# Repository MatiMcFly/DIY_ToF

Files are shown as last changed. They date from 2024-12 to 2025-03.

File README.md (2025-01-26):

# DIY ToF

Copyright (c) 2024-2025 Matthias Schär, Timon Burkard

This project is about creating a DIY (Do-It-Yourself) optical ToF (Time of Flight) distance measurement system.

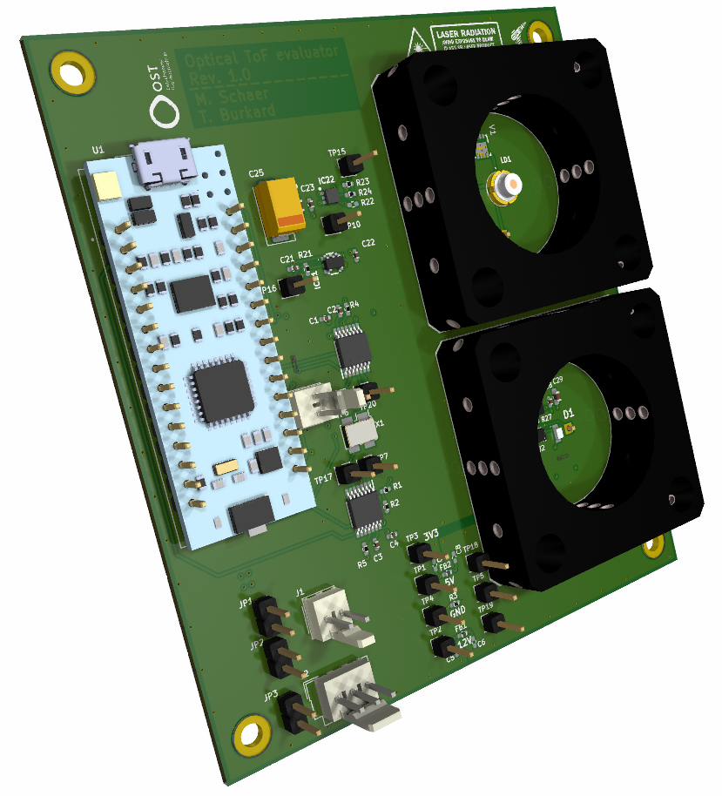
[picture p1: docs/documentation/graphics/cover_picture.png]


It is a project work as part of the CAS (Certificate of Advanced Studies) in Sensors and Sensor Signal Conditioning, which is held at OST (Ostschweizer Fachhochschule) in Rapperswil CH.

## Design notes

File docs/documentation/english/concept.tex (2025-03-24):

The following subchapters explain the development work necessary for the implementation of the \acrshort{tof} demonstrator.
In particular, they discuss how the electronics can be constructed. In addition, further
challenges of such a system and how they can be overcome are shown.

\subsection{Signal chain}

Some explanations can be found below on how the \acrshort{tof} measurement is realized.

A block diagram of the overall project, consisting of the electrical and the optical part, is shown in
Figure~\ref{fig:blockdiagram}.

\begin{figure}[H]
    \centering
    
    \caption{Block diagram}\label{fig:blockdiagram}
\end{figure}

A more detailed sketch of the optical signal chain can be seen in the figure~\ref{fig:konzept_signalpfad}.

\begin{figure}[H]
    \centering
    
    \caption{Conceptual signal path}\label{fig:konzept_signalpfad}
\end{figure}

An \acrshort{mcu} takes care of starting and evaluating the measurement results. Generating a start signal
a laser diode is triggered by a laser driver. This pulse, in the form of a light pulse after the laser diode,
is then reflected by a target that is at a variable distance from the electronics.

The reflected light pulse is focused by an optical system and then converted into a photocurrent. This photocurrent is
converted into a voltage by a transimpedance amplifier. Before the \acrshort{mcu} can evaluate this voltage, it must
first be digitized. This is done using a comparator. This can be understood as a 1-bit \acrshort{adc}, since only a
distinction between the two states \dq light\dq\ and \dq no light\dq\ is necessary. The result is a received pulse.

If the time between the start signal and the received pulse is measured, it is possible to draw a conclusion about the variable
distance between the electronics and the target. The time measurement is subject to the highest requirements. As
symbolization: light travels a distance of 30 cm within a nanosecond. The next subchapter explains how such a time measurement
can be realized.

\subsection{Time measurement}

In order for a direct \acrshort{tof} signal to be evaluated, it requires a high-resolution
time measurement. The TDC7200 from Texas Instruments offers a good solution for this.
According to the data sheet \cite{ti2016tdc7200_datasheet}, it can resolve up to 55 ps with a
standard deviation of 35 ps. If we now insert the speed of light and this minimum
temporal resolution in a motion equation, the module should achieve the following spatial resolution according to the formula~\ref{eq:tdc_max_resolution}:

\begin{equation}\label{eq:tdc_max_resolution}
    s_{min} = c \cdot t = 299.8 \cdot 10^6~\frac{m}{s} \cdot 55~ps = 16.5~mm
\end{equation}
\myequations{Maximum spatial resolution of the TDC7200}

In principle, the \acrshort{tof} functionality should be put into operation in two steps.
In the first part, the aim is purely to get to know the TDC7200 \acrshort{ic} better.

Note: In reality, such a resolution will not be achievable. The challenges
consist, for example, in the fact that various delays are present in the entire signal chain.
For example, the switching on of the laser diode, the bandwidth of the amplifier and
the switching time of the comparator play a major role. Also, the jitter of the \acrshort{mcu} when switching on and off
of their outputs will be important at the minimum resolution. In the chapter~\ref{sec:electrical_measurements},
various measurements are used to show how close the TDC7200's specified limit is approached.

\subsection{Approach}\label{sec:approach}

As already explained, it can be assumed that the entire signal path introduces an inaccuracy into the measurement that
is far outside that of the TDC7200. It therefore makes sense to examine this in advance.
For this purpose, a second TDC7200 is used on the electronics, which is responsible for measuring a purely electrical signal
.
\begin{figure}[H]
    \centering
    
    \caption{Concept operation \acrshort{tdc} purely electric}\label{fig:konzept_tdc_electrical}
\end{figure}

Figure~\ref{fig:konzept_tdc_electrical} shows a possible design for such a circuit. The wavy
red line symbolizes a variable measurement path. Cables of different lengths can be connected here via a plug.
This makes it possible to verify the measurement accuracy of the TDC7200 purely electrically.

The following points can be checked with such an extension:

\begin{itemize}
    \item Measurement of jitter at the \acrshort{mcu} outputs
    \item Configuration and operation of the TDC7200 (e.g. different measurement modes)
    \item Evaluation of the TDC7200 results
\end{itemize}

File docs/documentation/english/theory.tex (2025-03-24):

The following subchapters develop the theoretical foundations necessary for understanding and
designing a demonstrator for the \acrshort{tof} method.

\subsection{Time of Flight}

The measurement method known as \dq \acrlong{tof}\dq\ involves measuring the transit time of a signal.
The signal can be either optical or acoustic. One application of this is, for example, distance measurement.

In the optical principle discussed here, a transmitter emits light that is detected by a receiver.
A time measurement can be made between the sending and receiving of the signal. Because light propagates at a defined
speed, this time measurement can be used to determine the distance
the signal has traveled within the measured time.

\begin{figure}[H]
    \centering
    
    \caption{Visualization of a: direct \acrshort{tof} and b: indirect \acrshort{tof}}\label{fig:dtof_vs_itof}
\end{figure}

There are two types of \acrshort{tof}: direct \acrshort{tof} (dToF) and indirect \acrshort{tof} (iToF). With dToF
only the time between the transmission and reception pulse is determined. In the figure~\ref{fig:dtof_vs_itof},
such pulses are shown at a).

In iToF, the phase shift of a modulated light signal is also measured (in some cases additionally) to the runtime measurement.
This is shown in figure~\ref{fig:dtof_vs_itof} in part b). This method allows higher resolutions to
be achieved, but is much more complex in terms of evaluation and signal processing.

This work is limited to the direct \acrshort{tof} method.

In the following, the theoretical principles, especially with regard to designing a suitable optical system, are discussed.

\pagebreak

\subsection{Photocurrent}

To calculate the theoretically expected photocurrent, a distance of $10~m$ from the wall is assumed.

In a simplified consideration, a laser beam with a divergence of $0\degree$ hits a wall at right angles
and is scattered uniformly in a hemisphere. In reality, the laser will not hit the wall at $0\degree$ and
the scattering will not be uniform, but rather more concentrated in the center.

The calculation of the received radiant power, the radiant intensity, the solid angle of a hemisphere, and the
photocurrent are shown in formulas~\ref{eq:pin}, \ref{eq:ie}, \ref{eq:omega} and \ref{eq:iph}, respectively.

\begin{equation}\label{eq:pin}
    P_{in} = E_e \cdot A = \frac{I_e}{r^2} \cdot A
\end{equation}
\myequations{Incoming light power}

\begin{equation}\label{eq:ie}
    I_e = \frac{P_{out}}{\Omega}
\end{equation}
\myequations{Radiation intensity}

\begin{equation}\label{eq:omega}
    \Omega = 4\cdot \pi \cdot 0.5
\end{equation}
\myequations{solid angle}

\begin{equation}\label{eq:iph}
    I_{ph} = S \cdot P_{in}
\end{equation}
\myequations{photocurrent}

\subsubsection{Calculation with RLD94PZJ5 and BPV23NF}

Initial calculations are carried out with the RLD94PZJ5 laser diode \cite{rohm2020rld94pzj5_datasheet} and the BPV23NF photodiode
\cite{vishay2024bpv23nf_datasheet}.

The relevant values from the data sheets are listed in formula~\ref{eq:rld94pzj5_num} and \ref{eq:rbpv23nf_num}.

\begin{equation}\label{eq:rld94pzj5_num}
    P_{out} = 285~mW
\end{equation}
\myequations{Values of the RLD94PZJ5}

\begin{equation}\label{eq:rbpv23nf_num}
    \begin{split}
        A & = 4.4~mm^2        \\
        S & = 0.6~\frac{A}{W}
    \end{split}
\end{equation}
\myequations{Values of BPV23NF}

These values inserted in formula~\ref{eq:ie}, \ref{eq:pin} and \ref{eq:iph} yield the results in
formula~\ref{eq:rld94pzj5_rbpv23nf_num}.

\begin{equation}\label{eq:rld94pzj5_rbpv23nf_num}
    \begin{split}
        I_e    & = \frac{P_{out}}{\Omega} = \frac{285~mW}{4\cdot \pi \cdot 0.5~sr} = 45.4~\frac{mW}{sr} \\
        P_{in} & = \frac{I_e}{r^2} \cdot A = \frac{45.4~\frac{mW}{sr}}{(10~m)^2} \cdot 4.4~mm^2 = 2~nW  \\
        I_{ph} & = S \cdot P_{in} = 0.6~\frac{A}{W} \cdot 2~nW = 1.2~nA
    \end{split}
\end{equation}
\myequations{Numerical results with RLD94PZJ5 and BPV23NF}

\subsubsection{Calculation with RLD65NZX1 and NJL6401R-3}

The laser diode RLD94PZJ5 has two disadvantages with regard to this project work: on the one hand, it has such a high power that
it can be harmful to the human eye. On the other hand, it emits in a wavelength range that
is not visible to the human eye.

For these reasons, a second laser diode is being evaluated: RLD65NZX1 \cite{rohm2019rld65nzx1_datasheet}. It is paired
with the photodiode NJL6401R-3 \cite{jrc2014njl6401r3_datasheet}. The following calculations are based on
these two components.

The relevant values from the data sheets are listed in formula~\ref{eq:rld65nzx1_num} and \ref{eq:njl6401r3_num}.

\begin{equation}\label{eq:rld65nzx1_num}
    P_{out} = 10~mW
\end{equation}
\myequations{Values of the RLD65NZX1}

\begin{equation}\label{eq:njl6401r3_num}
    \begin{split}
        A & = 0.7~mm \cdot 0.7~mm = 0.49~mm^2 \\
        S & = 0.42~\frac{A}{W}
    \end{split}
\end{equation}
\myequations{Values of NJL6401R-3}

Inserted into the formulas~\ref{eq:ie}, \ref{eq:pin} and \ref{eq:iph} the new results in
formula~\ref{eq:rld65nzx1_njl6401r3_num}.

\begin{equation}\label{eq:rld65nzx1_njl6401r3_num}
    \begin{split}
        I_e    & = \frac{P_{out}}{\Omega} = \frac{10~mW}{4\cdot \pi \cdot 0.5~sr} = 1.59~\frac{mW}{sr}    \\
        P_{in} & = \frac{I_e}{r^2} \cdot A = \frac{1.59~\frac{mW}{sr}}{(10~m)^2} \cdot 0.49~mm^2 = 7.8~pW \\
        I_{ph} & = S \cdot P_{in} = 0.42~\frac{A}{W} \cdot 7.8~pW = 3.28~pA
    \end{split}
\end{equation}
\myequations{Numerical results with RLD65NZX1 and NJL6401R-3}

\subsubsection{Calculation with receiving lens}

At the suggestion of the lecturers, various optics from a modular system from QIOPTIQ are being tried out.
A lens with a diameter of 17~mm and a focal length of
40~mm appears to be particularly promising. The lens is shown in Figure~\ref{fig:lens}.

\begin{figure}[H]
    \centering
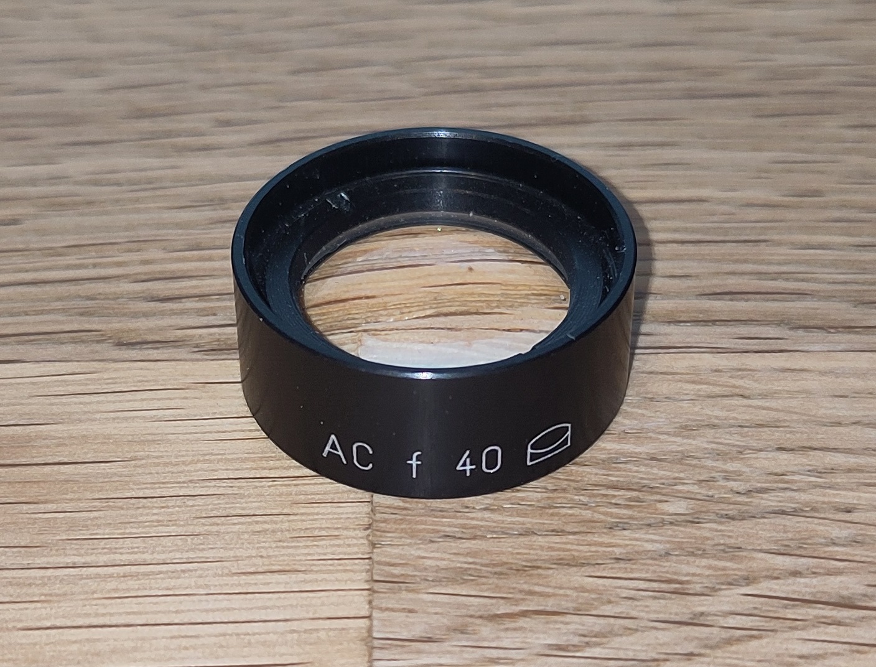
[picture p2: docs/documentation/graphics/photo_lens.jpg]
    
    \caption{Lens from QIOPTIQ}\label{fig:lens}
\end{figure}

This lens enlarges the effective area on which the photocurrent can be received. This results in
higher reception power, i.e. a higher photocurrent.
The formula~\ref{eq:njl6401r3_lens} shows the increase in area to be expected when using such an optical system.

\begin{equation}\label{eq:njl6401r3_lens}
    A' = \frac{A_{L}}{A_{PD}} = \frac{(\frac{17~mm}{2})^2 \cdot \pi}{0.49~mm^2} = 463.2
\end{equation}
\myequations{Magnification of the receiving area by lens}

\subsubsection{Expected photocurrent}

Two scenarios are considered below: In the first, it is assumed, as before, that the light from the laser
propagates in a focused beam and then reflects off the target in a hemispherical and diffuse manner.

In the second scenario, an attempt is made to model the radiation pattern of the laser diode. According to the data sheet, the
diode has two different beam angles in the beam plane, which can be approximated with the solid angle of a rectangular pyramid.
Scattering is prevented because the beam is reflected by a mirror.

In both scenarios, the radiated power of the laser diode is higher than in the first calculation. In pulsed
operation, this can easily be increased above the maximum rating. Thermally, this does not pose a problem for the diode because
the duty cycle is very small. The formula~\ref{eq:rld65nzx1_higher_output} shows the new expected radiant power
of such a pulse. The efficiency of the laser diode is taken from the RLD65NZX1 data sheet \cite{rohm2019rld65nzx1_datasheet}.

\begin{equation}\label{eq:rld65nzx1_higher_output}
    \begin{split}
        \eta     & = \frac{P_{25~mA}}{I_{ld}} = \frac{7~mW}{25~mA} = 0.28~\frac{W}{A}   \\
        I_{ld}'  & = \frac{5~V - V_{LD}}{R_{v}} = \frac{5~V - 2.8~V}{5~\Omega} = 440~mA \\
        P_{out}' & = \eta \cdot I_{ld}' = 0.28~\frac{W}{A} \cdot 440~mA = 123~mW
    \end{split}
\end{equation}
\myequations{Increased transmission power of the laser diode}

For a target located at a distance of 2 meters, the following
photocurrent can be expected according to formula~\ref{eq:photocurrent_scenario1}:

\begin{equation}\label{eq:photocurrent_scenario1}
    \begin{split}
        P_{in} & = \frac{P_{out}}{\Omega \cdot r^2} \cdot A_{L} = \frac{123~mW}{4\pi \cdot 0.5~sr \cdot (2~m)^2} \cdot 227~mm^2 = 1.11~\mu W \\
        I_{ph} & = S \cdot P_{in} = 0.42~\frac{A}{W} \cdot 1.11~\mu W = 467~nA
    \end{split}
\end{equation}
\myequations{Photocurrent scenario 1}

Without optics, the laser diode does not emit a collimated beam. In the second scenario, this radiation pattern is modeled using
the solid angle of a pyramid, as defined in formula~\ref{eq:solid_angle_pyramid}. The typical
radiation angles $\theta$ are also taken from the laser diode data sheet. It should be noted that the
full angle is given in the data sheet. The value in the formula is therefore halved.

\begin{equation}\label{eq:solid_angle_pyramid}
    \Omega_{P} = 4 \cdot arcsin(sin(\theta_x) \cdot sin(\theta_y)) =  4 \cdot arcsin \parenth*{sin \parenth*{\frac{9\degree}{2}} \cdot sin \parenth*{\frac{29\degree}{2}}} = 4.2~sr
\end{equation}
\myequations{Laser diode radiation model}

The formula~\ref{eq:photocurrent_scenario2} is used again to calculate the expected received power and the corresponding
photocurrent. However, the difference to the previous calculation is that the solid angle must also be
taken into account before reflection. Therefore, the distance to the target is multiplied by two.

\begin{equation}\label{eq:photocurrent_scenario2}
    \begin{split}
        P_{in} & = \frac{P_{out}}{\Omega \cdot (2 \cdot r)^2} \cdot A_{L} = \frac{123~mW}{4.2~sr \cdot (2 \cdot 2~m)^2} \cdot 227~mm^2 = 416~nW \\
        I_{ph} & = S \cdot P_{in} = 0.42~\frac{A}{W} \cdot 416~nW = 175~nA
    \end{split}
\end{equation}
\myequations{Photocurrent scenario 2}

\pagebreak

\subsection{Transimpedance amplifier}

As the calculations in the previous chapters show, the photocurrents to be detected have very small
amplitudes. Furthermore, the light pulses are typically only of very short duration, namely in the range of a few nanoseconds.
As a result, the signals have correspondingly short rise times, which need to be detected.

The requirements indicate that an amplifier with a very high gain and a very high bandwidth must be used.
The amplifier circuit used is a current-to-voltage converter. Such a circuit of the operational amplifier,
as shown in Figure~\ref{fig:theory_tia}, is also called a transimpedance amplifier (\acrshort{tia}).

\begin{figure}[H]
    \centering
    
    \caption{Operational amplifier circuit as a \acrshort{tia}}\label{fig:theory_tia}
\end{figure}

As the name suggests, the transimpedance converter converts the photocurrent \lstinline|Id| into a voltage \lstinline|Vout|.
The feedback resistor \lstinline|Rf| determines the amplification factor, as the formula~\ref{eq:tia_simple}
shows:

\begin{equation}\label{eq:tia_simple}
    V_{out} = -R_{f} \cdot I_{d}
\end{equation}
\myequations{Übertragungsfunktion \acrshort{tia}}

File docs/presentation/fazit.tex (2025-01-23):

\begin{frame}{Ausblick}
    \begin{itemize}
        \item Optik besser aufeinander abstimmen, andere Brennweiten ausprobieren
        \item Jitter minimieren (höherer Clock oder externen Clock)
        \item GPIOs schneller schalten
        \item Optischer Empfangspfad
        \begin{itemize}
            \item Unterschiedliche Verstärkungen TIA
            \item Unterschiedliche Schaltschwellen Komparator
        \end{itemize}
        \item Optischer Sendepfad: Höhere Sendeleistung ausprobieren
        \item Analyse optischer Resultate: Wieso zwei Cluster?
        \item Mechanischen Versuchsaufbau für Spiegel
    \end{itemize}
\end{frame}

\begin{frame}{Lessons Learned}
    \begin{itemize}
        \item Insgesamt sehr zufrieden
        \item Viel Neues gelernt
        \item Leider etwas wenig Zeit
        \item Zeitliche Auflösung weniger ein Problem als empfangene Lichtmenge
        \item[$\Rightarrow$] Mehr Zeit in Optik und Optoelektronik investieren
    \end{itemize}
\end{frame}

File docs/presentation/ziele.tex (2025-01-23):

\begin{frame}{Zielsetzung}
    \begin{itemize}
        \item ToF-Demonstrator entwickeln
        \begin{itemize}
            \item Eigenes PCB mit 2x TDC7200
        \end{itemize}
        \item Erster Schritt: Kabellängen vermessen
        \item Zweiter Schritt: Optische Messung
        \begin{itemize}
            \item Distanz: 10 m
            \item Auflösung: 30 cm
        \end{itemize}
    \end{itemize}
\end{frame}

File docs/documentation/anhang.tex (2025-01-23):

\subsection{Outline}\label{sec:outline}

\begin{figure}[H]
    \centering
    
    \caption{Outline}\label{fig:outline}
\end{figure}

\subsection{TDC Treiber}\label{sec:tdc_driver}

In Code~\ref{code:tdc_driver_header} und \ref{code:tdc_driver_source} ist der selbst entwickelte Firmware-Treiber für
den \acrshort{tdc} dargestellt.

\lstinputlisting[language={c}, label={code:tdc_driver_header}, caption={\acrshort{tdc} Driver (Header)}]{../../firmware/Core/TDC/TDC.h}
\lstinputlisting[language={c}, label={code:tdc_driver_source}, caption={\acrshort{tdc} Driver (Source)}]{../../firmware/Core/TDC/TDC.c}

\subsection{Python Skripte}\label{sec:python_scripts}

In Code \ref{code:python_analyze} ist das Python-Skript zur Berechnung des arithmetischen Mittelwerts und der
Standardabweichung sowie zum Plotten des Histogramms und des Boxplots dargestellt.

\lstinputlisting[language={python}, label={code:python_analyze}, caption={Python Analyse}]{../../utilities/analyze-tof.py}

In Code \ref{code:python_analyze_multi_tofs} ist das Python-Skript zur Berechnung des arithmetischen Mittelwerts und der
Standardabweichung sowie zum Plotten der Werte für mehrere \acrshort{tof}-Datensätze dargestellt.

\lstinputlisting[language={python}, label={code:python_analyze_multi_tofs}, caption={Python Analyse (Multi \acrshort{tof}s)}]{../../utilities/analyze-tofs.py}

In Code \ref{code:python_analyze_multi_logs} ist das Python-Skript zum Plotten der Werte aus mehreren Log-Files
dargestellt.

\lstinputlisting[language={python}, label={code:python_analyze_multi_logs}, caption={Python Analyse (Multi Logs)}]{../../utilities/analyze-tofs-multi-logs.py}

In Code \ref{code:python_live_plot} ist das Python-Skript zum live Plotten von \acrshort{tof}-Werte dargestellt. Dieses
wird während der Präsentation für die Demonstration verwendet.

\lstinputlisting[language={python}, label={code:python_live_plot}, caption={Python Live Plot}]{../../utilities/live-plot.py}

\pagebreak

\begin{landscape}

    \subsection{Schema}\label{sec:schematic_apdx}
    \global\pdfpageattr\expandafter{\the\pdfpageattr/Rotate 90}
    \begin{figure}[H]
        \centering
        
        \caption{Schema S.1/3}\label{fig:schematics_1}
    \end{figure}
    \pagebreak

    \global\pdfpageattr\expandafter{\the\pdfpageattr/Rotate 90}
    \begin{figure}[H]
        \centering
        
        \caption{Schema S.2/3}\label{fig:schematics_2}
    \end{figure}
    \pagebreak

    \global\pdfpageattr\expandafter{\the\pdfpageattr/Rotate 90}
    \begin{figure}[H]
        \centering
        
        \caption{Schema S.3/3}\label{fig:schematics_3}
    \end{figure}
    \pagebreak

    \subsection{Stückliste}

    \begin{table}[H]
        \scriptsize
        \mytable
            {|l|l|l|l|l|l|}
            {\textbf{Reference} & \textbf{Value} & \textbf{Datasheet} & \textbf{Footprint} & \textbf{Qty} & \textbf{DNP}}
            {\Reference & \Value & \Datasheet & \Footprint & \Qty & \DNP}
            {tables/bom.csv}
        \caption{Bill of Material}\label{tab:bom}
    \end{table}

\end{landscape}
\global\pdfpageattr\expandafter{\the\pdfpageattr/Rotate 0}

\subsection{Layout}\label{sec:apdx_layout}

\begin{figure}[H]
    \centering
    
    \caption{PCB Layout Top}\label{fig:apdx_pcb_f_cu}
\end{figure}

\begin{figure}[H]
    \centering
    
    \caption{PCB Layout Innen 1}\label{fig:apdx_pcb_in1_cu}
\end{figure}

\begin{figure}[H]
    \centering
    
    \caption{PCB Layout Innen 2}\label{fig:apdx_pcb_in2_cu}
\end{figure}

\begin{figure}[H]
    \centering
    
    \caption{PCB Layout Bottom}\label{fig:apdx_pcb_b_cu}
\end{figure}

\subsection{Komponenten-Platzierung}\label{sec:apdx_placement}

\begin{figure}[H]
    \centering
    
    \caption{PCB Komponenten-Platzierung Top}\label{fig:apdx_pcb_placement_1}
\end{figure}

\begin{figure}[H]
    \centering
    
    \caption{PCB Komponenten-Platzierung Bottom}\label{fig:apdx_pcb_placement_2}
\end{figure}
\pagebreak

\subsection{3D View}\label{sec:apdx_3D_view}

\begin{figure}[H]
    \centering
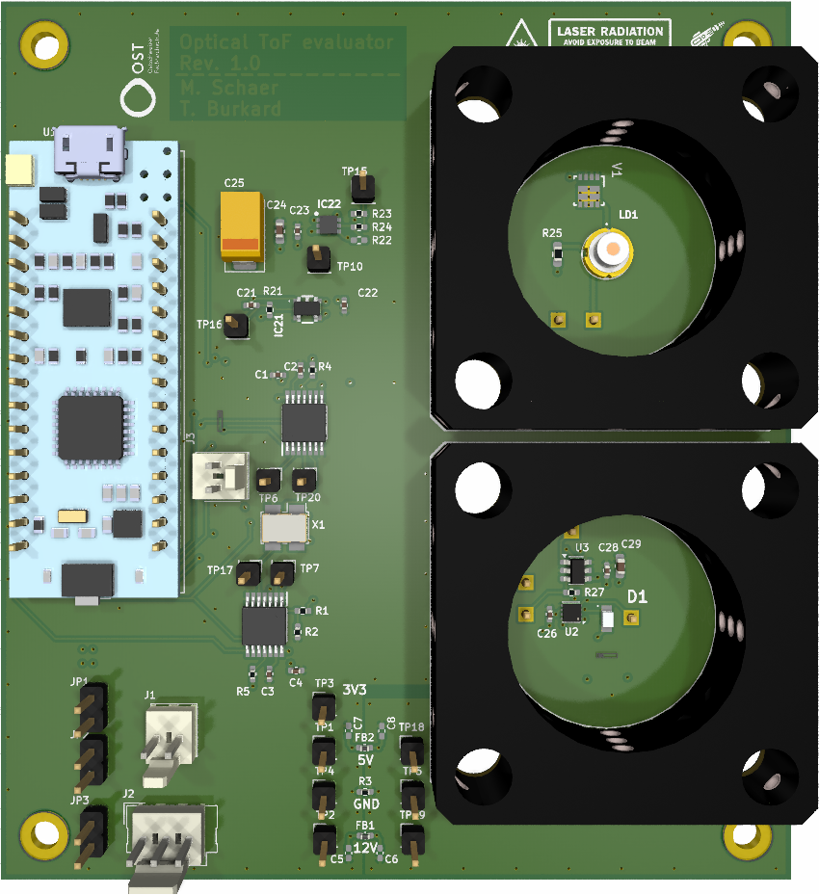
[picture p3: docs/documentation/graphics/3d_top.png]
    
    \caption{3D View Top}\label{fig:apdx_3d_top}
\end{figure}

\begin{figure}[H]
    \centering
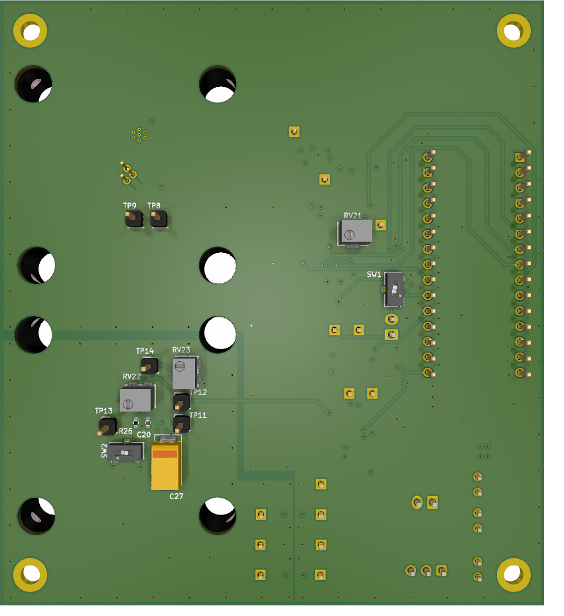
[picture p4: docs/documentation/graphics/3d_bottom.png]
    
    \caption{3D View Bottom}\label{fig:apdx_3d_bottom}
\end{figure}

\subsection{Fotos Demonstrator}\label{sec:apdx_photos_demonstrator}

\begin{figure}[H]
    \centering
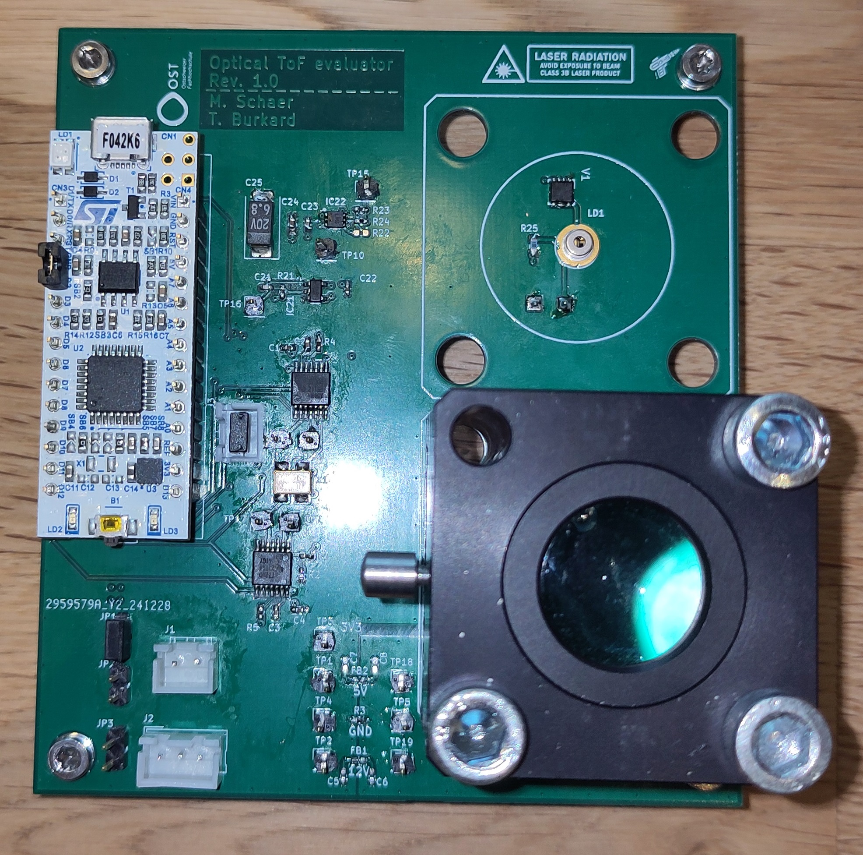
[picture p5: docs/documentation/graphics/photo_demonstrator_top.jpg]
    
    \caption{Demonstrator von oben}\label{fig:apdx_photo_demonstrator_top}
\end{figure}

\begin{figure}[H]
    \centering
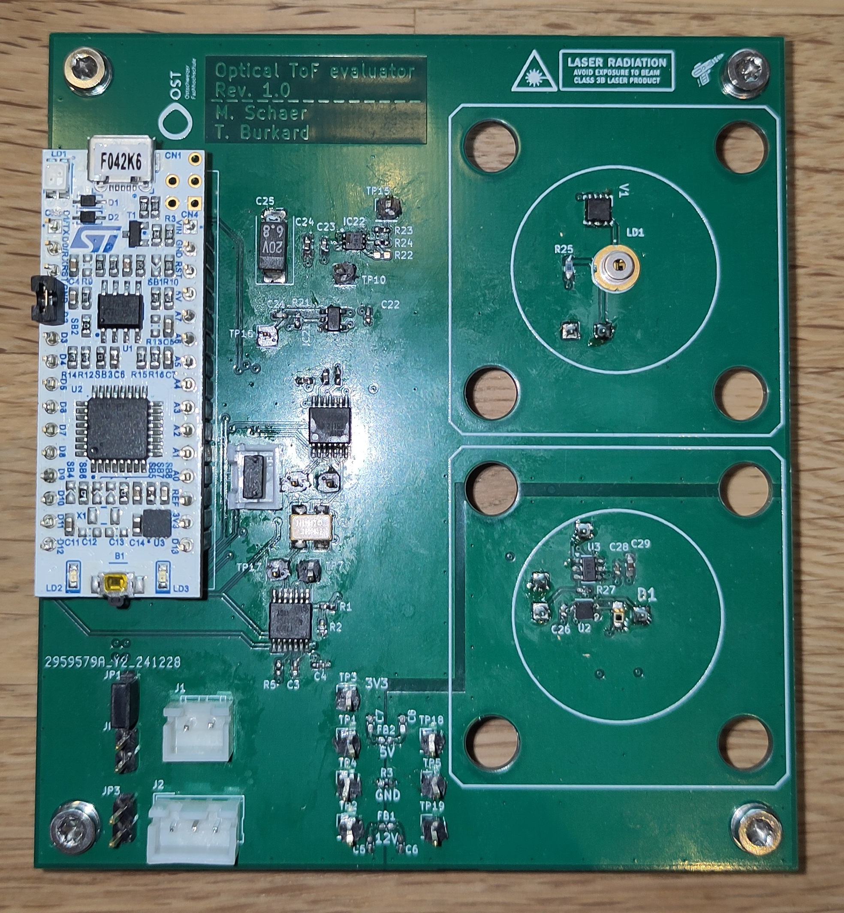
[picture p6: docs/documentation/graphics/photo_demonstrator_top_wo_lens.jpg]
    
    \caption{Demonstrator von oben ohne Linse}\label{fig:apdx_photo_demonstrator_top_wo_lens}
\end{figure}

\begin{figure}[H]
    \centering
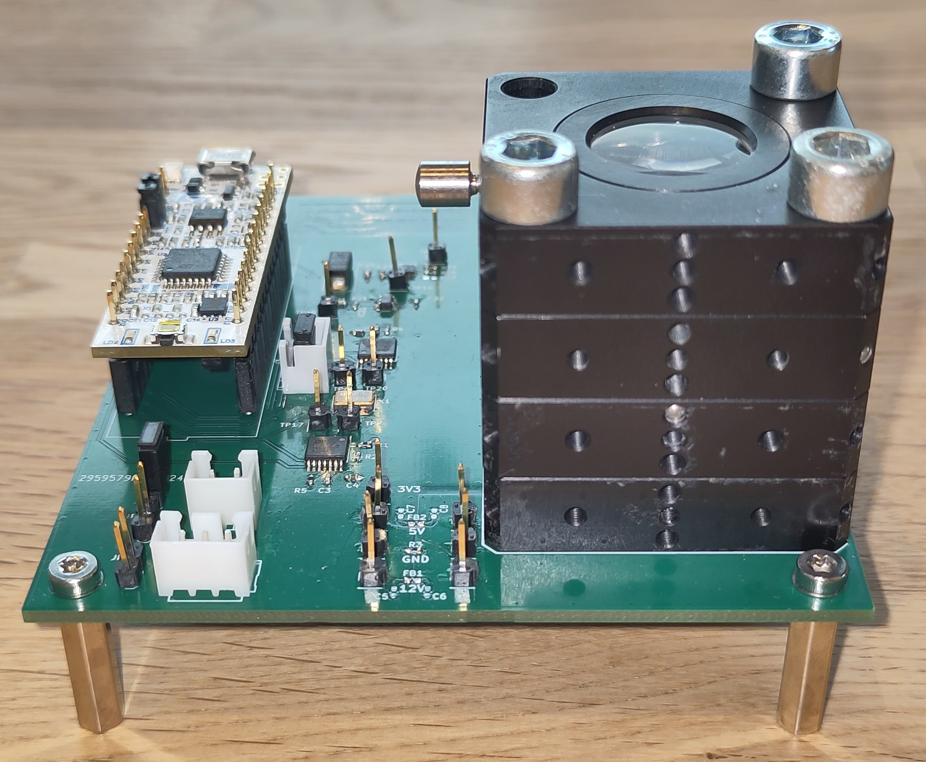
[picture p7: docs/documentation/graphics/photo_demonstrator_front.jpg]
    
    \caption{Demonstrator von vorne}\label{fig:apdx_photo_demonstrator_front}
\end{figure}

\begin{figure}[H]
    \centering
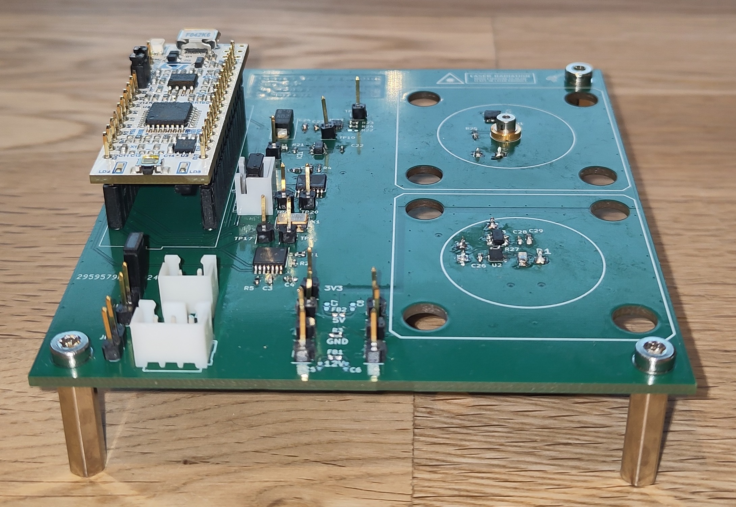
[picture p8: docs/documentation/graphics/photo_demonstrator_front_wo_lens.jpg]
    
    \caption{Demonstrator von vorne ohne Linse}\label{fig:apdx_photo_demonstrator_front_wo_lens}
\end{figure}

\begin{figure}[H]
    \centering
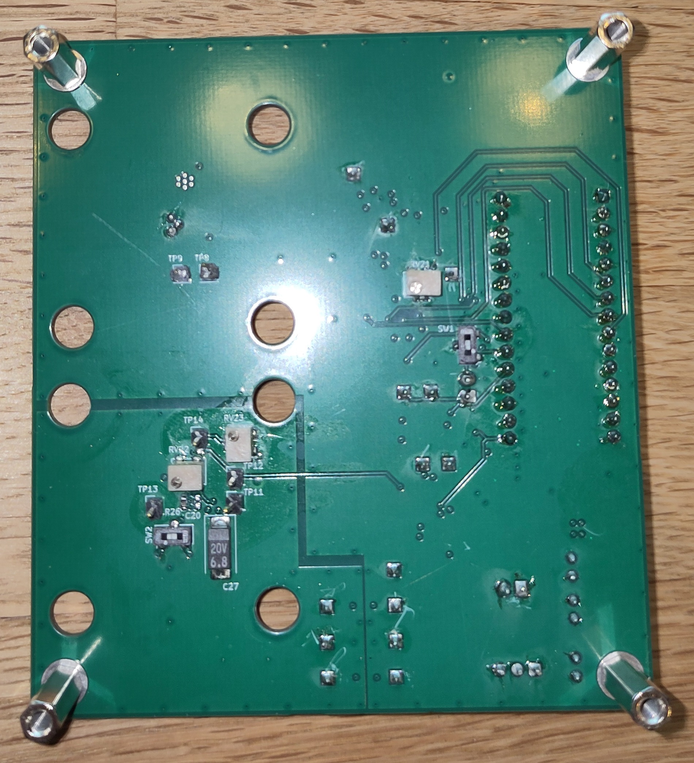
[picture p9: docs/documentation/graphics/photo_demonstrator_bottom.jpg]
    
    \caption{Demonstrator von unten}\label{fig:apdx_photo_demonstrator_bottom}
\end{figure}

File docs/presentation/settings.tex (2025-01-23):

\usetheme{Frankfurt}
\usecolortheme{default}

\usepackage[ngerman]{babel}
\usepackage[square,numbers,super]{natbib}
\usepackage{listings}
\usepackage{textpos}
\usepackage{tabto}
\usepackage{caption}
\usepackage{fbox}                     % to add border to figures, if needed
\usepackage{tikz}                     % to place red rounded boxes to highlight spots
\usepackage{xcolor}
\usepackage{xpatch}                   % to add grey background to \lstinline
\usepackage{realboxes}                % to add grey background to \lstinline
\usepackage{calc}                     % used for \rightHeaderWidth
\usepackage{varwidth}                 % used for \rightHeaderWidth
\usepackage{lmodern}                  % used for \setlistspacing
\usepackage[export]{adjustbox}        % used to left/right align graphics in a figure
\usepackage[normalem]{ulem}           % used to strike through text: \sout{}
\usepackage[inkscapelatex=false]{svg} % used to include svg with the help of inkscape which converts svg to pdf (inkscapelatex=false: prevent latex from changing the font within the svg graphic)
\usepackage[loop,autoplay]{animate}   % used to insert GIF animations with the help op ImageMagick which converts gif to multiple png
\usepackage{mathtools}                % used for DeclarePairedDelimiter
\usepackage{amsmath}                  % needed for amssymb
\usepackage{amssymb}                  % used for \circledast
\usepackage{trfsigns}                 % transformation signs for fourier and laplace
\usepackage{csvsimple}                % for using csv-files for tables

\makeatletter
\newcommand{\setlistspacing}[2]{\def\@ld{#1}\expandafter\def\csname
@list\romannumeral\@ld\endcsname{\leftmargin\csname
leftmargin\romannumeral\@ld\endcsname
              \topsep#2
              \parsep0\p@ \@plus\p@
              \itemsep#2}}
\makeatother
\setlistspacing{1}{4ex}

\captionsetup{labelformat=empty,labelsep=none,font=scriptsize} % don't show caption label only caption text

\renewcommand{\bibsection}{} % don't create a section for bibliography

\urlstyle{same} % use text font for URLs
\renewcommand\UrlFont{\color{blue}} % make URLs blue

\definecolor{darkblue}{rgb}{0.05, 0.13, 0.28}
\definecolor{grey}{rgb}{0.4, 0.5, 0.6}
\definecolor{black}{rgb}{0, 0, 0}

\setbeamercolor{palette primary}{bg=darkblue,fg=white}
\setbeamercolor{palette secondary}{bg=darkblue,fg=white}
\setbeamercolor{palette tertiary}{bg=darkblue,fg=white}
\setbeamercolor{palette quaternary}{bg=black,fg=white}
\setbeamercolor{structure}{fg=darkblue} % itemize, enumerate, etc
\setbeamercolor{section in toc}{fg=darkblue}
\setbeamercolor{caption name}{fg=black}

\setbeamercolor{subsection}{bg=grey,fg=white}
\setbeamercolor{subsection in head/foot}{bg=grey,fg=white}

\setbeamertemplate{navigation symbols}{} % hides navigation buttons at bottom

\makeatletter
\setbeamertemplate{footline}
{
    \leavevmode%
    \hbox{%
    \begin{beamercolorbox}[wd=.5\paperwidth,ht=2.25ex,dp=1ex,right]{author in head/foot}%
        \usebeamerfont{author in head/foot}\insertauthor\hspace*{2ex}
    \end{beamercolorbox}%
    \begin{beamercolorbox}[wd=.4\paperwidth,ht=2.25ex,dp=1ex,left]{subsection in head/foot}%
        \hspace*{2ex}\usebeamerfont{title in head/foot}\inserttitle{}
    \end{beamercolorbox}%
    \begin{beamercolorbox}[wd=.1\paperwidth,ht=2.25ex,dp=1ex,right]{subsection in head/foot}%
        \usebeamerfont{title in head/foot}\insertframenumber{} / \inserttotalframenumber\hspace*{2ex}
    \end{beamercolorbox}}%
    \vskip0pt%
}
\makeatother

\setbeamerfont{date}{size=\scriptsize}
\setbeamerfont{institute}{size=\normalfont}
\setbeamerfont{subsection}{size=\large}

\hypersetup{
    colorlinks=true,
    urlcolor=blue,
    linkcolor=.,
    anchorcolor=.,
    citecolor=.,
    filecolor=.
}

\defbeamertemplate*{title page}{customized}[1][]
{
    \begin{beamercolorbox}[sep=8pt,center,shadow=true,rounded=true]{title}
        \usebeamerfont{title}\inserttitle\par%
    \end{beamercolorbox}

    \centering

    \vspace{30pt}

    \usebeamerfont{institute}\insertinstitute\par

    \vspace{10pt}

    \footnotesize{\vModule}

    \vspace{30pt}

    \usebeamerfont{author}\insertauthor\par

    \vspace{40pt}

    \usebeamerfont{date}\insertdate\par
}

\newcommand{\rightHeaderWidth}[0]
{
    \widthof{
        \fbox{
            \begin{varwidth}{\textwidth}
                \tiny{\insertshortinstitute{}}
                \tiny{\vModule}
            \end{varwidth}
        }
    }
}

\addtobeamertemplate{frametitle}{}{%
    \begin{textblock*}{100mm} (153mm-\rightHeaderWidth{},-7.2mm)
        \tiny{\insertshortinstitute{}}
        \vspace{2pt}
        \tiny{\vModule}
    \end{textblock*}}

\AtBeginSection[]{
    \begin{frame}
    \vfill
    \centering
    \begin{beamercolorbox}[sep=8pt,center,shadow=true,rounded=true]{title}
        \usebeamerfont{title}\insertsectionhead\par%
    \end{beamercolorbox}
    \vfill
    \end{frame}
}

\AtBeginSubsection[]{
    \begin{frame}
    \vfill
    \centering
    \begin{beamercolorbox}[sep=8pt,center,shadow=true,rounded=true]{title}
        \usebeamerfont{title}\insertsectionhead\par%
    \end{beamercolorbox}
    \vspace{0.5cm}
    \begin{beamercolorbox}[sep=8pt,center,shadow=true,rounded=true]{subsection}
        \usebeamerfont{subsection}\insertsubsectionhead\par%
    \end{beamercolorbox}
    \vfill
    \end{frame}
}

\setbeamertemplate{frametitle continuation}{} % deactivate roman numbering for frame with [allowframebreaks]

\setbeamercolor{block title}{bg=darkblue,fg=white}

\newcommand{\question}[1]
{
    \begin{block}{Frage}
        #1
    \end{block}
}

\newcommand{\attention}[1]
{
    \begin{alertblock}{Wichtig}
        #1
    \end{alertblock}
}

\newcommand{\exercise}[2][n]
{
    \begin{exampleblock}{Übung}
        #2
    \end{exampleblock}

    \ifx #1n
    \else
        \begin{itemize}
            \item<2->[$\Rightarrow$] Lösungen werden via GitLab zur Verfügung gestellt:
            \url{#1}
        \end{itemize}
    \fi
}

\renewcommand{\quote}[3]
{
    \begin{frame}{#1}
        \begin{block}{}
            {\emph{\dq #2\dq}}
            \vskip5mm
            \hspace*\fill{\small-- #3}
        \end{block}
    \end{frame}
}

\newcommand{\goals}[1]
{
    {
        \setlistspacing{1}{1ex}

        \begin{frame}{Ziele}
            Die Studierenden

            \begin{itemize}
                #1
            \end{itemize}

            \vspace{10pt}

            \begin{figure}
                
            \end{figure}
        \end{frame}
    }
}

\newcommand{\questions}[0]
{
    \begin{frame}{Fragen?}
        \begin{figure}
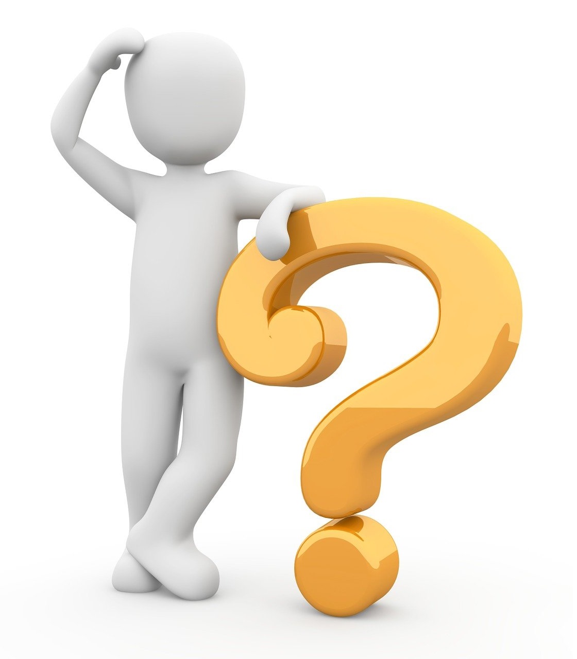
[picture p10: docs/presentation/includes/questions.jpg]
            
        \end{figure}
    \end{frame}
}

\definecolor{codegreen}{rgb}{0,0.6,0}
\definecolor{codegray}{rgb}{0.5,0.5,0.5}
\definecolor{codepurple}{rgb}{0.58,0,0.82}
\definecolor{codeorange}{rgb}{1,0.5,0.15}
\definecolor{backcolour}{rgb}{0.9,0.9,0.9}

\colorlet{codegreen_transparent}{codegreen!30}
\colorlet{codegray_transparent}{codegray!30}
\colorlet{codepurple_transparent}{codepurple!30}
\colorlet{codeorange_transparent}{codeorange!30}
\colorlet{backcolour_transparent}{backcolour!30}
\colorlet{magenta_transparent}{magenta!30}
\colorlet{red_transparent}{red!30}
\colorlet{black_transparent}{black!30}

\lstdefinestyle{mystyle}{
    language=C,
    backgroundcolor=\color{backcolour},
    commentstyle=\lst@ifdisplaystyle\color{codegreen}\fi, % don't apply for \lstinline
    keywordstyle=\lst@ifdisplaystyle\color{magenta}\fi,   % don't apply for \lstinline
    stringstyle=\lst@ifdisplaystyle\color{codepurple}\fi, % don't apply for \lstinline
    numberstyle=\tiny\color{codegray},
    basicstyle=\ttfamily\scriptsize,
    breakatwhitespace=false,
    breaklines=true,
    captionpos=b,
    keepspaces=true,
    numbers=left,
    numbersep=5pt,
    showspaces=false,
    showstringspaces=false,
    showtabs=false,
    tabsize=4,
    morekeywords={int8_t, uint8_t, int16_t, uint16_t, int32_t, uint32_t, int64_t, uint64_t, bool, true, false},
    moredelim=[is][\color{red}]{§}{§}
}
\lstset{style=mystyle}

\lstset{
    literate={~} {$\sim$}{1},
    breaklines=true,
    breakatwhitespace=true,
    upquote=true, % straight single quotes
}

\lstdefinestyle{transparent}{
    language=C,
    backgroundcolor=\color{backcolour_transparent},
    commentstyle=\lst@ifdisplaystyle\color{codegreen_transparent}\fi, % don't apply for \lstinline
    keywordstyle=\lst@ifdisplaystyle\color{magenta_transparent}\fi,   % don't apply for \lstinline
    stringstyle=\lst@ifdisplaystyle\color{codepurple_transparent}\fi, % don't apply for \lstinline
    numberstyle=\tiny\color{codegray_transparent},
    basicstyle=\ttfamily\scriptsize\color{black_transparent}
    breakatwhitespace=false,
    breaklines=true,
    captionpos=b,
    keepspaces=true,
    numbers=left,
    numbersep=5pt,
    showspaces=false,
    showstringspaces=false,
    showtabs=false,
    tabsize=4,
    morekeywords={int8_t, uint8_t, int16_t, uint16_t, int32_t, uint32_t, int64_t, uint64_t, bool, true, false},
    moredelim=[is][\color{red_transparent}]{§}{§}
}

\newcommand{\sidecaption}[1]
{
    \begin{minipage}{0.05\textwidth}%
        \caption{#1}
    \end{minipage}
}

% \highlight[color]{x1,y1}{x2,y2}
% Places a rounded rectangle at an absolute position on the page.
% Arguments:
%   #1 (optional) - Color of the rectangle (defaults to red)
%   #2            - Coordinates (x,y) of first rectangle corner
%   #3            - Coordinates (x,y) of second rectangle corner
\newcommand{\highlight}[3][red]
{
    \begin{tikzpicture}[overlay]
        \draw[#1, rounded corners, thick] (#2) rectangle (#3) {};
    \end{tikzpicture}
}

% \textbox[color]{x,y}{text}
% Places a text box at an absolute position on the page.
% Arguments:
%   #1 (optional) - Color of the text (defaults to red)
%   #2            - Coordinates (x,y) where the text box should be placed
%   #3            - The text content to display
\newcommand{\textbox}[3][red]
{
    \begin{picture}(0,0)
        \put(#2){\makebox(0,0)[lt]{\textcolor{#1}{#3}}}
    \end{picture}
}

\newcommand{\codehighlight}[5][\ttfamily\scriptsize]
{
    \ifnum#3>1
        \lstinputlisting[firstnumber=1, firstline=1, lastline=\number\numexpr#3-1\relax, language=#2, style=transparent, basicstyle=#1\color{black_transparent}, showlines=true]{#5}
        \vspace{-12pt}
    \fi
    \lstinputlisting[firstnumber=#3, firstline=#3, lastline=#4, language=#2, style=mystyle, basicstyle=#1, showlines=true]{#5}
    \vspace{-12pt}
    \lstinputlisting[firstnumber=\number\numexpr#4+1\relax, firstline=\number\numexpr#4+1\relax, lastline=100, language=#2, style=transparent, basicstyle=#1\color{black_transparent}, showlines=true]{#5}
}

% to be able to remove the final frames (questions, references) from the final section
\makeatletter
\let\beamer@writeslidentry@miniframeson=\beamer@writeslidentry%
\def\beamer@writeslidentry@miniframesoff{%
  \expandafter\beamer@ifempty\expandafter{\beamer@framestartpage}{}% does not happen normally
  {%else
    % removed \addtocontents commands
    \clearpage\beamer@notesactions%
  }
}
\newcommand*{\miniframeson}{\let\beamer@writeslidentry=\beamer@writeslidentry@miniframeson}
\newcommand*{\miniframesoff}{\let\beamer@writeslidentry=\beamer@writeslidentry@miniframesoff}
\makeatother

\newcommand{\mytable}[4]
{
    \centering
    \begin{tabular}{#1}\hline%
        #2 \\ \hline
        \csvreader[
            separator=semicolon,
            head to column names,
            late after line=\\,
        ]{#4}{}{#3}
        \hline
    \end{tabular}
}

\newcommand{\iconelectrical}{
    \begin{tikzpicture}[remember picture, overlay]
        \node at ([xshift=0.8cm, yshift=-2.3cm]current page.north west) {
            \includesvg[width=1cm]{graphics/icon_electrical.svg}
        };
    \end{tikzpicture}
}

\newcommand{\iconoptical}{
    \begin{tikzpicture}[remember picture, overlay]
        \node at ([xshift=0.8cm, yshift=-2.3cm]current page.north west) {
            \includesvg[width=1cm]{graphics/icon_optical.svg}
        };
    \end{tikzpicture}
}

% usable in math mode
\DeclarePairedDelimiter\abs{\lvert}{\rvert}     % make scalable absolute stripes
\DeclarePairedDelimiter\parenth{(}{)}           % make scalable parentheses
\DeclarePairedDelimiter\brackets{[}{]}          % make scalable brackets
\DeclarePairedDelimiter\floor{\lfloor}{\rfloor} % make scalable floor
\DeclarePairedDelimiter\ceil{\lceil}{\rceil}    % make scalable ceil

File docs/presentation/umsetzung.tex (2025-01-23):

\begin{frame}{Blockdiagramm}
    \begin{figure}
        
    \end{figure}

    \onslide<2->{
        \begin{tikzpicture}[remember picture, overlay]
            \node at ([xshift=8.3cm, yshift=-2.6cm]current page.north west) {
                \includesvg[width=1cm]{graphics/icon_electrical.svg}
            };
        \end{tikzpicture}

        \begin{tikzpicture}[remember picture, overlay]
            \node at ([xshift=7.9cm, yshift=-6.4cm]current page.north west) {
                \includesvg[width=1cm]{graphics/icon_optical.svg}
            };
        \end{tikzpicture}
    }
\end{frame}

\begin{frame}{Konzept: Optischer Teil}
    \begin{figure}
        
    \end{figure}

    \iconoptical
\end{frame}

\subsection{Schaltungen}

\begin{frame}{TDC Elektrisch}
    \begin{figure}
        
    \end{figure}

    \iconelectrical
\end{frame}

\begin{frame}{TDC Optisch}
    \begin{figure}
        
    \end{figure}

    \iconoptical
\end{frame}

\begin{frame}{Laser Treiber}
    \begin{figure}
        
    \end{figure}

    \iconoptical
\end{frame}

\begin{frame}{Photo Receiver}
    \begin{figure}
        
    \end{figure}

    \iconoptical
\end{frame}

\begin{frame}{3D View}
    \begin{figure}
        
    \end{figure}
\end{frame}

\begin{frame}{Demonstrator}
    \begin{figure}
        
    \end{figure}
\end{frame}

\subsection{Firmware}

\begin{frame}{Firmware Blockdiagramm}
    \begin{figure}
        
    \end{figure}
\end{frame}

\begin{frame}{Firmware Beispiel: Konfiguration}
    \only<1>{\codehighlight{C}{1}{99}{sourcecode/tdc_example_config.c}}
    \only<2>{\codehighlight{C}{1}{5}{sourcecode/tdc_example_config.c}}
    \only<3>{\codehighlight{C}{7}{13}{sourcecode/tdc_example_config.c}}
\end{frame}

\begin{frame}{Firmware Beispiel: Messung}
    \only<1>{\codehighlight{C}{1}{99}{sourcecode/tdc_example_measure.c}}
    \only<2>{\codehighlight{C}{4}{4}{sourcecode/tdc_example_measure.c}}
    \only<3>{\codehighlight{C}{6}{8}{sourcecode/tdc_example_measure.c}}
    \only<4>{\codehighlight{C}{10}{10}{sourcecode/tdc_example_measure.c}}
    \only<5>{\codehighlight{C}{12}{12}{sourcecode/tdc_example_measure.c}}
\end{frame}

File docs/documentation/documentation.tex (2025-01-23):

\documentclass[11pt,a4paper,hidelinks]{article}

\input{settings.tex}

% Variables
\newcommand{\vTitle}{DIY Optische ToF Distanzmessung}
\newcommand{\vModule}{CAS Sensorik und Sensor Signal Conditioning}
\newcommand{\vAuthorFirstName}{Matthias Schär,}
\newcommand{\vAuthorLastName}{Timon Burkard}
\newcommand{\vUniversity}{OST -- Ostschweizer Fachhochschule}
\newcommand{\vDegree}{CAS Sensorik und Sensor Signal Conditioning}
\newcommand{\vSemester}{HS24}
\newcommand{\vProfessor}{Prof. Guido Keel, Michael Lehmann}
\newcommand{\vCity}{Rapperswil}
\newcommand{\vAbstract}{
    Diese Projektarbeit behandelt die Entwicklung eines \acrfull{diy} Systems zur optischen \acrfull{tof} Distanzmessung.

    Um die Signallaufzeit präzise zu messen, wird ein \acrfull{tdc} eingesetzt. Zu Testzwecken wird ein zweiter
    \acrshort{tdc} verwendet, der rein elektrisch betrieben wird, um die Länge unterschiedlicher Kupferkabel zu
    bestimmen.

    Die Arbeit umfasst die Entwicklung der Hardware, einschließlich Lasertreiber, Photodetektor und
    Transimpedanzverstärker, sowie die Implementierung der Firmware zur Signalauswertung. Simulationen und Messungen
    wurden durchgeführt, um die Genauigkeit zu optimieren und Störfaktoren zu minimieren.

    Die elektrischen Messungen zeigen, dass der \acrshort{tdc} eine zeitliche Auflösung im Bereich einiger Dutzend
    Pikosekunden erreicht. Damit lassen sich Kabellängen auf wenige cm genau bestimmen.

    Die optischen Messungen zeigen, dass eine grobe Distanzmessung bis ca. 30~cm möglich ist, wenn ein Spiegel als
    Target eingesetzt wird. Um die Distanz zu einer Wand messen zu können, sind weiterführende Verbesserungen des
    Demonstrators notwendig.
}

% Acronyms
\newacronym{pcb}{PCB}{Printed Circuit Board}
\newacronym{tof}{ToF}{Time of Flight}
\newacronym{diy}{DIY}{Do It Yourself}
\newacronym{adc}{ADC}{Analog to Digital Converter}
\newacronym{tdc}{TDC}{Time to Digital Converter}
\newacronym{tia}{TIA}{Trans-Impedance Amplifier}
\newacronym{mcu}{MCU}{Microcontroller Unit}
\newacronym{cpu}{CPU}{Central Processing Unit}
\newacronym{hal}{HAL}{Hardware Abstraction Layer}
\newacronym{gpio}{GPIO}{General Purpose Input/Output}
\newacronym{uart}{UART}{Universal Asynchronous Receiver/Transmitter}
\newacronym{dso}{DSO}{Digital Storage Oscilloscope}
\newacronym{spi}{SPI}{Serial Peripheral Interface}
\newacronym{ic}{IC}{Integrated Circuit}
\newacronym{usb}{USB}{Universal Serial Bus}
\newacronym{hsi}{HSI}{High Speed Internal}
\newacronym{pll}{PLL}{Phase-Locked Loop}
\newacronym{ams}{AMS}{Analog/Mixed Signal}
\newacronym{fw}{FW}{Firmware}

\begin{document}

\input{coverpage.tex}
\input{titlepage.tex}
\input{tocpage.tex}
\input{acronympage.tex}
\input{figurepage.tex}
\input{equationpage.tex}
\input{tablepage.tex}
\input{codepage.tex}

%%%%%%%%%%%%%%%%%%%%%% CONTENT START %%%%%%%%%%%%%%%%%%%%%%

\section{Einleitung}\label{sec:introduction}
\input{einleitung.tex}
\pagebreak

\section{Theorie}\label{sec:theory}
\input{theorie.tex}
\pagebreak

\section{Konzept}\label{sec:concept}
\input{konzept.tex}
\pagebreak

\section{Simulationen}\label{sec:simulations}
\input{simulationen.tex}
\pagebreak

\section{Umsetzung}\label{sec:realisation}
\input{umsetzung.tex}
\pagebreak

\section{Resultate}\label{sec:results}
\input{resultate.tex}
\pagebreak

\section{Fazit}\label{sec:conclusion}
\input{fazit.tex}
\pagebreak

\section{Anhang}\label{sec:appendix}
\input{anhang.tex}

%%%%%%%%%%%%%%%%%%%%%% CONTENT END %%%%%%%%%%%%%%%%%%%%%%

\input{referencepage.tex}

\end{document}

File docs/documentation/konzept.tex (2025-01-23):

Die folgenden Unterkapitel klären über die Entwicklungsarbeiten auf, welche für das Umsetzen des \acrshort{tof}-Demonstrators
nötig sind. Hierbei wird vor allem darauf eingegangen, wie die Elektronik aufgebaut sein kann. Zudem werden weitere
Herausforderungen eines solchen Systems und die mögliche Bewältigung ebendieser aufgezeigt.

\subsection{Signalkette}

Nachfolgend sind einige Erklärungen dazu zu finden, wie die \acrshort{tof}-Messung realisiert wird.

Ein Blockdiagramm des Gesamtprojektes, bestehend aus dem elektrischen und dem optischen Teil, ist in
Abbildung~\ref{fig:blockdiagram} dargestellt.

\begin{figure}[H]
    \centering
    
    \caption{Blockdiagramm}\label{fig:blockdiagram}
\end{figure}

Eine detailliertere Skizze der optischen Signalkette ist in der Abbildung~\ref{fig:konzept_signalpfad} ersichtlich.

\begin{figure}[H]
    \centering
    
    \caption{Konzeptioneller Signalpfad}\label{fig:konzept_signalpfad}
\end{figure}

Eine \acrshort{mcu} kümmert sich um das Starten und Auswerten der Messresultate. Das Generieren eines Startsignals hat
zur Folge, dass über einen Laser-Treiber eine Laser-Diode mit einem Puls angesteuert wird. Dieser Puls, nach der Laser-Diode
in Form eines Lichtpulses, wird dann von einem Target reflektiert, welches in einer variablen Distanz zur Elektronik steht.

Der reflektierte Lichtpuls wird über eine Optik fokussiert und anschliessend von einer Photo-Diode in einen
Lichtstrom umgewandelt. Dieser Lichtstrom wird von einem Transimpedanzverstärker in eine Spannung umgewandelt. Bevor die
\acrshort{mcu} diese Spannung auswerten kann, muss diese erst digitalisiert werden. Dies passiert unter Verwendung eines
Komparators. Dieser kann als 1~bit \acrshort{adc} verstanden werden, da bloss eine Unterscheidung der beiden Zustände
\dq Licht\dq\ und \dq kein Licht\dq\ notwendig ist. Es ergibt sich also ein Empfangspuls.

Wird nun die Zeit zwischen Startsignal und empfangenem Puls gemessen, ist es möglich einen Rückschluss über die variable
Strecke zwischen Elektronik und Target zu ziehen. Die Zeitmessung unterliegt höchsten Anforderungen. Als
Versinnbildlichung: Innert einer Nanosekunde legt Licht eine Distanz von 30~cm zurück. Wie eine solche Zeitmessung
realisiert werden kann, erklärt das nächste Unterkapitel.

\subsection{Zeitmessung}

Damit ein direct \acrshort{tof}-Signal ausgewertet werden kann, benötigt es eine hochaufgelöste
Zeitmessung. Die Firma Texas Instruments bietet dafür mit dem TDC7200 eine gute Lösung
an. Laut Datenblatt \cite{ti2016tdc7200_datasheet} kann dieser bis zu 55~ps auflösen, mit einer
Standardabweichung von 35~ps. Setzt man nun die Lichtgeschwindigkeit sowie diese minimale
zeitliche Auflösung in eine Bewegungsgleichung ein, sollte der Baustein gemäss der Formel~\ref{eq:tdc_max_resolution}
folgende räumliche Auflösung erreichen:

\begin{equation}\label{eq:tdc_max_resolution}
        s_{min} = c \cdot t = 299.8 \cdot 10^6~\frac{m}{s} \cdot 55~ps = 16.5~mm
\end{equation}
\myequations{Maximale räumliche Auflösung des TDC7200}

Prinzipiell soll die \acrshort{tof}-Funktionalität in zwei Schritten in Betrieb genommen werden.
In einem ersten Teil soll es rein darum gehen, den TDC7200 \acrshort{ic} genauer
kennenzulernen.

Bemerkung: In der Realität wird eine solche Auflösung nicht erreichbar sein. Die Herausforderungen
bestehen beispielsweise darin, dass in der gesamten Signalkette diverse Verzögerungen vorhanden sind.
So spielen zum Beispiel das Einschalten der Laser-Diode, die Bandbreite des Verstärkers sowie
die Schaltzeit des Komparators eine grosse Rolle. Auch der Jitter der \acrshort{mcu} beim Ein- und Ausschalten
ihrer Ausgänge wird bei der minimalen Auflösung ins Gewicht fallen. Im Kapitel~\ref{sec:electrical_measurements}
wird mittels verschiedener Messungen dargestellt, wie nah an die vom TDC7200 vorgegebene Grenze herangekommen wird.

\subsection{Vorgehensweise}\label{sec:approach}

Wie bereits erläutert, ist davon auszugehen, dass der gesamte Signalpfad eine Ungenauigkeit in die Messung einbringt,
welche weit ausserhalb derjenigen des TDC7200 liegt. Es bietet sich also an, dass diese im Vorfeld untersucht wird.
Dazu wird ein zweiter TDC7200 auf der Elektronik eingesetzt, welcher zur Messung eines rein elektrischen Signals
zuständig ist.

\begin{figure}[H]
    \centering
    
    \caption{Konzept Betrieb \acrshort{tdc} rein elektrisch}\label{fig:konzept_tdc_electrical}
\end{figure}

In Abbildung~\ref{fig:konzept_tdc_electrical} sei skizziert, wie eine solche Schaltung aussehen könnte. Die gewellte,
rot markierte Linie versinnbildlicht dabei einen variablen Messpfad. Über einen Stecker können hier unterschiedlich lange
Kabel angeschlossen werden. Somit ist es möglich, die Messgenauigkeit des TDC7200 rein elektrisch nachzuweisen.

Folgende Punkte können mit einer solchen Erweiterung überprüft werden:

\begin{itemize}
    \item Messung Jitter der Ausgänge der verwendeten \acrshort{mcu}
    \item Konfiguration und Inbetriebnahme TDC7200 (z.B. verschiedene Messmodi)
    \item Auswertung der Resultate des TDC7200
\end{itemize}

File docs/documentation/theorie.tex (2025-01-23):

In den nachfolgenden Unterkapitel werden die theoretischen Grundlagen erarbeitet, welche für das Verständnis sowie das
Design eines Demonstrators für das \acrshort{tof}-Verfahren notwendig sind.

\subsection{Time of Flight}

Beim Messverfahren, welches als \dq \acrlong{tof}\dq\ bekannt ist, geht es darum, die Laufzeit eines Signales zu messen.
Das Signal kann hierbei optischer oder akustischer Natur sein. Eine Anwendung davon ist beispielsweise die Distanzmessung.

Beim hier behandelten optischen Prinzip wird mit einem Sender Licht ausgesandt, welches von einem Empfänger detektiert wird.
Zwischen dem Senden und Empfangen des Signals kann eine Zeitmessung gemacht werden. Weil sich Licht mit einer definierten
Geschwindigkeit ausbreitet, kann über diese Laufzeitmessung ein Rückschluss darüber gewonnen werden, welche Distanz
das Signal innerhalb der gemessenen Zeit zurückgelegt hat.

\begin{figure}[H]
    \centering
    
    \caption{Visualisierung von a: direct \acrshort{tof} und b: indirect \acrshort{tof}}\label{fig:dtof_vs_itof}
\end{figure}

Man unterscheidet zwei Arten von \acrshort{tof}: Direct \acrshort{tof} (dToF) und Indirect \acrshort{tof} (iToF). Bei dToF
wird einzig und alleine die Laufzeit zwischen Sende- und Empfangspuls ermittelt. In der Abbildung~\ref{fig:dtof_vs_itof}
sind bei a) beispielhaft solche Pulse dargestellt.

Bei iToF wird (teilweise zusätzlich) zur Laufzeitmessung auch die Phasenverschiebung eines modulierten Lichtsignales gemessen.
Dies sei bei Abbildung~\ref{fig:dtof_vs_itof} im Teil b) dargestellt. Diese Methode erlaubt es, höhere Auflösungen zu
erreichen, ist jedoch in der Auswertung und Signalaufbereitung ungleich komplexer.

Diese Arbeit beschränkt sich auf das direct \acrshort{tof} Verfahren.

Nachfolgend werden die theoretischen Grundlagen, vor allem in Hinblick auf das Auslegen einer geeigneten Optik, diskutiert.

\pagebreak

\subsection{Photostrom}

Zur Berechnung des theoretisch zu erwartenden Photostroms wird von einer Distanz von $10~m$ zur Wand ausgegangen.

In einer vereinfachten Betrachtung treffe ein Laserstrahl mit einer Divergenz von $0\degree$ rechtwinklig auf eine Wand
und werde dort uniform Halbkugel-förmig gestreut. In der Realität wird der Laser nicht mit $0\degree$ zur Wand gehen und
die Streuung wird sich nicht uniform verteilen, sondern in der Mitte stärker konzentriert sein.

Die Berechnung der empfangenen Strahlungsleistung, der Strahlungsintensität, dem Raumwinkel einer Halbkugel und dem
Photostrom sind in Formel~\ref{eq:pin}, \ref{eq:ie}, \ref{eq:omega} bzw. \ref{eq:iph} gezeigt.

\begin{equation}\label{eq:pin}
    P_{in} = E_e \cdot A = \frac{I_e}{r^2} \cdot A
\end{equation}
\myequations{Eintreffende Lichtleistung}

\begin{equation}\label{eq:ie}
    I_e = \frac{P_{out}}{\Omega}
\end{equation}
\myequations{Strahlungsintensität}

\begin{equation}\label{eq:omega}
    \Omega = 4\cdot \pi \cdot 0.5
\end{equation}
\myequations{Raumwinkel}

\begin{equation}\label{eq:iph}
    I_{ph} = S \cdot P_{in}
\end{equation}
\myequations{Photostrom}

\subsubsection{Berechnung mit RLD94PZJ5 und BPV23NF}

Erste Berechnungen werden mit der Laserdiode RLD94PZJ5 \cite{rohm2020rld94pzj5_datasheet} und der Photodiode BPV23NF
\cite{vishay2024bpv23nf_datasheet} durchgeführt.

Die relevanten Werte aus den Datenblättern sind in Formel~\ref{eq:rld94pzj5_num} und \ref{eq:rbpv23nf_num} aufgelistet.

\begin{equation}\label{eq:rld94pzj5_num}
    P_{out} = 285~mW
\end{equation}
\myequations{Werte des RLD94PZJ5}

\begin{equation}\label{eq:rbpv23nf_num}
    \begin{split}
        A &= 4.4~mm^2\\
        S &= 0.6~\frac{A}{W}
    \end{split}
\end{equation}
\myequations{Werte des BPV23NF}

Diese Werte eingesetzt in Formel~\ref{eq:ie}, \ref{eq:pin} und \ref{eq:iph} ergibt die Resultate in
Formel~\ref{eq:rld94pzj5_rbpv23nf_num}.

\begin{equation}\label{eq:rld94pzj5_rbpv23nf_num}
    \begin{split}
        I_e    &= \frac{P_{out}}{\Omega} = \frac{285~mW}{4\cdot \pi \cdot 0.5~sr} = 45.4~\frac{mW}{sr}\\
        P_{in} &= \frac{I_e}{r^2} \cdot A = \frac{45.4~\frac{mW}{sr}}{(10~m)^2} \cdot 4.4~mm^2 = 2~nW\\
        I_{ph} &= S \cdot P_{in} = 0.6~\frac{A}{W} \cdot 2~nW = 1.2~nA
    \end{split}
\end{equation}
\myequations{Nummerische Resultate mit RLD94PZJ5 und BPV23NF}

\subsubsection{Berechnung mit RLD65NZX1 and NJL6401R-3}

Die Laserdiode RLD94PZJ5 hat im Bezug auf diese Projektarbeit zwei Nachteile: Einerseits besitzt sie eine so hohe Leistung,
dass sie für das menschliche Auge schädigend wirken kann. Andererseits strahlt sie in einem Wellenlängenbereich ab, der
für das menschliche Auge nicht sichtbar ist.

Aus diesen Gründen wird eine zweite Laserdiode evaluiert: RLD65NZX1 \cite{rohm2019rld65nzx1_datasheet}. Gepaart wird
sie mit der Photodiode NJL6401R-3 \cite{jrc2014njl6401r3_datasheet}. Die folgenden Berechnungen werden basierend auf
diesen beiden Komponenten durchgeführt.

Die relevanten Werte aus den Datenblättern sind in Formel~\ref{eq:rld65nzx1_num} und \ref{eq:njl6401r3_num} aufgelistet.

\begin{equation}\label{eq:rld65nzx1_num}
    P_{out} = 10~mW
\end{equation}
\myequations{Werte des RLD65NZX1}

\begin{equation}\label{eq:njl6401r3_num}
    \begin{split}
        A &= 0.7~mm \cdot 0.7~mm = 0.49~mm^2\\
        S &= 0.42~\frac{A}{W}
    \end{split}
\end{equation}
\myequations{Werte des NJL6401R-3}

Eingesetzt in die Formeln~\ref{eq:ie}, \ref{eq:pin} und \ref{eq:iph} ergeben sich die neuen Resultate in
Formel~\ref{eq:rld65nzx1_njl6401r3_num}.

\begin{equation}\label{eq:rld65nzx1_njl6401r3_num}
    \begin{split}
        I_e    &= \frac{P_{out}}{\Omega} = \frac{10~mW}{4\cdot \pi \cdot 0.5~sr} = 1.59~\frac{mW}{sr}\\
        P_{in} &= \frac{I_e}{r^2} \cdot A = \frac{1.59~\frac{mW}{sr}}{(10~m)^2} \cdot 0.49~mm^2 = 7.8~pW\\
        I_{ph} &= S \cdot P_{in} = 0.42~\frac{A}{W} \cdot 7.8~pW = 3.28~pA
    \end{split}
\end{equation}
\myequations{Nummerische Resultate mit RLD65NZX1 and NJL6401R-3}

\subsubsection{Berechnung mit Empfangs-Linse}

Auf Vorschlag der Dozenten werden verschiedene Optiken aus einem Baukasten-System von QIOPTIQ ausprobiert.
Besonders vielversprechend erscheint hierbei eine Linse mit einem Durchmesser von 17~mm bei einer Brennweite von
40~mm. Die Linse ist in Abbildung~\ref{fig:lens} dargestellt.

\begin{figure}[H]
    \centering
    
    \caption{Linse von QIOPTIQ}\label{fig:lens}
\end{figure}

Eine solche Linse vergrössert die effektive Fläche, auf welcher der Lichtstrom empfangen werden kann. Dies hat
eine höhere Empfangsleistung, sprich einen höheren Lichtstrom, zur Folge.

Die Formel~\ref{eq:njl6401r3_lens} zeigt die beim Einsatz einer solchen Optik zu erwartende Flächenvergrösserung.

\begin{equation}\label{eq:njl6401r3_lens}
    A' = \frac{A_{L}}{A_{PD}} = \frac{(\frac{17~mm}{2})^2 \cdot \pi}{0.49~mm^2} = 463.2
\end{equation}
\myequations{Vergrösserung der Empfangsfläche durch Linse}

\subsubsection{Erwarteter Lichtstrom}
Nachfolgend werden zwei Szenarien betrachtet: Einmal wird wie bis anhin davon ausgegangen, dass sich das Licht ab dem Laser
in einem gebündelten Strahl ausbreitet, um danach halbkugelförmig und diffus am Target zu reflektieren.

Im zweiten Szenario wird versucht, die Abstrahlcharakteristik der Laser-Diode zu modellieren. Laut Datenblatt hat die
Diode in der Abstrahlebene zwei unterschiedliche Öffnungswinkel, was mit dem Raumwinkel einer rechteckigen Pyramide
annäherungsweise berechnet werden kann. Die Streuung wird verhindert, da an einem Spiegel reflektiert wird.

Bei beiden Szenarien sei die abgestrahlte Leistung der Laser-Diode höher als in der ersten Rechnung. Im gepulsten
Betrieb kann diese problemlos über das maximale Rating erhöht werden. Thermisch stellt dies kein Problem für die Diode dar, da
der Duty-Cycle sehr klein ist. Die Formel~\ref{eq:rld65nzx1_higher_output} zeigt die neu zu erwartete Abstrahl-Leistung
eines solchen Pulses. Die Effizienz der Laser-Diode wird dem Datenblatt des RLD65NZX1 entnommen \cite{rohm2019rld65nzx1_datasheet}.

\begin{equation}\label{eq:rld65nzx1_higher_output}
    \begin{split}
        \eta     &= \frac{P_{25~mA}}{I_{ld}} = \frac{7~mW}{25~mA} = 0.28~\frac{W}{A}\\
        I_{ld}'  &= \frac{5~V - V_{LD}}{R_{v}} = \frac{5~V - 2.8~V}{5~\Omega} = 440~mA\\
        P_{out}' &= \eta \cdot I_{ld}' = 0.28~\frac{W}{A} \cdot 440~mA = 123~mW
    \end{split}
\end{equation}
\myequations{Erhöhte Sendeleistung bei der Laser-Diode}

Bei einem Target, welches sich in 2~m Distanz befindet, kann nach Formel~\ref{eq:photocurrent_scenario1} folgender
Lichtstrom erwartet werden:

\begin{equation}\label{eq:photocurrent_scenario1}
    \begin{split}
        P_{in} &= \frac{P_{out}}{\Omega \cdot r^2} \cdot A_{L} = \frac{123~mW}{4\pi \cdot 0.5~sr \cdot (2~m)^2} \cdot 227~mm^2 = 1.11~\mu W\\
        I_{ph} &= S \cdot P_{in} = 0.42~\frac{A}{W} \cdot 1.11~\mu W = 467~nA
    \end{split}
\end{equation}
\myequations{Photostrom Szenario 1}

Ohne Optik strahlt die Laserdiode keinen gebündelten Strahl. Diese Abstrahlcharakteristik sei im zweiten Szenario über
den Raumwinkel einer Pyramide, wie er in Formel~\ref{eq:solid_angle_pyramid} definiert ist, modelliert. Die typischen
Abstrahlwinkel $\theta$ werden ebenfalls dem Datenblatt der Laser-Diode entnommen. Hierbei ist zu beachten, dass im
Datenblatt der Vollwinkel angegeben wird. Der Wert in der Formel wird deswegen halbiert.

\begin{equation}\label{eq:solid_angle_pyramid}
    \Omega_{P} = 4 \cdot arcsin(sin(\theta_x) \cdot sin(\theta_y)) =  4 \cdot arcsin \parenth*{sin \parenth*{\frac{9\degree}{2}} \cdot sin \parenth*{\frac{29\degree}{2}}} = 4.2~sr
\end{equation}
\myequations{Modell Abstrahlung Laserdiode}

Mit der Formel~\ref{eq:photocurrent_scenario2} wird erneut die zu erwartende Empfangsleistung sowie der dazugehörige
Photostrom berechnet. Der Unterschied zur vorherigen Berechnung liegt nun aber darin, dass der Raumwinkel auch bereits
vor der Reflexion berücksichtigt werden muss. Deswegen wird die Distanz zum Target mit zwei multipliziert.

\begin{equation}\label{eq:photocurrent_scenario2}
    \begin{split}
        P_{in} &= \frac{P_{out}}{\Omega \cdot (2 \cdot r)^2} \cdot A_{L} = \frac{123~mW}{4.2~sr \cdot (2 \cdot 2~m)^2} \cdot 227~mm^2 = 416~nW\\
        I_{ph} &= S \cdot P_{in} = 0.42~\frac{A}{W} \cdot 416~nW = 175~nA
    \end{split}
\end{equation}
\myequations{Photostrom Szenario 2}

\pagebreak

\subsection{Transimpedanzverstärker}

Wie die Berechnungen in den vorgängigen Kapiteln aufzeigen, besitzen die Photoströme, welche zu detektieren sind, sehr kleine
Stromstärken. Weiter sind die Lichtimpulse typischerweise oft nur von sehr kurzer Dauer, nämlich im Bereich einiger Nanosekunden.
Dies hat zur Folge, dass die Signale dementsprechend kurze Anstiegszeiten haben, welche es zu detektierten gilt.

Die Anforderungen deuten darauf hin, dass ein Verstärker mit sehr hohem Gain bei gleichzeitig sehr hoher Bandbreite eingesetzt werden muss.
Die Verstärkerschaltung, welche eingesetzt wird, ist ein Strom-Spannungswandler. Eine solche Beschaltung des Operationsverstärkers,
wie sie in Abbildung~\ref{fig:theory_tia} zu sehen ist, wird auch Transimpedanzverstärker (\acrshort{tia}) genannt.

\begin{figure}[H]
    \centering
    
    \caption{Beschaltung Operationsverstärker als \acrshort{tia}}\label{fig:theory_tia}
\end{figure}

Wie der Name der Schaltung vermuten lässt, wandelt der Transimpedanzwandler den Photostrom \lstinline|Id| in eine Spannung
\lstinline|Vout| um. Dabei gibt der Feedback-Widerstand \lstinline|Rf| die Verstärkung vor, wie die Formel~\ref{eq:tia_simple}
zeigt:

\begin{equation}\label{eq:tia_simple}
    V_{out} = -R_{f} \cdot I_{d}
\end{equation}
\myequations{Übertragungsfunktion \acrshort{tia}}

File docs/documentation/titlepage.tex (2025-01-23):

\thispagestyle{empty}

\textbf{}
\vspace{5mm}

\begin{flushleft}
    \textbf{\large{\vModule{} an der \vUniversity{}}}
\end{flushleft}

\begin{flushleft}
    \begin{small}
        \begin{tabular}{@{}lll}
            \\
            \textbf{Titel}                 & & \textbf{\vTitle}\\
            \\
            \textbf{Diplomandin/Diplomand} & & \textbf{\vAuthorFirstName{} \vAuthorLastName}\\
            \\
            \textbf{Studiengang}           & & \textbf{\vDegree}\\
            \\
            \textbf{Semester}              & & \textbf{\vSemester}\\
            \\
            \textbf{Dozentin/Dozent}       & & \textbf{\vProfessor}\\
        \end{tabular}
    \end{small}
\end{flushleft}

\vspace{10mm}

% abstracts
\begin{small}
    \textbf{Abstract}

    \vAbstract{}
    \vspace{15mm}
\end{small}

% copyright
\begin{flushleft}
    \begin{small}
        \vCity, \date{\mydate\today} \\
        \textbf{\textcopyright\hspace{1mm}\vAuthorFirstName{} \vAuthorLastName, \vUniversity{}}
    \end{small}
\end{flushleft}

\mbox{}
\vfill

\pagebreak

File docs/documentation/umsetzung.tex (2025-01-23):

In diesem Kapitel ist das Umsetzen der Hardware sowie Firmware des \acrshort{tof}-Demonstrators dokumentiert.

Im Anhang~\ref{sec:schematic_apdx} bis und mit~\ref{sec:apdx_photos_demonstrator} sind sämtliche technischen Dokumente
und einige Fotos des fabrizierten Demonstrators abgelegt.

\subsection{Schaltungen}
Nachfolgend werden sämtliche Teil-Schaltungen thematisiert, welche für das entwickelte \acrshort{tof}-Evaluationsmodul
nötig sind. Ein vollständiges Schema kann dem Anhang~\ref{sec:schematic_apdx} entnommen werden. Die kompletten
Projekt-Dateien sind im elektronischen Anhang dieses Projektes verfügbar.

Gezeichnet wird das Schema mit Hilfe des Open-Source Tools \dq KiCad EDA 8.0\dq\ \cite{kicad2025kicadeda}.

\subsubsection{Selective Input Voltage}

Abbildung~\ref{fig:selective_input_voltage} zeigt die Beschaltung zur Selektion der Speisung.

\begin{figure}[H]
    \centering
    
    \caption{Selective Input Voltage}\label{fig:selective_input_voltage}
\end{figure}

Für die Speisung des Nucleo-Boards bestehen die folgenden Möglichkeiten:

\begin{itemize}
    \item 5~V von USB-Buchse
    \item 5~V von externem Power-Supply (\lstinline|JP1| + \lstinline|JP2|)
    \item 12~V von externem Power-Supply (\lstinline|JP3|)
\end{itemize}

Siehe dazu auch Kapitel~\ref{sec:schematic_nucleo}.

Für die Speisung der 5~V Elektronik bestehen die folgenden Möglichkeiten:

\begin{itemize}
    \item 5~V von Nucleo-Board (\lstinline|JP1|)
    \item 5~V von externem Power-Supply (\lstinline|JP2|)
    \item 12~V von externem Power-Supply via Nucleo-Board (\lstinline|JP1| + \lstinline|JP3|)
\end{itemize}

Für die Speisung der Photodiode bestehen die folgenden Möglichkeiten:

\begin{itemize}
    \item 5~V von 5~V-Elektronik (\lstinline|SW2| Position 3)
    \item 12~V von externem Power-Supply (\lstinline|SW2| Position 1)
\end{itemize}

Siehe dazu auch Kapitel~\ref{sec:schematic_photo_receiver}.

\subsubsection{Nucleo Board}\label{sec:schematic_nucleo}

Die Beschaltung des NUCLEO-F042K6 Boards \cite{st2024nucleof042k6_usermanual} ist in Abbildung~\ref{fig:nucleo_board}
gezeigt.

\begin{figure}[H]
    \centering
    
    \caption{Nucleo Board}\label{fig:nucleo_board}
\end{figure}

Das NUCLEO-Board ist ein sogenanntes \dq Development-Kit\dq, welches eine STM32F042K6 \acrshort{mcu}
beinhaltet. Am Rand des Boards werden diverse Pins der \acrfull{mcu} via Pin-Header zur Verfügung gestellt. Dies erleichtert
die Integration in eine eigene Elektronik enorm. Geflasht wird die \acrshort{mcu} über eine \acrshort{usb}-Schnittstelle.

In diesem Design wird das Entwicklungs-Board dazu benötigt, die TDC7200 \acrshort{ic}s zu bedienen. Dazu wird ein \acrfull{spi}
verwendet, um die Mess-\acrshort{ic}s zu konfigurieren und auszulesen (in der Abbildung als \acrshort{spi}-Bus zusammengefasst).
Mit den Signalen \lstinline|start_ele| bzw. \lstinline|start_opt| können auf den \acrshort{tdc}s Messungen gestartet
werden. Für den \acrshort{tdc}, welcher für die elektrischen Signale zuständig ist, kann zudem mit \lstinline|stop_ele|
ein Stopp-Puls generiert werden. Zu guter Letzt ist das NUCLEO dafür zuständig, die Laser-Diode anzusteuern, was mit den
Signalen \lstinline|LD_pulse| sowie $\overline{\mbox{\lstinline|LD_enable|}}$ geschieht.

\subsubsection{TDC Electrical Signal}

Die Beschaltung des TDC7200 \cite{ti2016tdc7200_datasheet} für den elektrischen Teil ist in
Abbildung~\ref{fig:tdc_ele_signal} gezeigt.

\begin{figure}[H]
    \centering
    
    \caption{\acrshort{tdc} Electrical Signal}\label{fig:tdc_ele_signal}
\end{figure}

Der TDC7200 ist über die die Start- und Stopp-Leitungen, ein Enable-Signal sowie die \acrshort{spi}-Leitungen mit der
\acrshort{mcu} verbunden.

Wie bereits im Kapitel~\ref{sec:approach} angesprochen, wird der elektrische \acrshort{tdc} dazu verwendet, den Chip
erstmalig in Betrieb zu nehmen und sich damit vertraut zu machen. Am Anschluss \lstinline|J3| kann in einem nächsten
Schritt ein beliebig langes Kabel angeschlossen werden. Dies ermöglicht es, erste Messresultate, natürlich rein elektrisch,
vom TDC7200 auszulesen.

Mittels Schalter \lstinline|SW1| kann das \lstinline|STOP|-Signal wahlweise via \lstinline|stop_ele| oder
\lstinline|start_ele| generiert werden. Dies bietet zum einen die Möglichkeit, die Zeit zwischen dem Schalten von zwei
\acrshort{gpio}s zu messen. Zum anderen kann derselbe \acrshort{gpio}-Pin zum Generieren des \lstinline|START|- und
\lstinline|STOP|-Signals verwendet werden, wodurch von der Verzögerungszeit direkt auf die Kabellänge an \lstinline|J3|
geschlossen werden kann.

\subsubsection{TDC Optical Signal}

Die Beschaltung des TDC7200 \cite{ti2016tdc7200_datasheet} für den optischen Teil ist in
Abbildung~\ref{fig:tdc_opt_signal} gezeigt.

\begin{figure}[H]
    \centering
    
    \caption{\acrshort{tdc} Optical Signal}\label{fig:tdc_opt_signal}
\end{figure}

Die Beschaltung des \acrshort{tdc}s für die optische Messung gestaltet sich praktisch gleich wie beim elektrischen
Gegenstück. Der Hauptunterschied ist hier aber, dass dessen \lstinline|STOP|-Signal nicht von der \acrshort{mcu} selber generiert
wird, sondern von einem Komparator, welcher am Ende des optischen Messpfades steht. Da der Komparator mit einem 5~V Pegel
arbeitet, ist der Spannungsteiler \lstinline|R1| / \lstinline|R2| vonnöten, welcher den 5~V Puls auf die geeigneten 3.3~V
herunterteilt.

\subsubsection{Oscillator For TDCs}

Die Beschaltung des Oszillators für die beiden \acrshort{tdc} ist in Abbildung~\ref{fig:oscillator_tdc} gezeigt. Es
handelt sich hierbei um einen normalen Quartz-Oszillator mit integriertem Schwingkreis. Praktischerweise ist bei diesem
also keine weitere Beschaltung notwendig.

\begin{figure}[H]
    \centering
    
    \caption{Oscillator for \acrshort{tdc}s}\label{fig:oscillator_tdc}
\end{figure}

\subsubsection{Power Supply Separation}

Für die Beschaltung der Photodiode, inkl. \acrshort{tia} und Komparator, macht es Sinn eine Spannungsversorgung mit
möglichst wenig Rauschen zu haben.

Dazu wurde die Separierung vorgenommen, welche in Abbildung~\ref{fig:power_supply_separation} dargestellt ist.

\begin{figure}[H]
    \centering
    
    \caption{Power Supply Separation}\label{fig:power_supply_separation}
\end{figure}

Prinzipiell sollen die Speisungen über eine Ferrit-Perle etwas entstört werden. Massgeblich ist hier natürlich auch der
physikalische Verlauf des Speisungspfades auf dem Layout. Dazu mehr im entsprechenden Kapitel~\ref{sec:layout}. Wahlweise
besteht nebst den Ferrit-Perlen die Möglichkeit, mittels Kondensatoren die Speisung weiter zu entkoppeln. Es wird jedoch
davon ausgegangen, dass dies in einem ersten Schritt nicht notwendig ist.

\subsubsection{Laser Driver}\label{sec:schematic_laser_driver}

Die Laser Diode RLD65NZX1 \cite{rohm2019rld65nzx1_datasheet} wird mittels Lasertreiber LMG1025-Q1 \cite{ti2024lmg1025q1_datasheet}
und NexFET \cite{ti2016csd17578q3a_datasheet} angesteuert. Das AND-Gatter \lstinline|IC21| \cite{diodes202074lvc1g08q_datasheet}
implementiert zusammen mit dem Hochpass (\lstinline|C21|, \lstinline|R21| und \lstinline|RV21|) einen Pulsverkürzer.
Über diesen Pfad lassen sich für den Laser Pulse im Bereich von 0.5 \dots 100~ns generieren. Siehe dazu Abbildung~\ref{fig:laser_driver}.

Der Widerstand \lstinline|R25| bildet den Vorwiderstand für die Laser-Diode, welcher sich gemäss der Formel~\ref{eq:ld_resistor} berechnet.

\begin{equation}\label{eq:ld_resistor}
    R_{v} = \frac{V_{cc} - V_{fld}}{I_{ld}} = \frac{5~V - 2~V}{40~mA} = 75~\Omega
\end{equation}
\myequations{Vorwiderstand Laser-Diode}

Im Schema eingezeichnet ist aktuell ein Platzhalterwert. Während der Inbetriebnahme wird der Widerstand je nach Bedarf
verändert. Wird dieser verkleinert, so vergrössert sich der Strom durch die Laser-Diode und somit die ausgesandte
Lichtleistung.

\begin{figure}[H]
    \centering
    
    \caption{Laser Driver}\label{fig:laser_driver}
\end{figure}

\subsubsection{Photo Receiver}\label{sec:schematic_photo_receiver}

Um den Photostrom der Photodiode NJL6401R \cite{jrc2014njl6401r3_datasheet} zu verstärken und in eine Spannung umzuwandeln,
wird mit dem Operationsverstärker OPA858 \cite{ti2018opa858_datasheet} ein Transimpedanzverstärker aufgebaut. Der
Ausgang des Transimpedanzverstärkers geht auf den Komparator TLV3501 \cite{ti2016tlv3501_datasheet}, um das \lstinline|STOP|-Signal
für den \acrshort{tdc} zu generieren. Siehe dazu Abbildung~\ref{fig:photo_receiver}.

Der Feedback-Widerstand \lstinline|R26| kann je nach Bedarf verändert werden. Wird dieser vergrössert, so steigt auch der
negative Puls am Ausgang des \acrshort{tia}s. Mit \lstinline|C20| kann zudem bei Bedarf eine kleine Kapazität hinzugefügt
werden. Diese hat zum Ziel, ein Schwingen des Verstärkers zu unterdrücken, falls dieser eine Neigung zum Schwingen haben
sollte.

Der Offset des OPA858 und die Schaltschwelle des TLV3501 werden mit Hilfe der beiden Trimmer \lstinline|RV22| und
\lstinline|RV23| einstellbar gemacht. Dies hilft bei der Inbetriebnahme, da im Voraus noch nicht ganz klar ist,
wo der Ausgang des Operationsverstärkers aufgrund des gewandelten Dunkelstroms der Photodiode zu liegen kommt.

\begin{figure}[H]
    \centering
    
    \caption{Photo Receiver}\label{fig:photo_receiver}
\end{figure}

\subsubsection{Decoupling Capacitors}

Die Beschaltung der Entkopplungs-Kondensatoren ist in Abbildung~\ref{fig:decoupling_capacitors} dargestellt. Die
Kondensatoren für den Operationsverstärker OPA858 und für den Komparator TLV3501 werden dem Vorschlag im Datenblatt
entnommen. Zusätzlich wird auch der Gate-Treiber beim Laser-Treiber mit einer zusätzlichen, grösseren Kapazität gestützt,
was sich positiv auf die Stabilität der Speisung auswirken sollte.

\begin{figure}[H]
    \centering
    
    \caption{Decoupling Capacitors}\label{fig:decoupling_capacitors}
\end{figure}

\pagebreak

\subsection{Layout}\label{sec:layout}

Beim Layout wird ein Augenmerk darauf gelegt, dass die verschiedenen Schaltungen sich auf dem \acrshort{pcb} nicht
gegenseitig stören. Dafür ist ein sauberes Speisungskonzept im Einsatz, welches die Ground- und Power-Planes nach Layer
definiert. Prinzipiell sind die vier Lagen der Leiterplatte wie folgt aufgetrennt:

\begin{itemize}
    \item Top-Layer: Signal und Ground
    \item Innerer Layer 1: Stromversorgungsebene
    \item Innerer Layer 2: Signal und Ground
    \item Bottom-Layer: Signal und Ground
\end{itemize}

\begin{figure}[H]
    \centering
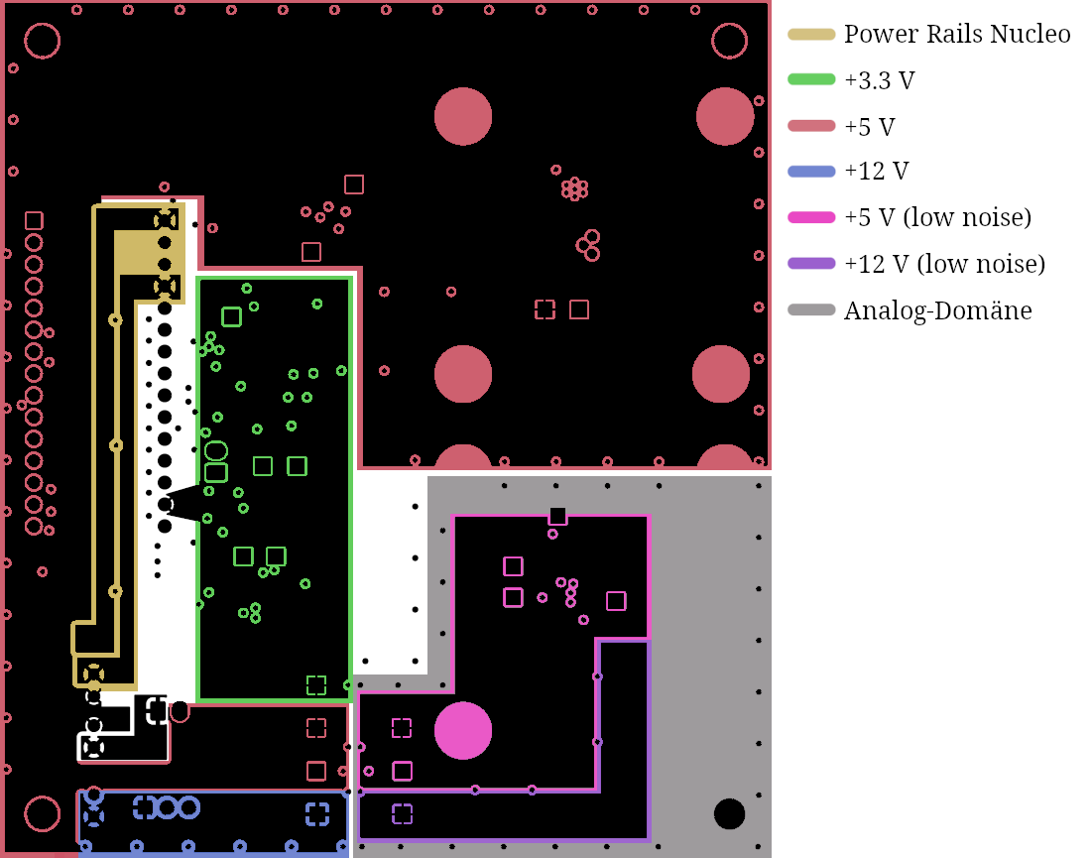
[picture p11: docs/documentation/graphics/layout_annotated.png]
    
    \caption{Innerer Layer 1 mit Vermerken zum Speisungskonzept}\label{fig:layout_annotated}
\end{figure}

In Abbildung~\ref{fig:layout_annotated} ist die Umsetzung des Speisungskonzeptes ersichtlich. In der unteren, rechten Ecke
befindet sich die Analog-Domäne, welche die Photodiode, den \acrshort{tia} und den Komparator beinhaltet. Dieser Abschnitt
des \acrshort{pcb}s besitzt eigene Ground-Planes sowie entstörte Speisungen. Mit Hilfe von einigen Vias an der Aussengrenze
dieses Abschnittes sollte die Analog-Domäne zudem weniger Anfällig auf extern induzierte Störfelder sein.

Solche sogenannten \dq Stitching-Vias\dq\ sind zudem rund um das ganze \acrshort{pcb} zur Abschirmung platziert.

Das komplette Layout kann dem Anhang~\ref{sec:apdx_layout} entnommen werden.

\pagebreak

\subsection{3D View}
Beim Design des Layouts und vor allem bei der Komponentenplatzierung kann eine 3D-Ansicht unterstützend wirken. Dies, weil
ersichtlich gemacht wird, wo sich mechanische und elektronische Komponenten in den Weg kommen könnten. Die Abbildung~\ref{fig:3d_top}
zeigt eine 3D-Wiedergabe der Aufsicht auf den \acrshort{tof}-Demonstrator.

\begin{figure}[H]
    \centering
    
    \caption{3D View Top}\label{fig:3d_top}
\end{figure}

Die Linsenhalterungen sind mit Hilfe von einer Step-Datei, die von QIOPTIQ zur Verfügung gestellt wird in die Ansicht
integriert \cite{qioptiq2024g061041000_shoppage}. In der Abbildung~\ref{fig:3d_top} werden diese als schwarze Quader mit
zylinderförmigen Ausschnitten dargestellt. Direkt unter diesen Halterungen dürfen sich keine Komponenten befinden, da
sich die Halterungen ansonsten nicht montieren lassen.

Bei der Komponentenplatzierung wird zusätzlich auch darauf geachtet, dass sämtliche Testpunkte sowie die Trimmer und
Schalter zur Konfiguration gut zugänglich sind. Wenn sich diese Komponenten nahe an den optoelektronischen Komponenten
befinden, findet sich deren Platzierung auf der Unterseite. Somit sind sie auch mit montierter Optik verfügbar.

\subsection{Fabrikation}
KiCad 8.0 ermöglicht es, aus dem Layout-Design diverse Fabrikations-Dateien für die verschiedenen Layer zu erzeugen.
Diese sogenannten Gerber und NC-Drill Dateien können von einem Leiterplattenhersteller zur Produktion einer Leiterplatte
verwendet werden. Wahlweise kann eine Leiterplatte auch direkt bestückt werden, was jedoch zusätzliche Zeit in der
Produktion beansprucht.

Da sich die meisten Komponente auf dem \acrshort{pcb} relativ gut bestücken lassen, wird auf eine automatisierte Bestückung
verzichtet und die Komponenten werden von Hand bestückt.

Die Komponenten werden bei Mouser Electronics bestellt, während die Leiterplatten vom chinesischen Hersteller JLCPCB
\cite{jlc2025jlcpcb} bezogen werden. Mouser erfüllt die erwartete Lieferzeit von einigen Tagen. Die Bestellung von
JLCPCB kommt mit genau sieben Tagen ebenfalls pünktlich an. Die Ingenieure von JLCPCB müssen keine Rückfragen zum Design
stellen, was sich wohl positiv auf die Lieferzeit auswirkt.

Die fertig bestückte Leiterplatte ist in der Abbildung~\ref{fig:photo_demonstrator_front_wo_lens} ersichtlich. Weitere
Fotografien des \acrshort{tof}-Demonstrators können dem Anhang~\ref{sec:apdx_photos_demonstrator} entnommen werden.

\begin{figure}[H]
    \centering
    
    \caption{Demonstrator von vorne ohne Linse}\label{fig:photo_demonstrator_front_wo_lens}
\end{figure}

\subsection{Firmware}

Bei der Firmware wird darauf geachtet, dass eine saubere Trennung zwischen Applikation, Treiber und
Peripherie vorhanden ist. Dies sorgt für ein möglichst modulares Design. Die \acrshort{fw}-Hierarchie ist in der
Abbildung~\ref{fig:hierarchy_firmware} nachvollziehbar.

\begin{figure}[H]
    \centering
    
    \caption{Aufbau Firmware-Projekt}\label{fig:hierarchy_firmware}
\end{figure}

Die Applikation ist für das Timing der Messungen verantwortlich. Der Code für das auslösen wird während der Messphase schrittweise ausgebaut,
erst über die Verwendung einfacher \acrshort{gpio}s, bis hin zu optimalem zeitlichen Verhalten unter Einsatz verschiedener
Hardware-Timer für das Generieren der Trigger-Pulse für die \acrshort{tdc}s. Im Kapitel~\ref{sec:electrical_measurements}
sind die einzelnen Erweiterungsschritte detaillierer erklärt.

Der \acrshort{tdc}-Treiber stellt Funktionen zur Initialisierung und zum Aktivieren des \acrshort{tdc} zur Verfügung.
Siehe dazu Code~\ref{code:init_enable_tdc}.

\lstinputlisting[language={C}, label={code:init_enable_tdc}, caption={\acrshort{tdc} Init und Enable mit Treiber}]{sourcecode/init_enable_tdc.c}

Der \acrshort{tdc}-Treiber beinhaltet die komplette Registerdefinition des TDC7200. Der Treiber stellt zudem einfache
Lese- und Schreib-Routinen für die Kommunikation via \acrshort{spi} zur Verfügung. Damit kann das Mess- \acrshort{ic}
mit Leichtigkeit umkonfiguriert, aufgesetzt und ausgelesen werden kann. Ein Beispiel ist in
Code~\ref{code:read_write_tdc} dargestellt.

\lstinputlisting[language={C}, label={code:read_write_tdc}, caption={\acrshort{tdc} Read/Write mit Treiber}]{sourcecode/read_write_tdc.c}

Weiter kann der Treiber die Messresultate direkt umrechnen, anhand der im Datenblatt vorgegebenen
Formeln. Im Code~\ref{code:start_measurement_tdc} ist der Beispiel-Code für eine einzelne Messung ersichtlich.

\lstinputlisting[language={C}, label={code:start_measurement_tdc}, caption={\acrshort{tdc} Messung mit Treiber}]{sourcecode/example_tdc_read.c}

Der selbst entwickelte Firmware-Treiber für den \acrshort{tdc} befindet im Anhang~\ref{sec:tdc_driver}.

Mit der Entwicklungsumgebung STM32CubeIDE / CubeMX \cite{st2025stm32cubeide} ist es möglich, das Pinout der
\acrshort{mcu} grafisch zu konfigurieren. Mit Hilfe eines Code-Generators können die Initialisierungs-Routinen für
sämtliche Peripherien automatisiert erzeugt werden. Somit kann während der Entwicklung der Fokus auf den
acrshort{tdc}-Treiber sowie die eigentliche Applikation gelegt werden.

Die Pin-Konfiguration ist in der Abbildung~\ref{fig:pinconfiguration_mcu} ersichtlich.

\begin{figure}[H]
    \centering
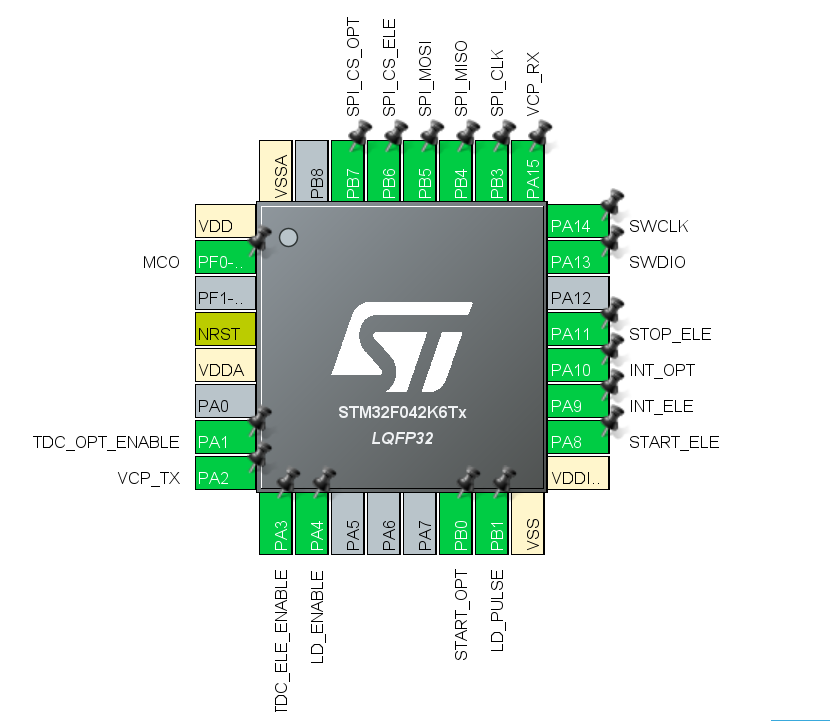
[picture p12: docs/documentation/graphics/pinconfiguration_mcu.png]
    
    \caption{Pin-Konfiguration des STM32F042K6}\label{fig:pinconfiguration_mcu}
\end{figure}

\pagebreak

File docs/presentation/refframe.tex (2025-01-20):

\begin{frame}[allowframebreaks]{Quellen}
    \nocite{*} % add all sources to bibliography not just the cited ones
    \bibliographystyle{unsrtnat}
    {\scriptsize \bibliography{./references.bib}}
\end{frame}

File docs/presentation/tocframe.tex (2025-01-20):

\begin{frame}{Inhaltsverzeichnis}
    \tableofcontents
\end{frame}

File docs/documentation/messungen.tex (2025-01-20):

In diesem Kapitel werden die Messresultate dokumentiert.

Die verwendeten Python-Skripte zur Berechnung der statistischen Grössen und zum Plotten der Diagramme befinden sich im
Anhang~\ref{sec:python_analyze}.

\subsection{Elektrische Messungen}\label{sec:electrical_measurements}

In diesem Teilkapitel werden die Messresultate dokumentiert, welche rein elektrisch (also ohne optischen Teil) erfasst
wurde.

Das verwendete \acrfull{dso} ist ein Rohde \& Schwarz RTB2004 1.25 GSa/s.

Die Zeitmessungen werden von \lstinline|IC1| (siehe Abbildung~\ref{fig:tdc_ele_signal}) durchgeführt und von der
Firmware, welche auf dem Nucleo Board \lstinline|U1| (siehe Abbildung~\ref{fig:nucleo_board}) getriggert und ausgelesen.

\subsubsection{GPIO Toggle mit HAL}\label{sec:gpio_toggle_with_hal}

Als erstes wird gemessen, wie lange es für die \acrshort{cpu} der \acrshort{mcu} dauert mittels \acrfull{hal} - Library
\cite{st2020stm32f0_hal} zwei \acrshort{gpio}-Pins zu schalten.

In Code~\ref{code:gpio_toggle_with_hal} ist die Firmware-Implementation dazu gezeigt.

\lstinputlisting[language={C}, label={code:gpio_toggle_with_hal}, caption={\acrshort{gpio} Toggle mit \acrshort{hal}}]{sourcecode/gpio_toggle_with_hal.c}

Der \acrshort{tdc} misst also die Zeit zwischen Zeile 15 und 16 in Code~\ref{code:gpio_toggle_with_hal}. Dazu wird der
STOP-Pin des \acrshort{tdc} via \lstinline|SW1| mit \lstinline|stop_ele| verbunden. Der Kabelanschluss \lstinline|J3|
wird kurzgeschlossen. Siehe Abbildung~\ref{fig:tdc_ele_signal}.

Via \acrshort{uart} wurden 2000 Messwerte erfasst. Ein Ausschnitt davon ist in Code \ref{code:gpio_toggle_with_hal_log}
gezeigt. Die restlichen Daten befinden sich im elektronischen Anhang.

\lstinputlisting[language={}, label={code:gpio_toggle_with_hal_log}, caption={\acrshort{gpio} Toggle mit \acrshort{hal}}]{sourcecode/gpio_toggle_with_hal_log.txt}

Arithmetischer Mittelwert und Standardabweichung sind in Formel \ref{eq:gpio_toggle_with_hal} aufgeführt.

\begin{equation}\label{eq:gpio_toggle_with_hal}
    \begin{split}
        \overline{ToF} &= 6'375'888~ps\\
        \sigma         &= 1'059~ps
    \end{split}
\end{equation}
\myequations{\acrshort{gpio} Toggle mit \acrshort{hal}}

Da die \acrshort{cpu} mit 8~MHz läuft, lässt sich daraus schliessen, dass ein Pin-Toggle mit \acrshort{hal} ca. 50
\acrshort{cpu}-Cycles benötigt. Dies erscheint plausibel.

Histogramm und Boxplot sind in Abbildung~\ref{fig:gpio_toggle_with_hal_histogram} bzw.
\ref{fig:gpio_toggle_with_hal_boxplot} dargestellt.

\begin{figure}[H]
    \centering
    \includesvg[width=0.8\textwidth]{graphics/gpio_toggle_with_hal_histogram.svg}
    \caption{\acrshort{gpio} Toggle mit \acrshort{hal} - Histogramm}\label{fig:gpio_toggle_with_hal_histogram}
\end{figure}

\begin{figure}[H]
    \centering
    \includesvg[width=0.8\textwidth]{graphics/gpio_toggle_with_hal_boxplot.svg}
    \caption{\acrshort{gpio} Toggle mit \acrshort{hal} - Boxplot}\label{fig:gpio_toggle_with_hal_boxplot}
\end{figure}

Um die Resultate des \acrshort{tdc} zu validieren, wurde dieselbe Messung auch mittels \acrfull{dso} durchgeführt. Die
Messungen sind in Abbildung~\ref{fig:gpio_toggle_with_hal_dso} und \ref{fig:gpio_toggle_with_hal_dso_zoom} dargestellt.

\begin{figure}[H]
    \centering
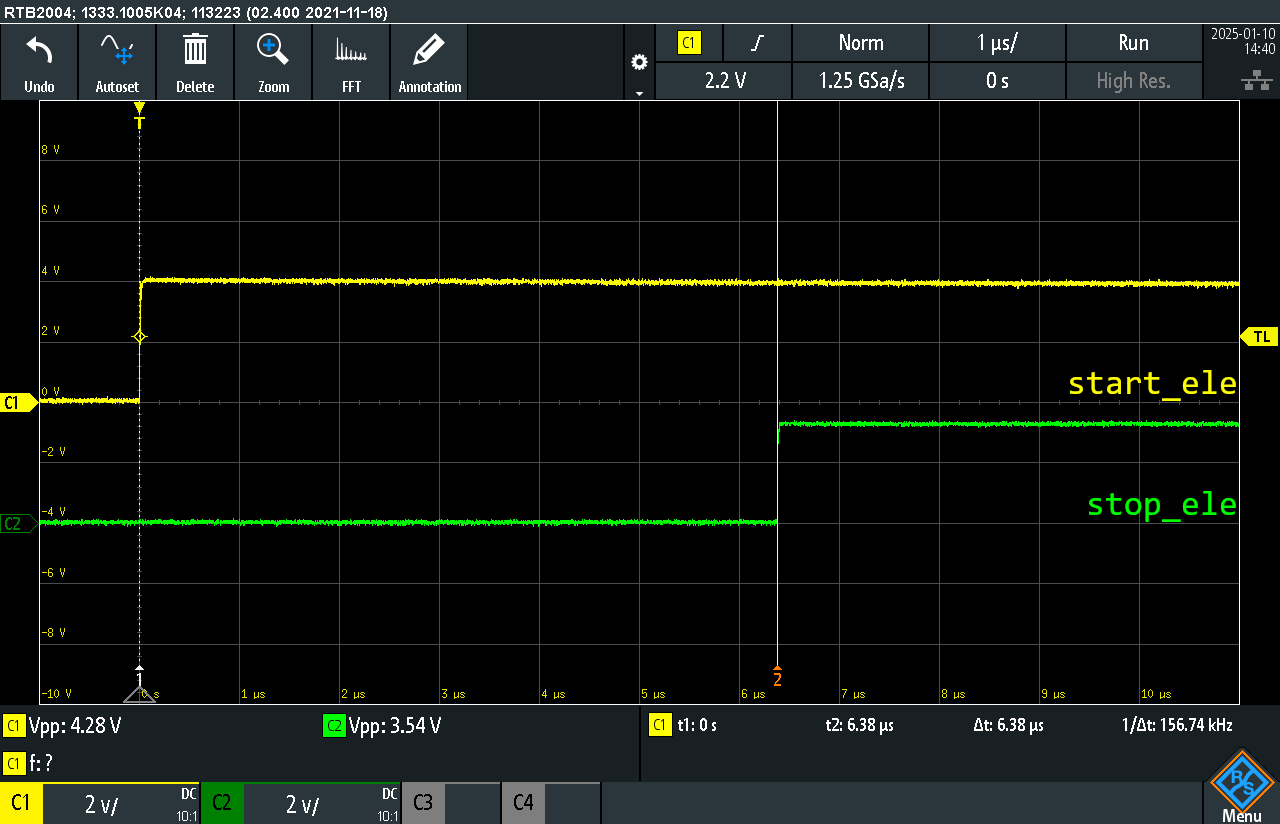
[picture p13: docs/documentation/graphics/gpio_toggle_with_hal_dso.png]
    
    \caption{\acrshort{gpio} Toggle mit \acrshort{hal} - \acrshort{dso}}\label{fig:gpio_toggle_with_hal_dso}
\end{figure}

\begin{figure}[H]
    \centering
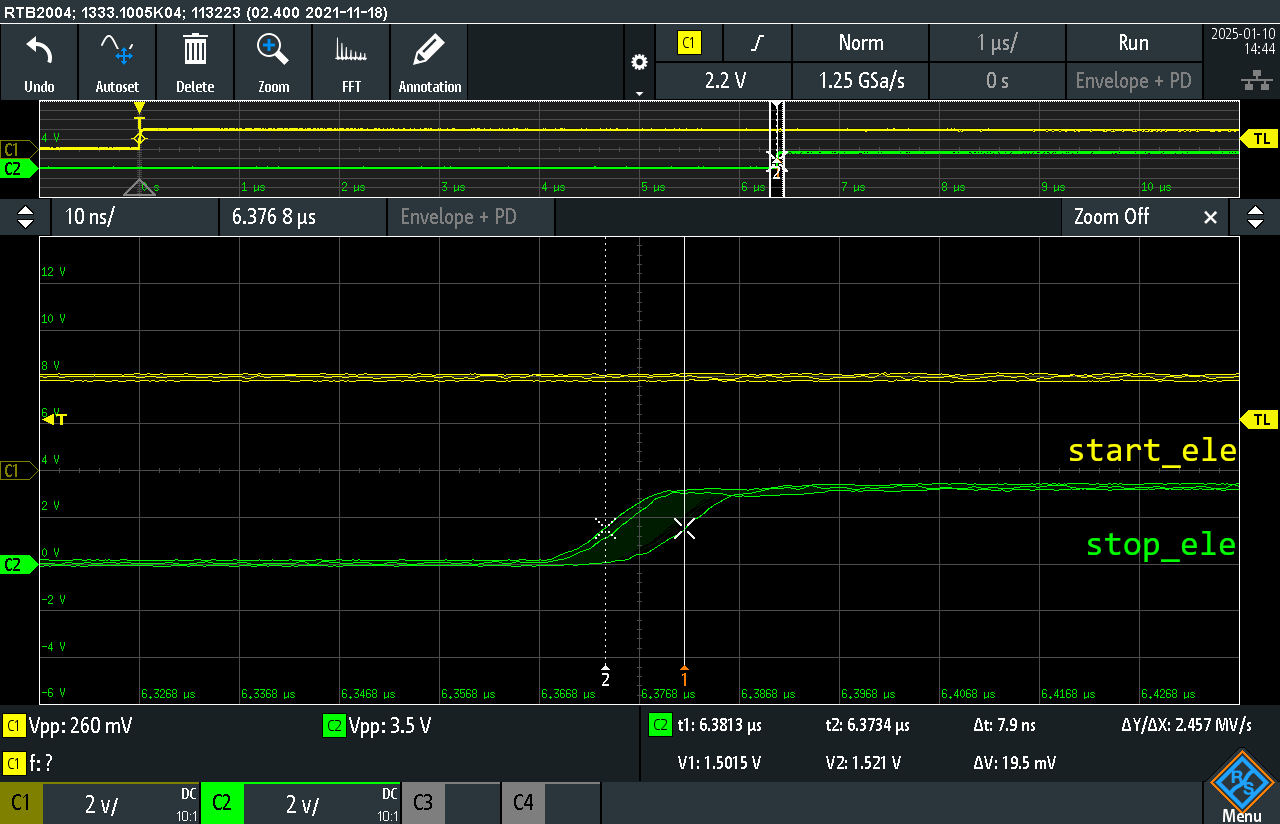
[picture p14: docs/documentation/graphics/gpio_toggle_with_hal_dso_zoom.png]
    
    \caption{\acrshort{gpio} Toggle mit \acrshort{hal} - \acrshort{dso} (Zoom)}\label{fig:gpio_toggle_with_hal_dso_zoom}
\end{figure}

\subsubsection{GPIO Toggle ohne HAL}\label{sec:gpio_toggle_without_hal}

Als nächstes wird gemessen wie lange es für die \acrshort{cpu} der \acrshort{mcu} dauert mit direktem Register-Zugriff
(via Pointer; ohne \acrshort{hal}-Library) zwei \acrshort{gpio}-Pins zu schalten.

In Code~\ref{code:gpio_toggle_without_hal} ist die Firmware-Implementation dazu gezeigt.

\lstinputlisting[language={C}, label={code:gpio_toggle_without_hal}, caption={\acrshort{gpio} Toggle ohne \acrshort{hal}}]{sourcecode/gpio_toggle_without_hal.c}

Der \acrshort{tdc} misst also die Zeit zwischen Zeile 15 und 16 in Code~\ref{code:gpio_toggle_without_hal}. Dazu wird,
wie in Kapitel \ref{sec:gpio_toggle_with_hal}, der STOP-Pin des \acrshort{tdc} via \lstinline|SW1| mit
\lstinline|stop_ele| verbunden. Der Kabelanschluss \lstinline|J3| wird kurzgeschlossen. Siehe
Abbildung~\ref{fig:tdc_ele_signal}.

Via \acrshort{uart} wurden 2000 Messwerte erfasst. Ein Ausschnitt davon ist in Code
\ref{code:gpio_toggle_without_hal_log} gezeigt. Die restlichen Daten befinden sich im elektronischen Anhang.

\lstinputlisting[language={}, label={code:gpio_toggle_without_hal_log}, caption={\acrshort{gpio} Toggle ohne \acrshort{hal}}]{sourcecode/gpio_toggle_without_hal_log.txt}

Arithmetischer Mittelwert und Standardabweichung sind in Formel \ref{eq:gpio_toggle_without_hal} aufgeführt.

\begin{equation}\label{eq:gpio_toggle_without_hal}
    \begin{split}
        \overline{ToF} &= 1'377'773~ps\\
        \sigma         &= 402~ps
    \end{split}
\end{equation}
\myequations{\acrshort{gpio} Toggle ohne \acrshort{hal}}

Da die \acrshort{cpu} mit 8~MHz läuft, lässt sich daraus schliessen, dass ein Pin-Toggle ohne \acrshort{hal} ca. 10
\acrshort{cpu}-Cycles benötigt. Dies erscheint plausibel.

Histogramm und Boxplot sind in Abbildung~\ref{fig:gpio_toggle_without_hal_histogram} bzw.
\ref{fig:gpio_toggle_without_hal_boxplot} dargestellt.

\begin{figure}[H]
    \centering
    \includesvg[width=0.8\textwidth]{graphics/gpio_toggle_without_hal_histogram.svg}
    \caption{\acrshort{gpio} Toggle ohne \acrshort{hal} - Histogramm}\label{fig:gpio_toggle_without_hal_histogram}
\end{figure}

\begin{figure}[H]
    \centering
    \includesvg[width=0.8\textwidth]{graphics/gpio_toggle_without_hal_boxplot.svg}
    \caption{\acrshort{gpio} Toggle ohne \acrshort{hal} - Boxplot}\label{fig:gpio_toggle_without_hal_boxplot}
\end{figure}

Um die Resultate des \acrshort{tdc} zu validieren, wurde dieselbe Messung auch mittels \acrfull{dso} durchgeführt. Die
Messungen sind in Abbildung~\ref{fig:gpio_toggle_without_hal_dso} und \ref{fig:gpio_toggle_without_hal_dso_zoom}
dargestellt.

\begin{figure}[H]
    \centering
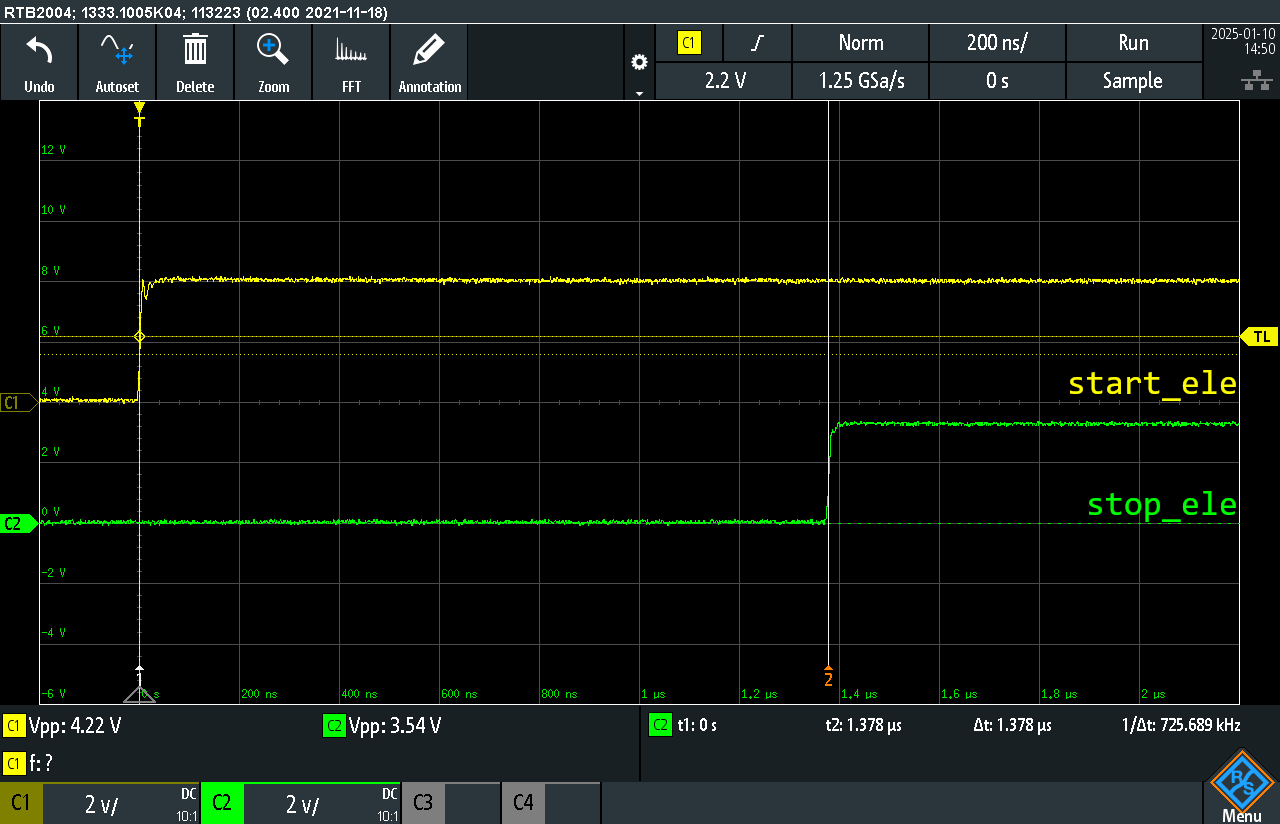
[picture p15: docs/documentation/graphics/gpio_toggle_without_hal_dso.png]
    
    \caption{\acrshort{gpio} Toggle ohne \acrshort{hal} - \acrshort{dso}}\label{fig:gpio_toggle_without_hal_dso}
\end{figure}

\begin{figure}[H]
    \centering
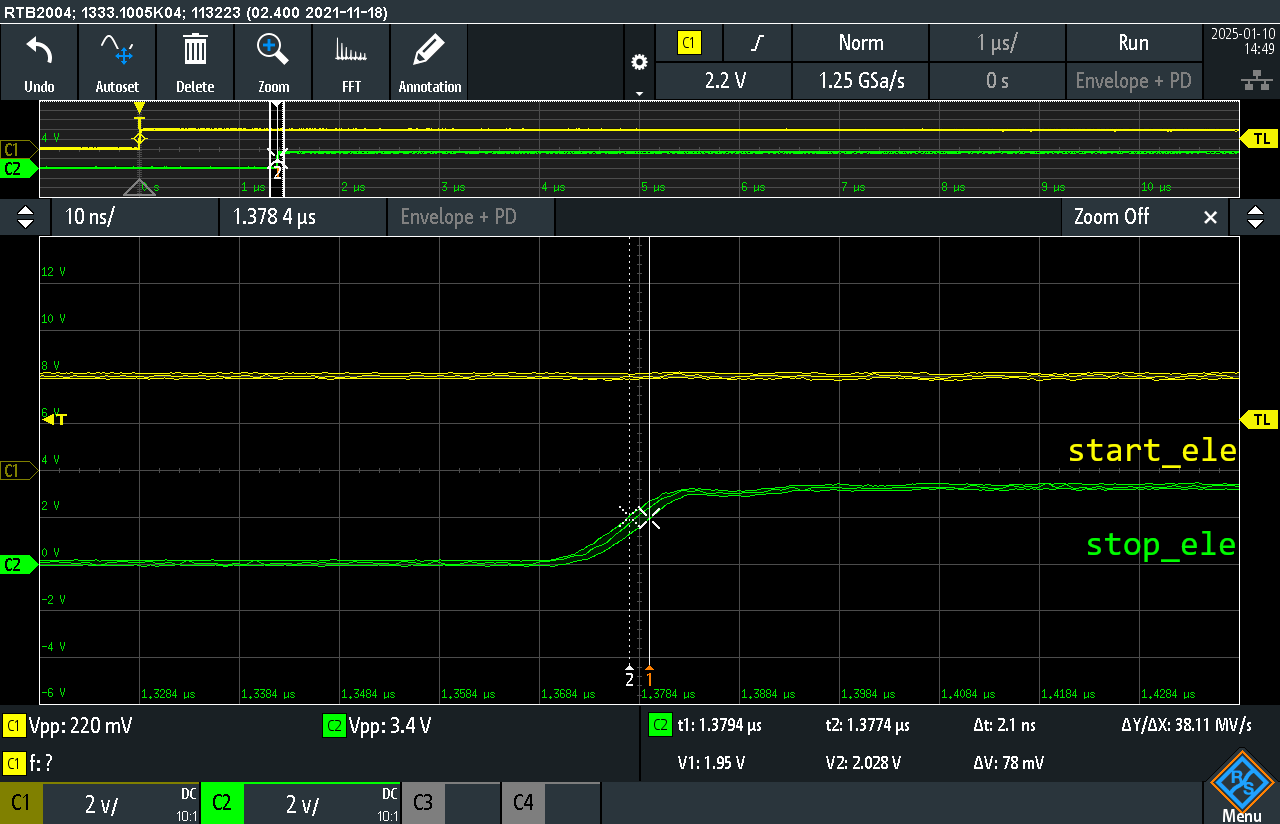
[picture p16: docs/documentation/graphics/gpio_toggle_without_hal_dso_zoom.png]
    
    \caption{\acrshort{gpio} Toggle ohne \acrshort{hal} - \acrshort{dso} (Zoom)}\label{fig:gpio_toggle_without_hal_dso_zoom}
\end{figure}

\subsubsection{Unterschiedliche Kabellängen}\label{sec:different_cable_lengths}

Für diese Messung wird dasselbe Setup wie in Kapitel \ref{sec:gpio_toggle_without_hal} verwendet.

Anstelle eines Kurzschlusses von \lstinline|J3| (siehe Abbildung \ref{fig:tdc_ele_signal}) werden nun verschiedene
Kabellängen angeschlossen.

Als Kabel wird ein einzelner, isolierter Kupferdraht ($\diameter_{cu} = 0.8~mm$, $\diameter_{ges} = 1.6~mm$) verwendet.

Es hat sich herausgestellt, dass eine kreisförmige Anordnung des Kabels wichtig ist. Denn bei einer Überlappung der
beiden Kabelenden werden kürze Zeiten gemessen. Dies hat mit der kapazitiven Kopplung zwischen den Leitern zu tun.

Die Resultate sind in Abbildung~\ref{fig:different_cable_lengths} dargestellt. Die Liste mit den Datenpunkten befindet
sich im elektronischen Anhang.

\begin{figure}[H]
    \centering
    \includesvg[width=0.9\textwidth]{graphics/different_cable_lengths.svg}
    \caption{Unterschiedliche Kabellängen}\label{fig:different_cable_lengths}
\end{figure}

Die arithmetischen Mittelwerte und Standardabweichungen sind in Tabelle \ref{tab:different_cable_lengths} aufgeführt.

\begin{table}[H]
    \mytable
        {|l|l|l|}
        {\textbf{Länge} & \textbf{Mittelwert} & \textbf{Standardabweichung}}
        {\length & \mean & \stddev}
        {tables/different_cable_lengths.csv}
    \caption{Unterschiedliche Kabellängen}\label{tab:different_cable_lengths}
\end{table}

Die Signal-Ausbreitungs-Geschwindigkeit in Kupfer beträgt ca. $\sfrac{2}{3}$ der Lichtgeschwindigkeit
\cite{firewallcx2025propagationdelay}. Um die Resultate in Tabelle \ref{tab:different_cable_lengths} zu validieren,
rechnen wir wie in Formel \ref{eq:cable_length} gezeigt, auf die Kabellänge zurück. Die Laufzeit bei 0~m wird dabei
abgezogen, um die Verzögerung zu kompensieren, welche durch das Schalten der \acrshort{gpio}s entsteht.

\begin{equation}\label{eq:cable_length}
    \begin{split}
        c_{cu} &\approx \frac{2}{3} \cdot c_0 = \frac{2}{3} \cdot 299'792'458~\frac{m}{s} \approx 200'000'000~\frac{m}{s}\\
        ToF_{n} &= ToF_{n_{abs}} - ToF_{0}\\
        l_{n}   &= ToF_{n} \cdot c_{cu}
    \end{split}
\end{equation}
\myequations{Zurückrechnen auf Kabellänge}

Die Resultate sind in Tabelle \ref{tab:different_cable_lengths_calc} dargestellt.

\begin{table}[H]
    \mytable
        {|l|l|l|}
        {\textbf{Tatsächliche Länge} & \textbf{ToF}$\mathbf{_n}$ & \textbf{Zurückgerechnete Länge}}
        {\reallength & \tofn & \calclength}
        {tables/different_cable_lengths_calc.csv}
    \caption{Kabellängen zurückgerechnet}\label{tab:different_cable_lengths_calc}
\end{table}

Es fällt auf, dass die Resultate nicht genau übereinstimmen. Es ist jedoch eine klare Korrelation zu erkennen.

Der Unterschied könnte verschiedene Ursachen haben. Eine mögliche Erklärung wäre, dass die Ausbreitungs-Geschwindigkeit
beim verwendeten Kabel näher an der Lichtgeschwindigkeit ist als angenommen. Weitere Messresultate und Auswertungen
dazu in Kapitel~\ref{sec:different_cable_lengths_with_dso}.

\subsubsection{Mode 1 vs. Mode 2}

Der TDC7200 unterstützt zwei Modi mit unterschiedlichen Messbereichen \cite{ti2016tdc7200_datasheet}:

\begin{itemize}
    \item Mode 1: 12~ns bis 500~ns
    \item Mode 2: 250~ns bis 8~ms
\end{itemize}

Im Mode~1 wird nur der interne Ring-Oszillator des \acrshort{tdc} verwendet. Siehe dazu Abbildung~\ref{fig:tdc_mode1}.

\begin{figure}[H]
    \centering
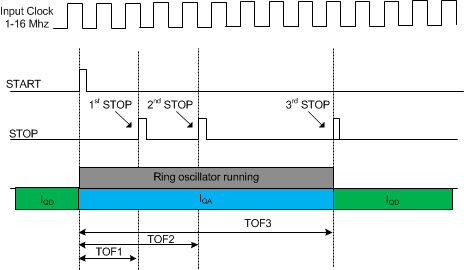
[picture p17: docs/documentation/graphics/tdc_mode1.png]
    
    \caption[\acrshort{tdc} Mode 1]{\acrshort{tdc} Mode 1 \cite{ti2016tdc7200_datasheet}}\label{fig:tdc_mode1}
\end{figure}

Im Mode~2, um längere Zeiten messen zu können, wir zusätzlich der externe Clock des \acrshort{tdc} verwendet. Siehe dazu
Abbildung~\ref{fig:tdc_mode2}.

\begin{figure}[H]
    \centering
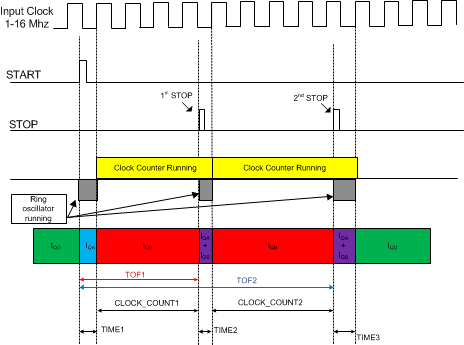
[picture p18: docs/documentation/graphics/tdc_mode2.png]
    
    \caption[\acrshort{tdc} Mode 2]{\acrshort{tdc} Mode 2 \cite{ti2016tdc7200_datasheet}}\label{fig:tdc_mode2}
\end{figure}

Die bisherigen Messungen (Kapitel~\ref{sec:gpio_toggle_with_hal}, \ref{sec:gpio_toggle_without_hal} und
\ref{sec:different_cable_lengths}) wurden im Mode~2 durchgeführt, da das Schalten der \acrshort{gpio}s mit der
\acrshort{cpu} mehr als 500~ns brauchte.

In künftigen Messungen soll das Schalten der \acrshort{gpio}s von einem Hardware-Timer der \acrshort{mcu} erledigt
werden. Damit werden Schaltzeiten von 125~ns bei 8~MHz bzw. 20.8~ns bei 48~MHz möglich sein. Es soll deshalb in diesem
Kapitel ein Vergleich der Messresultate der beiden Modi gemacht werden.

Dazu wurden drei Messungen gemacht:
\begin{enumerate}
    \item \acrshort{gpio} Toggle ohne \acrshort{hal} im Mode~2 mit Kabellänge~=~0~m (wie in Kapitel~\ref{sec:gpio_toggle_without_hal} und \ref{sec:different_cable_lengths})
    \item \acrshort{gpio} Toggle ohne \acrshort{hal} im Mode~2 mit Kabellänge~=~6~m (wie in Kapitel~\ref{sec:different_cable_lengths})
    \item Ohne GPIO Toggle Im Mode~1 mit Kabellänge~=~6~m
\end{enumerate}

Für die Messung im Mode~1 soll auf die Verzögerung durch das Schalten der \acrshort{gpio}s verzichtet werden. Dazu wird
das \lstinline|START|- und \lstinline|STOP|-Signal vom selben \acrshort{gpio}-Pin, \lstinline|start_ele|, generiert.
Dazu wird \lstinline|SW1| mit \lstinline|start_ele| verbunden (siehe Abbildung~\ref{fig:tdc_ele_signal}).

In Code~\ref{code:mode1} ist die Firmware-Implementation für eine Messung im Mode~1 gezeigt.

\lstinputlisting[language={C}, label={code:mode1}, caption={Mode 1}]{sourcecode/mode1.c}

Die Unterschiede im Vergleich zu den Messungen in Kapitel~\ref{sec:gpio_toggle_without_hal} und
\ref{sec:different_cable_lengths} sind:

\begin{itemize}
    \item Zeile 7: \acrshort{tdc} wird im Mode~1 konfiguriert (anstatt Mode~2)
    \item Zeile 15 und 23: Es wird nur der \lstinline|start_ele| Pin getoggelt (anstatt \lstinline|start_ele| und \lstinline|stop_ele| Pin)
\end{itemize}

Die Erwartung ist, dass die Differenz aus Messung~1 und Messungen~2 ungefähr dem Resultat aus Messung~3 entspricht.

Die Resultate dieser drei Messungen sind in Tabelle \ref{tab:mode1_vs_mode2} aufgeführt. Die restlichen Daten befinden
sich im elektronischen Anhang.

\begin{table}[H]
    \mytable
        {|l|l|l|}
        {\textbf{Messung} & \textbf{Mittelwert} & \textbf{Standardabweichung}}
        {\measurement & \mean & \stddev}
        {tables/mode1_vs_mode2.csv}
    \caption{Mode 1 vs. Mode 2}\label{tab:mode1_vs_mode2}
\end{table}

Die Berechnung in Formel~\ref{eq:mode1_vs_mode2} zeigt, dass die Messresultate nahe beieinander liegen.

\begin{equation}\label{eq:mode1_vs_mode2}
    \begin{split}
        \Delta Mode~2 &= 1'403'224~ps - 1'378'222~ps = 25'001~ps\\
        Mode~1        &= 25'145~ps
    \end{split}
\end{equation}
\myequations{Mode 1 vs. Mode 2}

Es kann also davon ausgegangen werden, dass Mode~1 und Mode~2 im Firmware-Treiber korrekt implementiert wurden.

Bemerkung: Im Firmware-Treiber (siehe Anhang~\ref{sec:tdc_driver}) kann für beide Modi dieselbe Funktion
\lstinline|TDC_read_result()| verwendet werden. Für Mode~1 vereinfacht sich die Berechnung, weil \lstinline|TIME2|~=~0
und \lstinline|CLOCK_COUNT1|~=~0.

\subsubsection{Timer Output}\label{sec:timer_output}

In Kapitel~\ref{sec:gpio_toggle_with_hal} und \ref{sec:gpio_toggle_without_hal} wurge gezeigt, dass es einige
\acrshort{cpu}-Cycles dauert, um  mittels Software, also mit \acrshort{cpu}-Instruktionen, \acrshort{gpio}s zu toggeln.

Eine schnellere Methode ist es, das Toggeln der \acrshort{gpio}s von der Hardware-Peripherie der \acrshort{mcu}
erledigen zu lassen. Dazu eignen sich Hardware-Timer.

In Abbildung \ref{fig:clock_config_default} ist die default Clock-Configuration des Nucleo-Boards gezeigt.

\begin{figure}[H]
    \centering
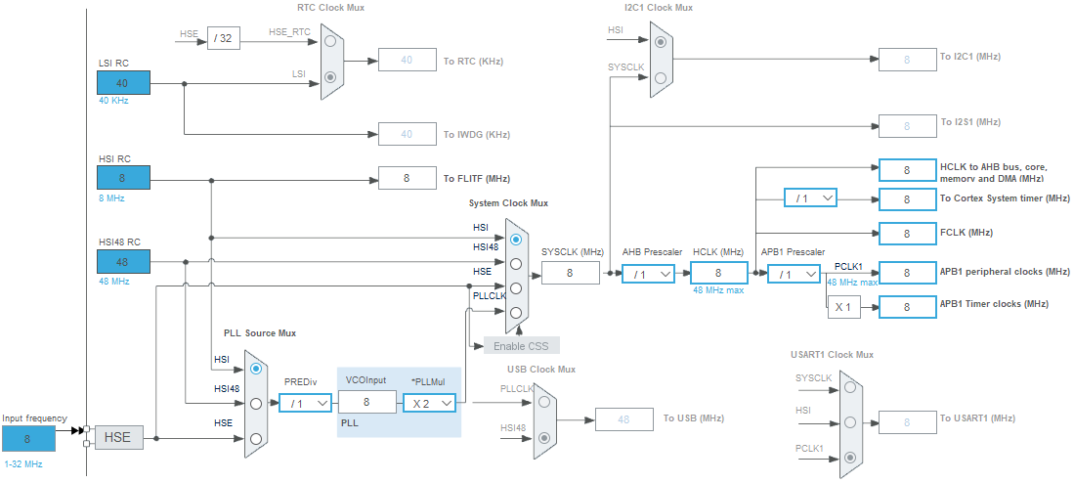
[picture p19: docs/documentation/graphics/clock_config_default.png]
    
    \caption{Default Clock-Configuration}\label{fig:clock_config_default}
\end{figure}

Per default wird der \acrfull{hsi} Clock mit 8~MHz verwendet. Damit sollte es mit Hardware-Timer möglich sein, zwei
\acrshort{gpio}s zu schalten mit einer Verzögerung gemäss Formel~\ref{eq:gpio_schalten_zeit}.

\begin{equation}\label{eq:gpio_schalten_zeit}
    t = \frac{1}{8~MHz} = 125~ns
\end{equation}
\myequations{\acrshort{gpio}-Schalten Verzögerungszeit}

Dazu werden Kanal \lstinline|CH1| und \lstinline|CH4| des Hardware-Timers \lstinline|TIM1| im Output Compare Match Modus
verwendet. Die zugeordneten \acrshort{gpio}-Pins sind \lstinline|start_ele| bzw. \lstinline|stop_ele|.

Erreicht der 16~bit Timer den Wert \lstinline|32'000| wird \lstinline|start_ele| auf High geschalten. Beim Erreichen des
Werts \lstinline|32'001| wird \lstinline|stop_ele| auf High geschalten.

Der \acrshort{tdc} wird in Mode 1 konfiguriert. Der STOP-Pin des \acrshort{tdc} wird via \lstinline|SW1| mit
\lstinline|stop_ele| verbunden. Der Kabelanschluss \lstinline|J3| wird kurzgeschlossen. Siehe
Abbildung~\ref{fig:tdc_ele_signal}.

In Code~\ref{code:timer_output} ist die Firmware-Implementation dazu gezeigt.

\lstinputlisting[language={C}, label={code:timer_output}, caption={\acrshort{gpio} Toggle mit Timer-Output}]{sourcecode/timer_output.c}

Der gemessene arithmetische Mittelwert und die Standardabweichung sind in Formel~\ref{eq:timer_output} aufgeführt.  Die
Liste mit den Datenpunkten befindet sich im elektronischen Anhang.

\begin{equation}\label{eq:timer_output}
    \begin{split}
        \overline{ToF} &=128'108~ps\\
        \sigma         &= 81~ps
    \end{split}
\end{equation}
\myequations{\acrshort{gpio} Toggle mit Timer-Output}

Erwartungsgemäss dauert das Schalten der \acrshort{gpio}s ca. 125~ns. Die Standardabweichung ist aufgrund der kleineren
Anzahl an Clock-Cycles tiefer als in den bisherigen Kapiteln.

\subsubsection{Unterschiedliche Clock-Konfigurationen}

In diesem Teilkapitel werden Messungen mit demselben Setup wie in Kapitel~\ref{sec:timer_output} durchgeführt.

Es werden die arithmetischen Mittelwerte und die Standardabweichungen verschiedener Clock-Quellen des Nucleo-Boards
verglichen. Es werden drei Messungen gemacht:

\begin{enumerate}
    \item \acrshort{hsi}: 8~MHz (wie in Kapitel~\ref{sec:timer_output})
    \item \acrshort{hsi} mit \acrshort{pll}: 16~MHz
    \item \acrshort{hsi}48: 48~MHz
\end{enumerate}

Die Clock-Konfigurationen für Messung 2 und 3 sind in Abbildung~\ref{fig:clock_config_hsi_pll_16mhz} bzw.
\ref{fig:clock_config_hsi48_48mhz} dargestellt.

\begin{figure}[H]
    \centering
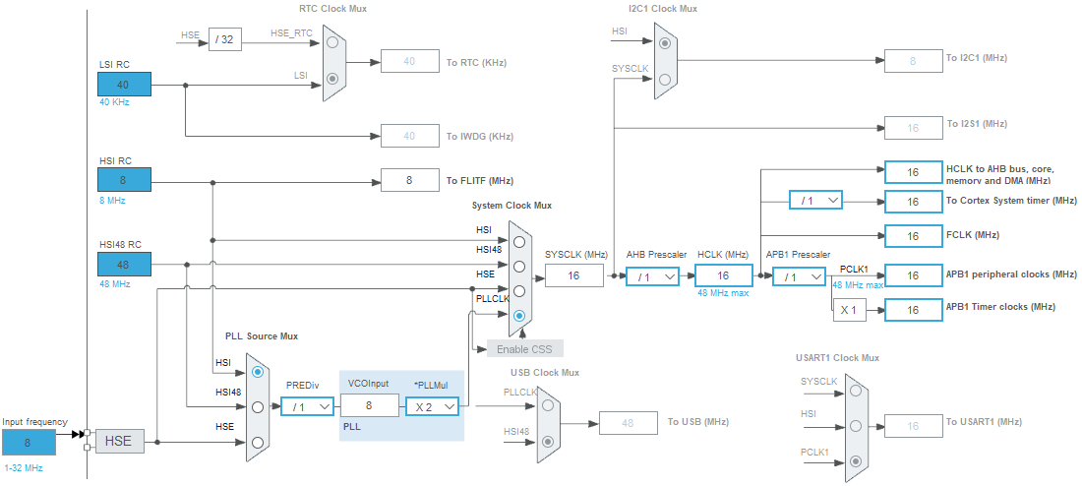
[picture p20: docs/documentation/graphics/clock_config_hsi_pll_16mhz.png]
    
    \caption{Clock-Configuration \acrshort{hsi} mit \acrshort{pll} 16~MHz}\label{fig:clock_config_hsi_pll_16mhz}
\end{figure}

\begin{figure}[H]
    \centering
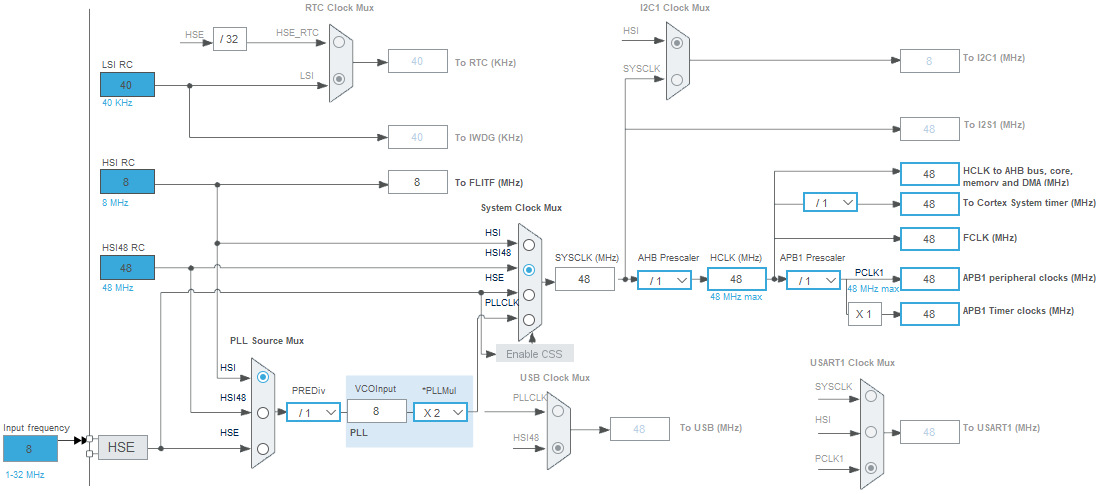
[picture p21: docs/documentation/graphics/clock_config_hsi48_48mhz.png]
    
    \caption{Clock-Configuration \acrshort{hsi}48 48~MHz}\label{fig:clock_config_hsi48_48mhz}
\end{figure}

Die arithmetischen Mittelwerte und Standardabweichungen sind in Tabelle~\ref{tab:different_clock_sources} dargestellt.
Die Liste mit den Datenpunkten befindet sich im elektronischen Anhang.

\begin{table}[H]
    \mytable
        {|l|l|l|}
        {\textbf{Messung} & \textbf{Mittelwert} & \textbf{Standardabweichung}}
        {\measurement & \mean & \stddev}
        {tables/different_clock_sources.csv}
    \caption{Unterschiedliche Clock-Quellen}\label{tab:different_clock_sources}
\end{table}

Die Resultate stimmen ungefähr mit den erwarteten Werten aus Formel~\ref{eq:gpio_schalten_zeiten} überein.

\begin{equation}\label{eq:gpio_schalten_zeiten}
    \begin{split}
        t_1 &= \frac{1}{8~MHz} = 125~ns\\
        t_2 &= \frac{1}{16~MHz} = 62.5~ns\\
        t_3 &= \frac{1}{48~MHz} = 20.8~ns
    \end{split}
\end{equation}
\myequations{\acrshort{gpio}-Schalten Verzögerungszeiten}

Im Datenblatt konnte eine Angabe zum \acrshort{pll}-Jitter gefunden werden, siehe Abbildung~\ref{fig:pll_jitter}.

\begin{figure}[H]
    \centering
    
    \caption[\acrshort{pll}-Jitter]{\acrshort{pll}-Jitter \cite{st2017stm32f042k6_datasheet}}\label{fig:pll_jitter}
\end{figure}

Diese Angabe ist ungefähr in derselben Grössenordnung wie die Messresultate.

\subsubsection{Unterschiedliche Kabellängen mit DSO}\label{sec:different_cable_lengths_with_dso}

In diesem Unterkapitel werden nochmals dieselben Kabellängen wie in Kapitel~\ref{sec:different_cable_lengths}
ausgemessen.

Es wird die folgende Firmware-Konfiguration verwendet, um den Jitter zu reduzieren:

\begin{itemize}
    \item \acrshort{tdc}: Modus 1
    \item Clock: 48~MHz
    \item Schalten der \acrshort{gpio}s: Timer Output
\end{itemize}

Zusätzlich werden die verschiedenen Kabellängen gleichzeitig auch via \acrshort{dso} (Rohde \& Schwarz RTB2004 2.5 GSa/s.)
ausgemessen, um die Resultate des \acrshort{tdc} damit zu vergleichen.

In Abbildung~\ref{fig:different_cable_lengths_with_dso_tdc} sind die erfassten Messresultate des \acrshort{tdc}
dargestellt. Während dem Erfassen der Messwerte war das \acrshort{dso} an den Pins angeschlossen. Die Liste mit den
Datenpunkten befindet sich im elektronischen Anhang.

\begin{figure}[H]
    \centering
    \includesvg[width=0.9\textwidth]{graphics/different_cable_lengths_with_dso_tdc.svg}
    \caption{Unterschiedliche Kabellängen - Messwerte \acrshort{tdc}}\label{fig:different_cable_lengths_with_dso_tdc}
\end{figure}

In Tabelle~\ref{tab:different_cable_lengths_with_dso_tdc} sind die Mittelwerte und die Standardabweichungen der
erfassten Messresultate des \acrshort{tdc} aufgelistet.

\begin{table}[H]
    \mytable
        {|l|l|l|l|}
        {\textbf{Länge} & \textbf{Mittelwert} & \textbf{Standardabweichung} & \textbf{$\Delta$ zu 0~m}}
        {\length & \mean & \stddev & \diff}
        {tables/different_cable_lengths_with_dso_tdc.csv}
    \caption{Unterschiedliche Kabellängen - Resultate \acrshort{tdc}}\label{tab:different_cable_lengths_with_dso_tdc}
\end{table}

In Tabelle~\ref{tab:different_cable_lengths_with_dso_dso} sind die erfassten Messresultate des \acrshort{dso}
aufgelistet. Die letzte Spalte zeigt den Unterschied zwischen \acrshort{dso} und \acrshort{tdc}. Es ist zu erkennen,
dass der Unterschied sehr klein ist.

\begin{table}[H]
    \mytable
        {|l|l|l|l|}
        {\textbf{Länge} & \textbf{Wert} & \textbf{$\Delta$ zu 0~m} & \textbf{$\Delta$ zu TDC}}
        {\length & \measurement & \diff & \difftdc}
        {tables/different_cable_lengths_with_dso_dso.csv}
    \caption{Unterschiedliche Kabellängen - Resultate \acrshort{dso}}\label{tab:different_cable_lengths_with_dso_dso}
\end{table}

Tabelle~\ref{tab:different_cable_lengths_with_dso_theorie} zeigt die theoretisch zu erwartenden Laufzeiten bei den
unterschiedlichen Annahmen für die Signalausbreitungs-Geschwindigkeiten von $\sfrac{2}{3}~c$ und $c$.

\begin{table}[H]
    \mytable
        {|l|l|l|}
        {\textbf{Länge} & \textbf{Theorie} $\mathbf{\sfrac{2}{3}~c}$ & \textbf{Theorie c}}
        {\length & \theoriekc & \theoriec}
        {tables/different_cable_lengths_with_dso_theorie.csv}
    \caption{Unterschiedliche Kabellängen - Theoretische Erwartung}\label{tab:different_cable_lengths_with_dso_theorie}
\end{table}

Die Unterschiede der \acrshort{tdc}-Resultate zu den theoretischen Erwartungen sind in den
Tabellen~\ref{tab:different_cable_lengths_with_dso_theorie_vs_tdc_ns} und
\ref{tab:different_cable_lengths_with_dso_theorie_vs_tdc_m} dargestellt. Zuerst im Bezug auf den Laufzeit-Unterschied,
dann die zurückgerechnete Kabellänge.

\begin{table}[H]
    \mytable
        {|l|l|l|}
        {\textbf{Länge} & \textbf{$\Delta$ TDC zu Theorie} $\mathbf{\sfrac{2}{3}~c}$ & \textbf{$\Delta$ TDC Theorie zu c}}
        {\length & \tdczutheoriekc & \tdczutheoriec}
        {tables/different_cable_lengths_with_dso_theorie_vs_tdc_ns.csv}
    \caption{Unterschiedliche Kabellängen - Unterschied \acrshort{tdc} [ns] zu Theorie}\label{tab:different_cable_lengths_with_dso_theorie_vs_tdc_ns}
\end{table}

\begin{table}[H]
    \mytable
        {|l|l|l|}
        {\textbf{Länge} & \textbf{TDC gem. Theorie} $\mathbf{\sfrac{2}{3}~c}$ & \textbf{TDC gem. Theorie c}}
        {\length & \tdcgemtheoriekc & \tdcgemtheoriec}
        {tables/different_cable_lengths_with_dso_theorie_vs_tdc_m.csv}
    \caption{Unterschiedliche Kabellängen - \acrshort{tdc} [m] gem. Theorie}\label{tab:different_cable_lengths_with_dso_theorie_vs_tdc_m}
\end{table}

In Tabelle~\ref{tab:different_cable_lengths_with_dso_theorie_vs_tdc_m} ist zu erkennen, dass keine der beiden
theoretischen Werte für $c$ zu einem perfekten \acrshort{tdc}-Resultat für die zurückgerechnete Distanz [m] führt.

In Tabelle~\ref{tab:different_cable_lengths_with_dso_theorie_vs_tdc_ns} ist zu erkennen, dass die Differenz der
\acrshort{tdc}-Resultate zur theoretisch zu erwartenden Laufzeit bei $c$ etwas kleiner ist als bei $\sfrac{2}{3}~c$. Es
scheint, dass $c$ eine etwas bessere Näherung darstellt.

Falls sich der gemessene Unterschied tatsächliche durch eine falsche Annahme der Ausbreitungs-Geschwindigkeit erklären
lässt, dann müsst die Ausbreitungs-Geschwindigkeit im gewählten Kabel bei ca. $0.9~c$ liegen. Die zurückrechneten
Resultate dazu sind in Tabelle~\ref{tab:different_cable_lengths_with_dso_theorie09_vs_tdc_m} aufgelistet.

\begin{table}[H]
    \mytable
        {|l|l|}
        {\textbf{Länge} & \textbf{TDC gem. Theorie 0.9 c}}
        {\length & \tdcgemtheoriemc}
        {tables/different_cable_lengths_with_dso_theorie09_vs_tdc_m.csv}
    \caption{Unterschiedliche Kabellängen - \acrshort{tdc} [m] gem. Theorie 0.9 c}\label{tab:different_cable_lengths_with_dso_theorie09_vs_tdc_m}
\end{table}

In den Abbildungen~\ref{fig:different_cable_lengths_with_dso_1m} und \ref{fig:different_cable_lengths_with_dso_6m} sind
die \acrshort{dso}-Aufzeichnungen bei den Kabellängen 1~m bzw. 6~m gezeigt. Die restlichen \acrshort{dso}-Aufzeichnungen
befinden sich im elektronischen Anhang.

\begin{figure}[H]
    \centering
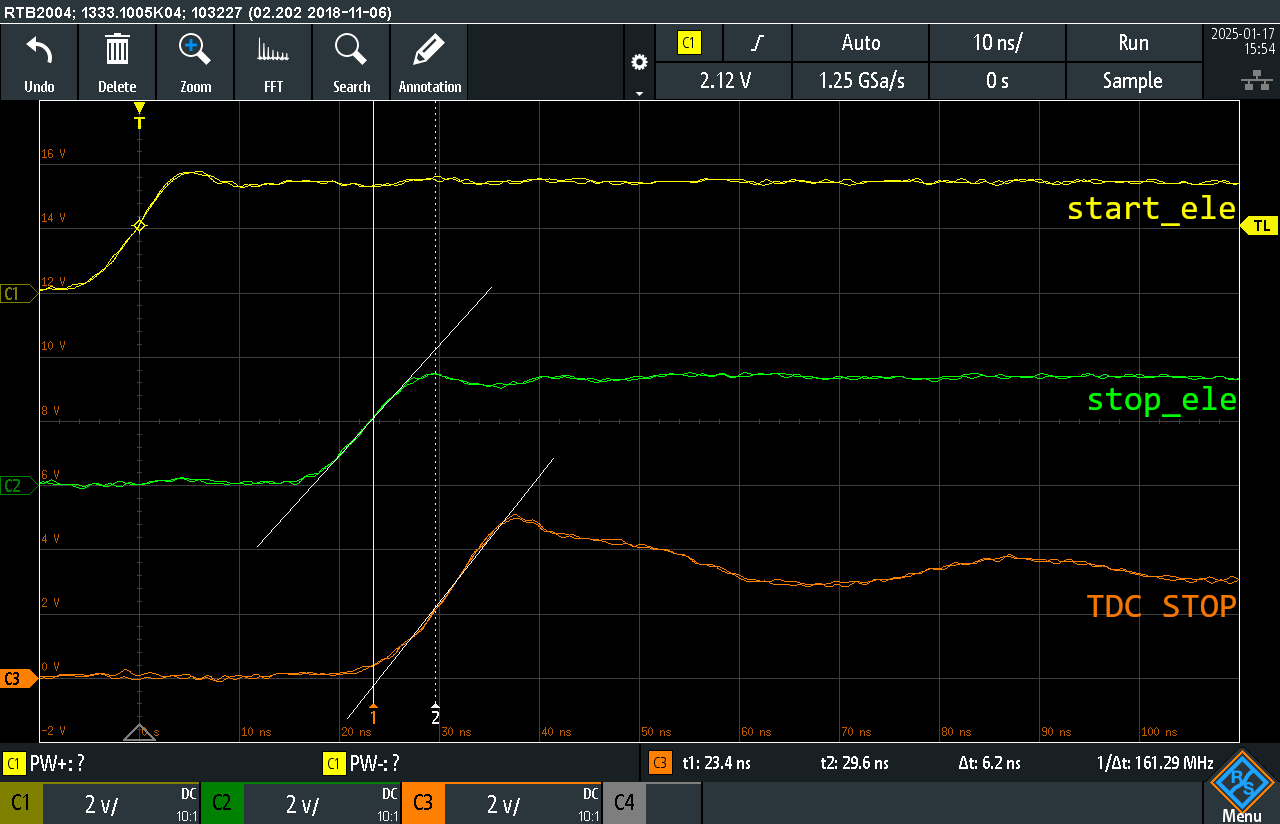
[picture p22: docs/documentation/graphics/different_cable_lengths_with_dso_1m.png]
    
    \caption{\acrshort{dso}-Aufzeichnung bei Kabellänge 1~m}\label{fig:different_cable_lengths_with_dso_1m}
\end{figure}
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

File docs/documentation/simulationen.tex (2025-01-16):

In diesem Kapitel werden die durchgeführten Simulationen dokumentiert.

Zur Simulation wird das Tool \dq Xpedition AMS\dq\ von Siemens verwendet. Wie der Name sagt, unterstützt dieses Tool
\acrfull{ams} Analyse. \cite{siemens2025xpeditionams}

\subsection{Laser Treiber}

In Abbildung~\ref{fig:simulation_laser_driver_schematic} ist das Schema für die Simulation des Laser-Treibers
dargestellt. Dies entspricht der Schaltung aus Kapitel~\ref{sec:schematic_laser_driver}.

\begin{figure}[H]
    \centering
    
    \caption{Simulation Laser-Treiber - Schema}\label{fig:simulation_laser_driver_schematic}
\end{figure}

Das SPICE-Modell des Gate-Treibers LMG1025-Q1 ist dasselbe wie für LMG1020 und wurde von der Website von TI
heruntergeladen \cite{ti2024lmg1025q1}.

Das SPICE-Modell des NexFET CSD17578Q3A wurde ebenfalls von der Website von TI heruntergeladen
\cite{ti2024csd17578q3a}.
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

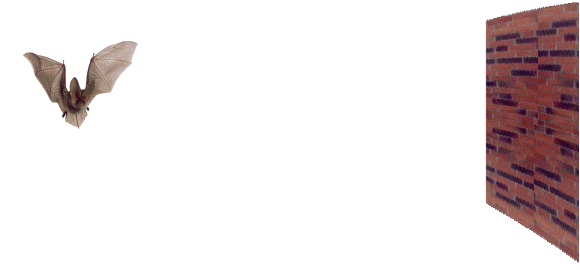
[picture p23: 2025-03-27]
docs/presentation/english/animations/fledermaus.gif

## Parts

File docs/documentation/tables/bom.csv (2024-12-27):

Reference | Value | Datasheet | Footprint | Qty | DNP
C1,C4,C22,C23,C26,C28 | 100n | ~ | Capacitor\_SMD:C\_0402\_1005Metric\_Pad0.74x0.62mm | 6
C2,C3 | 1u | ~ | Capacitor\_SMD:C\_0402\_1005Metric\_Pad0.74x0.62mm | 2
C5,C6,C7,C8 | 1u | ~ | Capacitor\_SMD:C\_0402\_1005Metric\_Pad0.74x0.62mm | 4 | DNP
C20 | 1p | ~ | Capacitor\_SMD:C\_0402\_1005Metric\_Pad0.74x0.62mm | 1
C21 | 10p | ~ | Capacitor\_SMD:C\_0402\_1005Metric\_Pad0.74x0.62mm | 1
C24,C29 | 2.2u | ~ | Capacitor\_SMD:C\_0603\_1608Metric\_Pad1.08x0.95mm | 2
C25,C27 | 6.8u | ~ | Capacitor\_Tantal\_SMD:CP\_EIA-7343-43\_Kemet-X\_Pad2.25x2.55mm | 2
D1 | NJL6401R-3-TE1 | \cite{jrc2014njl6401r3_datasheet} | NJL6401R3TE1 | 1
FB1,FB2 | FerriteBead | \cite{tdk2019mpz0402s100_datasheet} | Inductor\_SMD:L\_0402\_1005Metric\_Pad0.77x0.64mm | 2
IC1,IC2 | TDC7200PWR | \cite{ti2016tdc7200_datasheet} | SOP65P640X120-14N | 2
IC21 | 74LVC1G08QW5-7 | \cite{diodes202074lvc1g08q_datasheet} | 74LVC1G08QW57 | 1
IC22 | LMG1025QDEETQ1 | \cite{ti2024lmg1025q1_datasheet} | SON65P200X200X80-7N | 1
J1,J3 | Conn\_01x02\_Pin | ~ | Connector:Molex\_KK-254\_AE-6410-02A\_1x02\_P2.54mm\_Vertical | 2
J2 | Conn\_01x03\_Pin | ~ | Connector:Molex\_SL\_171971-0003\_1x03\_P2.54mm\_Vertical | 1
JP1,JP2 | Jumper\_2\_Open | ~ | TestPoint:TestPoint\_2Pads\_Pitch2.54mm\_Drill0.8mm | 2
JP3 | 12Vin select | ~ | TestPoint:TestPoint\_2Pads\_Pitch2.54mm\_Drill0.8mm | 1
LD1 | RLD65NZX1-00A | \cite{rohm2019rld65nzx1_datasheet} | RLD65NZX1-00A:RLD85PZJ400A | 1
R1,R4,R5 | 20k | ~ | Resistor\_SMD:R\_0402\_1005Metric\_Pad0.72x0.64mm | 3
R2 | 39k | ~ | Resistor\_SMD:R\_0402\_1005Metric\_Pad0.72x0.64mm | 1
R3 | 0 | ~ | Resistor\_SMD:R\_0402\_1005Metric\_Pad0.72x0.64mm | 1
R21 | 51 | ~ | Resistor\_SMD:R\_0402\_1005Metric\_Pad0.72x0.64mm | 1
R22 | 0 | ~ | Resistor\_SMD:R\_0402\_1005Metric\_Pad0.72x0.64mm | 1 | DNP
R23,R24 | 2 | ~ | Resistor\_SMD:R\_0402\_1005Metric\_Pad0.72x0.64mm | 2
R25 | 75 | ~ | Resistor\_SMD:R\_0603\_1608Metric\_Pad0.98x0.95mm | 1
R26 | 51k | ~ | Resistor\_SMD:R\_0402\_1005Metric\_Pad0.72x0.64mm | 1
R27 | 100 | ~ | Resistor\_SMD:R\_0402\_1005Metric\_Pad0.72x0.64mm | 1
RV21 | 10k | \cite{bourns20243224w210xe_datasheet} | Potentiometer\_SMD:Potentiometer\_Bourns\_3224W\_Vertical | 1
RV22,RV23 | 1k | \cite{bourns20243224w210xe_datasheet} | Potentiometer\_SMD:Potentiometer\_Bourns\_3224W\_Vertical | 2
SW1,SW2 | SW\_Nidec\_CAS-120A1 | \cite{nidec2024cas120a1_datasheet} | Button\_Switch\_SMD:Nidec\_Copal\_CAS-120A | 2
TP1..TP20 | Conn\_01x01\_Pin | ~ | Connector\_2.54mm:PinHeader\_1x01\_P2.54mm\_Vertical | 20
U1 | NUCLEO-F042K6 | \cite{st2019nucleof042k6_datasheet} | NUCLEO\_F042K6:MODULE\_NUCLEO-F042K6 | 1
U2 | OPA858xDSG | \cite{ti2018opa858_datasheet} | Package\_SON:WSON-8-1EP\_2x2mm\_P0.5mm\_EP0.9x1.6mm | 1
U3 | TLV3501AIDBV | \cite{ti2016tlv3501_datasheet} | Package\_TO\_SOT\_SMD:SOT-23-6 | 1
V1 | CSD17578Q3A | \cite{ti2016csd17578q3a_datasheet} | DNH0008A | 1
X1 | SG-5032CAN | \cite{epson2024sg5032can_datasheet} | Oscillator:Oscillator\_SMD\_SeikoEpson\_SG8002LB-4Pin\_5.0x3.2mm | 1
X2,X3 | G061041000 | \cite{qioptiq2024g061041000_datasheet} | user:Qioptiq\_Mount | 2

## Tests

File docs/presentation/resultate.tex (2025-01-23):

\subsection{Elektrische Resultate}

\begin{frame}{Unterschiedliche Kabellängen}
    \begin{figure}
        \includesvg[width=0.8\textwidth]{../documentation/graphics/different_cable_lengths_with_dso_tdc.svg}
    \end{figure}

    \iconelectrical
\end{frame}

\begin{frame}{Unterschiedliche Kabellängen: Resultate}
    \begin{table}
        \mytable
            {|l|l|l|l|}
            {\textbf{Länge} & \textbf{Mittelwert} & \textbf{Standardabweichung} & \textbf{$\Delta$ zu 0~m}}
            {\length & \mean & \stddev & \diff}
            {../documentation/tables/different_cable_lengths_with_dso_tdc.csv}
    \end{table}

    \iconelectrical
\end{frame}

\begin{frame}{Unterschiedliche Kabellängen: Zurückgerechnet}
    \begin{table}
        \mytable
            {|l|l|}
            {\textbf{Länge} & \textbf{TDC zurückgerechnet mit 0.9~c}}
            {\length & \tdcgemtheoriemc}
            {../documentation/tables/different_cable_lengths_with_dso_theorie09_vs_tdc_m.csv}
    \end{table}

    \iconelectrical
\end{frame}

\subsection{Optische Resultate}

\begin{frame}{Signalpfad Sender}
    \begin{figure}
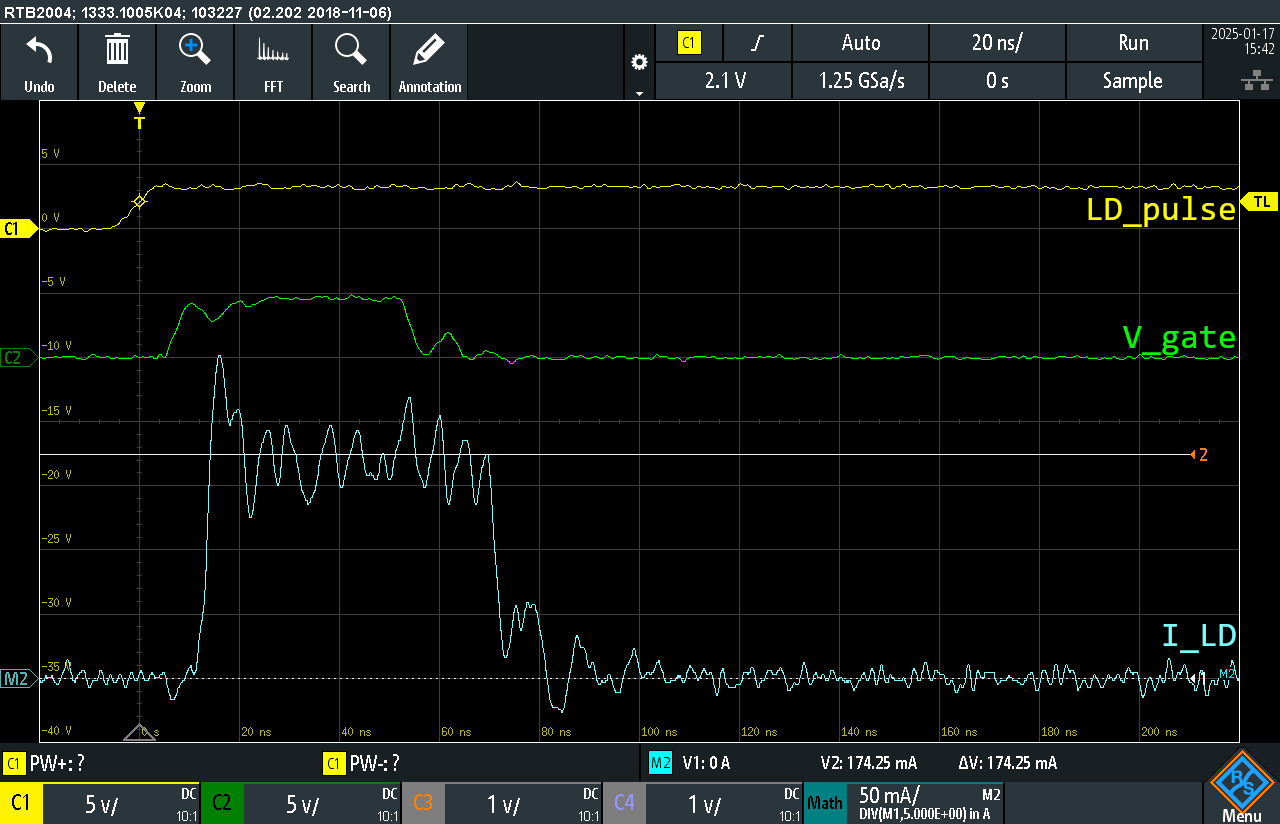
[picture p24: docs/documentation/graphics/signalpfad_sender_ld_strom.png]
        
    \end{figure}

    \iconoptical
\end{frame}

\begin{frame}{ToF-Messungen via Spiegel}
    \begin{figure}
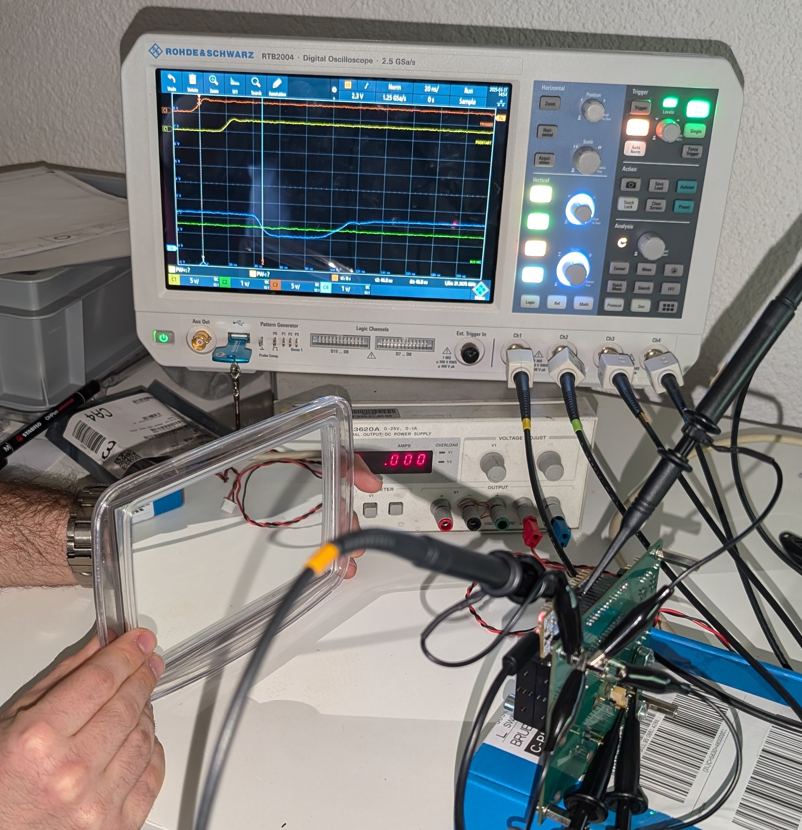
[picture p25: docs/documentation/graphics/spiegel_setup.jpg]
        
    \end{figure}

    \iconoptical
\end{frame}

\begin{frame}{ToF-Messungen via Spiegel: DSO}
    \begin{figure}
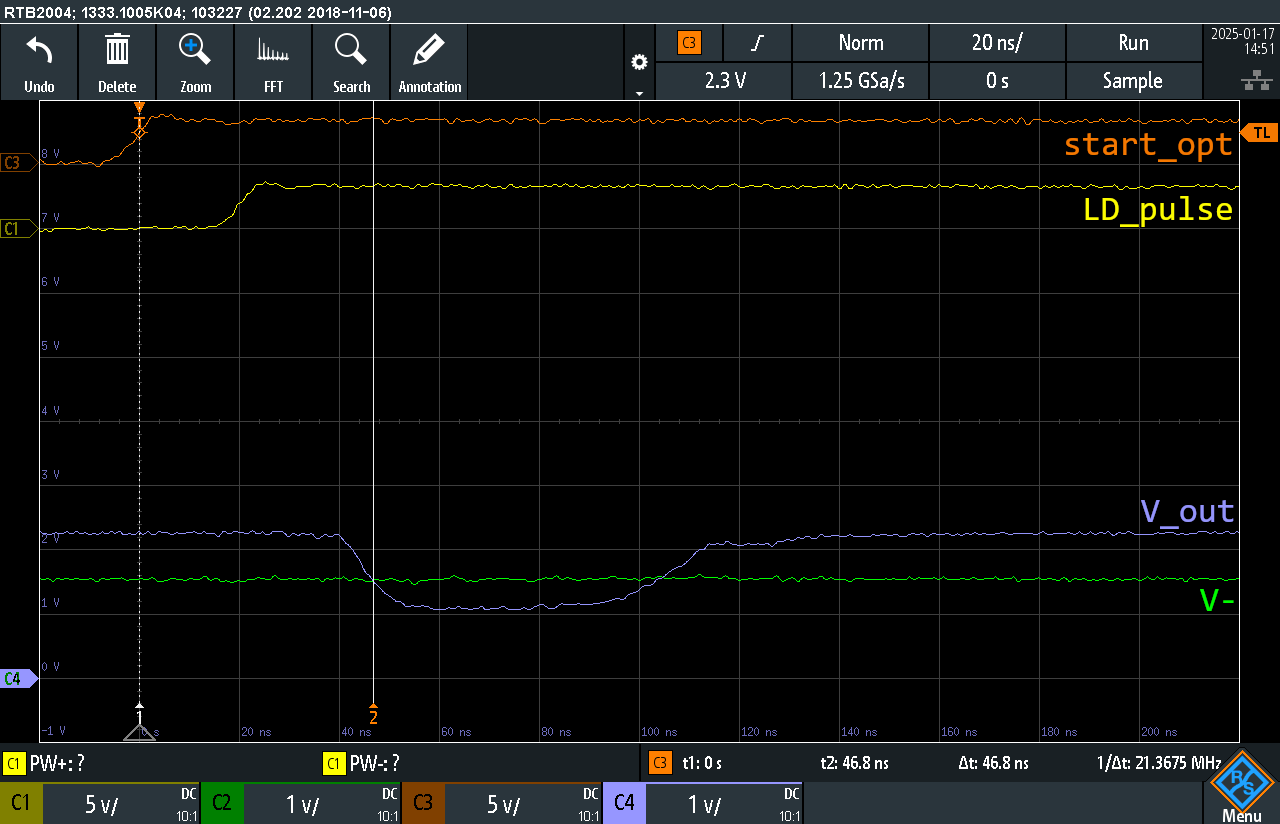
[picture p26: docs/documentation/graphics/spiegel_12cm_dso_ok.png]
        
    \end{figure}

    \iconoptical
\end{frame}

\begin{frame}{ToF-Messungen via Spiegel: Resultate}
    \begin{figure}
        \includesvg[width=0.8\textwidth]{../documentation/graphics/spiegel_unterschiedliche_distanzen.svg}
    \end{figure}

    \iconoptical
\end{frame}

\begin{frame}{ToF-Messungen via Spiegel: Auswertung}
    \begin{table}
        \mytable
            {|l|l|l|}
            {\textbf{Distanz zum Spiegel} & \textbf{Mittelwert} & \textbf{Standardabweichung}}
            {\distance & \mean & \stddev}
            {../documentation/tables/spiegel_unterschiedliche_distanzen.csv}
    \end{table}

    \onslide<2->{
        \begin{equation*}
            \begin{split}
                \Delta ToF_{meas} &\approx 0.6~ns\\
                \Delta ToF_{calc} &= \frac{\Delta L}{c} = \frac{10~cm}{3 \cdot 10^8~m/s} = 0.33~ns
            \end{split}
        \end{equation*}
    }

    \iconoptical
\end{frame}

\begin{frame}{ToF-Messungen via Spiegel: Drift}
    \begin{figure}
        \includesvg[width=0.8\textwidth]{../documentation/graphics/spiegel_unterschiedliche_distanzen_linear.svg}
    \end{figure}

    \iconoptical
\end{frame}

\begin{frame}{ToF-Messungen via Spiegel: $>$30 cm}
    \begin{figure}
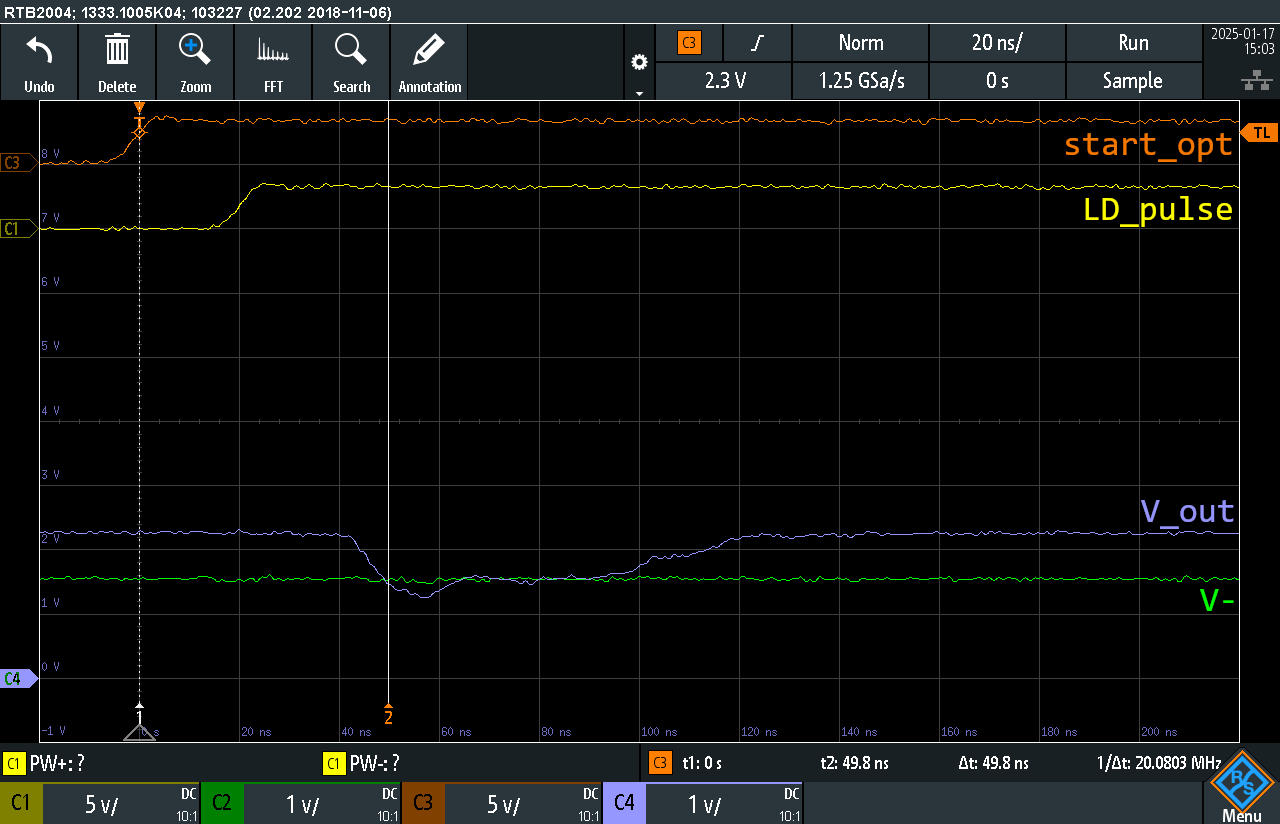
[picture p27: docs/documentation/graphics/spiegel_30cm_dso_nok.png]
        
    \end{figure}

    \iconoptical
\end{frame}

\begin{frame}{ToF-Messungen via Wand}
    \begin{itemize}
        \item Leider Optik noch nicht dafür ausgelegt
    \end{itemize}

    \iconoptical
\end{frame}

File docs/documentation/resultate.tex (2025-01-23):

In diesem Kapitel werden die Resultate dokumentiert.

Die verwendeten Python-Skripte zur Berechnung der statistischen Grössen und zum Plotten der Diagramme befinden sich im
Anhang~\ref{sec:python_scripts}.

\subsection{Elektrische Messungen}\label{sec:electrical_measurements}

In diesem Teilkapitel werden die Messresultate dokumentiert, welche rein elektrisch (also ohne optischen Teil) erfasst
wurde.

Das verwendete \acrfull{dso} ist ein Rohde \& Schwarz RTB2004 1.25 GSa/s.

Die Zeitmessungen werden von \lstinline|IC1| (siehe Abbildung~\ref{fig:tdc_ele_signal}) durchgeführt und von der
Firmware, welche auf dem Nucleo Board \lstinline|U1| (siehe Abbildung~\ref{fig:nucleo_board}) getriggert und ausgelesen.

\subsubsection{GPIO Toggle mit HAL}\label{sec:gpio_toggle_with_hal}

Als erstes wird gemessen, wie lange es für die \acrshort{cpu} der \acrshort{mcu} dauert mittels \acrfull{hal} - Library
\cite{st2020stm32f0_hal} zwei \acrshort{gpio}-Pins zu schalten.

In Code~\ref{code:gpio_toggle_with_hal} ist die Firmware-Implementation dazu gezeigt.

\lstinputlisting[language={C}, label={code:gpio_toggle_with_hal}, caption={\acrshort{gpio} Toggle mit \acrshort{hal}}]{sourcecode/gpio_toggle_with_hal.c}

Der \acrshort{tdc} misst also die Zeit zwischen Zeile 15 und 16 in Code~\ref{code:gpio_toggle_with_hal}. Dazu wird der
STOP-Pin des \acrshort{tdc} via \lstinline|SW1| mit \lstinline|stop_ele| verbunden. Der Kabelanschluss \lstinline|J3|
wird kurzgeschlossen. Siehe Abbildung~\ref{fig:tdc_ele_signal}.

Via \acrshort{uart} wurden 2000 Messwerte erfasst. Ein Ausschnitt davon ist in Code \ref{code:gpio_toggle_with_hal_log}
gezeigt. Die restlichen Daten befinden sich im elektronischen Anhang.

\lstinputlisting[language={}, label={code:gpio_toggle_with_hal_log}, caption={\acrshort{gpio} Toggle mit \acrshort{hal}}]{sourcecode/gpio_toggle_with_hal_log.txt}

Arithmetischer Mittelwert und Standardabweichung sind in Formel \ref{eq:gpio_toggle_with_hal} aufgeführt.

\begin{equation}\label{eq:gpio_toggle_with_hal}
    \begin{split}
        \overline{ToF} &= 6'375'888~ps\\
        \sigma         &= 1'059~ps
    \end{split}
\end{equation}
\myequations{\acrshort{gpio} Toggle mit \acrshort{hal}}

Da die \acrshort{cpu} mit 8~MHz läuft, lässt sich daraus schliessen, dass ein Pin-Toggle mit \acrshort{hal} ca. 50
\acrshort{cpu}-Cycles benötigt. Dies erscheint plausibel.

Histogramm und Boxplot sind in Abbildung~\ref{fig:gpio_toggle_with_hal_histogram} bzw.
\ref{fig:gpio_toggle_with_hal_boxplot} dargestellt.

\begin{figure}[H]
    \centering
    \includesvg[width=0.8\textwidth]{graphics/gpio_toggle_with_hal_histogram.svg}
    \caption{\acrshort{gpio} Toggle mit \acrshort{hal} - Histogramm}\label{fig:gpio_toggle_with_hal_histogram}
\end{figure}

\begin{figure}[H]
    \centering
    \includesvg[width=0.8\textwidth]{graphics/gpio_toggle_with_hal_boxplot.svg}
    \caption{\acrshort{gpio} Toggle mit \acrshort{hal} - Boxplot}\label{fig:gpio_toggle_with_hal_boxplot}
\end{figure}

Um die Resultate des \acrshort{tdc} zu validieren, wurde dieselbe Messung auch mittels \acrfull{dso} durchgeführt. Die
Messungen sind in Abbildung~\ref{fig:gpio_toggle_with_hal_dso} und \ref{fig:gpio_toggle_with_hal_dso_zoom} dargestellt.

\begin{figure}[H]
    \centering
    
    \caption{\acrshort{gpio} Toggle mit \acrshort{hal} - \acrshort{dso}}\label{fig:gpio_toggle_with_hal_dso}
\end{figure}

\begin{figure}[H]
    \centering
    
    \caption{\acrshort{gpio} Toggle mit \acrshort{hal} - \acrshort{dso} (Zoom)}\label{fig:gpio_toggle_with_hal_dso_zoom}
\end{figure}

\subsubsection{GPIO Toggle ohne HAL}\label{sec:gpio_toggle_without_hal}

Als nächstes wird gemessen wie lange es für die \acrshort{cpu} der \acrshort{mcu} dauert mit direktem Register-Zugriff
(via Pointer; ohne \acrshort{hal}-Library) zwei \acrshort{gpio}-Pins zu schalten.

In Code~\ref{code:gpio_toggle_without_hal} ist die Firmware-Implementation dazu gezeigt.

\lstinputlisting[language={C}, label={code:gpio_toggle_without_hal}, caption={\acrshort{gpio} Toggle ohne \acrshort{hal}}]{sourcecode/gpio_toggle_without_hal.c}

Der \acrshort{tdc} misst also die Zeit zwischen Zeile 15 und 16 in Code~\ref{code:gpio_toggle_without_hal}. Dazu wird,
wie in Kapitel \ref{sec:gpio_toggle_with_hal}, der STOP-Pin des \acrshort{tdc} via \lstinline|SW1| mit
\lstinline|stop_ele| verbunden. Der Kabelanschluss \lstinline|J3| wird kurzgeschlossen. Siehe
Abbildung~\ref{fig:tdc_ele_signal}.

Via \acrshort{uart} wurden 2000 Messwerte erfasst. Ein Ausschnitt davon ist in Code
\ref{code:gpio_toggle_without_hal_log} gezeigt. Die restlichen Daten befinden sich im elektronischen Anhang.

\lstinputlisting[language={}, label={code:gpio_toggle_without_hal_log}, caption={\acrshort{gpio} Toggle ohne \acrshort{hal}}]{sourcecode/gpio_toggle_without_hal_log.txt}

Arithmetischer Mittelwert und Standardabweichung sind in Formel \ref{eq:gpio_toggle_without_hal} aufgeführt.

\begin{equation}\label{eq:gpio_toggle_without_hal}
    \begin{split}
        \overline{ToF} &= 1'377'773~ps\\
        \sigma         &= 402~ps
    \end{split}
\end{equation}
\myequations{\acrshort{gpio} Toggle ohne \acrshort{hal}}

Da die \acrshort{cpu} mit 8~MHz läuft, lässt sich daraus schliessen, dass ein Pin-Toggle ohne \acrshort{hal} ca. 10
\acrshort{cpu}-Cycles benötigt. Dies erscheint plausibel.

Histogramm und Boxplot sind in Abbildung~\ref{fig:gpio_toggle_without_hal_histogram} bzw.
\ref{fig:gpio_toggle_without_hal_boxplot} dargestellt.

\begin{figure}[H]
    \centering
    \includesvg[width=0.8\textwidth]{graphics/gpio_toggle_without_hal_histogram.svg}
    \caption{\acrshort{gpio} Toggle ohne \acrshort{hal} - Histogramm}\label{fig:gpio_toggle_without_hal_histogram}
\end{figure}

\begin{figure}[H]
    \centering
    \includesvg[width=0.8\textwidth]{graphics/gpio_toggle_without_hal_boxplot.svg}
    \caption{\acrshort{gpio} Toggle ohne \acrshort{hal} - Boxplot}\label{fig:gpio_toggle_without_hal_boxplot}
\end{figure}

Um die Resultate des \acrshort{tdc} zu validieren, wurde dieselbe Messung auch mittels \acrfull{dso} durchgeführt. Die
Messungen sind in Abbildung~\ref{fig:gpio_toggle_without_hal_dso} und \ref{fig:gpio_toggle_without_hal_dso_zoom}
dargestellt.

\begin{figure}[H]
    \centering
    
    \caption{\acrshort{gpio} Toggle ohne \acrshort{hal} - \acrshort{dso}}\label{fig:gpio_toggle_without_hal_dso}
\end{figure}

\begin{figure}[H]
    \centering
    
    \caption{\acrshort{gpio} Toggle ohne \acrshort{hal} - \acrshort{dso} (Zoom)}\label{fig:gpio_toggle_without_hal_dso_zoom}
\end{figure}

\subsubsection{Unterschiedliche Kabellängen}\label{sec:different_cable_lengths}

Für diese Messung wird dasselbe Setup wie in Kapitel \ref{sec:gpio_toggle_without_hal} verwendet.

Anstelle eines Kurzschlusses von \lstinline|J3| (siehe Abbildung \ref{fig:tdc_ele_signal}) werden nun verschiedene
Kabellängen angeschlossen.

Als Kabel wird ein einzelner, isolierter Kupferdraht ($\diameter_{cu} = 0.8~mm$, $\diameter_{ges} = 1.6~mm$) verwendet.

Es hat sich herausgestellt, dass eine kreisförmige Anordnung des Kabels wichtig ist. Denn bei einer Überlappung der
beiden Kabelenden werden kürze Zeiten gemessen. Dies hat mit der kapazitiven Kopplung zwischen den Leitern zu tun.

Die Resultate sind in Abbildung~\ref{fig:different_cable_lengths} dargestellt. Die Liste mit den Datenpunkten befindet
sich im elektronischen Anhang.

\begin{figure}[H]
    \centering
    \includesvg[width=0.9\textwidth]{graphics/different_cable_lengths.svg}
    \caption{Unterschiedliche Kabellängen}\label{fig:different_cable_lengths}
\end{figure}

Die arithmetischen Mittelwerte und Standardabweichungen sind in Tabelle \ref{tab:different_cable_lengths} aufgeführt.

\begin{table}[H]
    \mytable
        {|l|l|l|}
        {\textbf{Länge} & \textbf{Mittelwert} & \textbf{Standardabweichung}}
        {\length & \mean & \stddev}
        {tables/different_cable_lengths.csv}
    \caption{Unterschiedliche Kabellängen}\label{tab:different_cable_lengths}
\end{table}

Die Signal-Ausbreitungs-Geschwindigkeit in Kupfer beträgt ca. $\sfrac{2}{3}$ der Lichtgeschwindigkeit
\cite{firewallcx2025propagationdelay}. Um die Resultate in Tabelle \ref{tab:different_cable_lengths} zu validieren,
rechnen wir, wie in Formel \ref{eq:cable_length} gezeigt, auf die Kabellänge zurück. Die Laufzeit bei 0~m wird dabei
abgezogen, um die Verzögerung zu kompensieren, welche durch das Schalten der \acrshort{gpio}s entsteht.

\begin{equation}\label{eq:cable_length}
    \begin{split}
        c_{cu} &\approx \frac{2}{3} \cdot c_0 = \frac{2}{3} \cdot 299'792'458~\frac{m}{s} \approx 200'000'000~\frac{m}{s}\\
        ToF_{n} &= ToF_{n_{abs}} - ToF_{0}\\
        l_{n}   &= ToF_{n} \cdot c_{cu}
    \end{split}
\end{equation}
\myequations{Zurückrechnen auf Kabellänge}

Die Resultate sind in Tabelle \ref{tab:different_cable_lengths_calc} dargestellt.

\begin{table}[H]
    \mytable
        {|l|l|l|}
        {\textbf{Tatsächliche Länge} & \textbf{ToF}$\mathbf{_n}$ & \textbf{Zurückgerechnete Länge}}
        {\reallength & \tofn & \calclength}
        {tables/different_cable_lengths_calc.csv}
    \caption{Kabellängen zurückgerechnet}\label{tab:different_cable_lengths_calc}
\end{table}

Es fällt auf, dass die Resultate nicht genau übereinstimmen. Es ist jedoch eine klare Korrelation zu erkennen.

Der Unterschied könnte verschiedene Ursachen haben. Eine mögliche Erklärung wäre, dass die Ausbreitungs-Geschwindigkeit
beim verwendeten Kabel näher an der Lichtgeschwindigkeit ist als angenommen. Weitere Messresultate und Auswertungen
dazu in Kapitel~\ref{sec:different_cable_lengths_with_dso}.

\subsubsection{Mode 1 vs. Mode 2}

Der TDC7200 unterstützt zwei Modi mit unterschiedlichen Messbereichen \cite{ti2016tdc7200_datasheet}:

\begin{itemize}
    \item Mode 1: 12~ns bis 500~ns
    \item Mode 2: 250~ns bis 8~ms
\end{itemize}

Im Mode~1 wird nur der interne Ring-Oszillator des \acrshort{tdc} verwendet. Siehe dazu Abbildung~\ref{fig:tdc_mode1}.

\begin{figure}[H]
    \centering
    
    \caption[\acrshort{tdc} Mode 1]{\acrshort{tdc} Mode 1 \cite{ti2016tdc7200_datasheet}}\label{fig:tdc_mode1}
\end{figure}

Im Mode~2, um längere Zeiten messen zu können, wir zusätzlich der externe Clock des \acrshort{tdc} verwendet. Siehe dazu
Abbildung~\ref{fig:tdc_mode2}.

\begin{figure}[H]
    \centering
    
    \caption[\acrshort{tdc} Mode 2]{\acrshort{tdc} Mode 2 \cite{ti2016tdc7200_datasheet}}\label{fig:tdc_mode2}
\end{figure}

Die bisherigen Messungen (Kapitel~\ref{sec:gpio_toggle_with_hal}, \ref{sec:gpio_toggle_without_hal} und
\ref{sec:different_cable_lengths}) wurden im Mode~2 durchgeführt, da das Schalten der \acrshort{gpio}s mit der
\acrshort{cpu} mehr als 500~ns brauchte.

In künftigen Messungen soll das Schalten der \acrshort{gpio}s von einem Hardware-Timer der \acrshort{mcu} erledigt
werden. Damit werden Schaltzeiten von 125~ns bei 8~MHz bzw. 20.8~ns bei 48~MHz möglich sein. Es soll deshalb in diesem
Kapitel ein Vergleich der Messresultate der beiden Modi gemacht werden.

Dazu wurden drei Messungen gemacht:
\begin{enumerate}
    \item \acrshort{gpio} Toggle ohne \acrshort{hal} im Mode~2 mit Kabellänge~=~0~m (wie in Kapitel~\ref{sec:gpio_toggle_without_hal} und \ref{sec:different_cable_lengths})
    \item \acrshort{gpio} Toggle ohne \acrshort{hal} im Mode~2 mit Kabellänge~=~6~m (wie in Kapitel~\ref{sec:different_cable_lengths})
    \item Ohne GPIO Toggle Im Mode~1 mit Kabellänge~=~6~m
\end{enumerate}

Für die Messung im Mode~1 soll auf die Verzögerung durch das Schalten der \acrshort{gpio}s verzichtet werden. Dazu wird
das \lstinline|START|- und \lstinline|STOP|-Signal vom selben \acrshort{gpio}-Pin, \lstinline|start_ele|, generiert.
Dazu wird \lstinline|SW1| mit \lstinline|start_ele| verbunden (siehe Abbildung~\ref{fig:tdc_ele_signal}).

In Code~\ref{code:mode1} ist die Firmware-Implementation für eine Messung im Mode~1 gezeigt.

\lstinputlisting[language={C}, label={code:mode1}, caption={Mode 1}]{sourcecode/mode1.c}

Die Unterschiede im Vergleich zu den Messungen in Kapitel~\ref{sec:gpio_toggle_without_hal} und
\ref{sec:different_cable_lengths} sind:

\begin{itemize}
    \item Zeile 7: \acrshort{tdc} wird im Mode~1 konfiguriert (anstatt Mode~2)
    \item Zeile 15 und 23: Es wird nur der \lstinline|start_ele| Pin getoggelt (anstatt \lstinline|start_ele| und \lstinline|stop_ele| Pin)
\end{itemize}

Die Erwartung ist, dass die Differenz aus Messung~1 und Messungen~2 ungefähr dem Resultat aus Messung~3 entspricht.

Die Resultate dieser drei Messungen sind in Tabelle \ref{tab:mode1_vs_mode2} aufgeführt. Die restlichen Daten befinden
sich im elektronischen Anhang.

\begin{table}[H]
    \mytable
        {|l|l|l|}
        {\textbf{Messung} & \textbf{Mittelwert} & \textbf{Standardabweichung}}
        {\measurement & \mean & \stddev}
        {tables/mode1_vs_mode2.csv}
    \caption{Mode 1 vs. Mode 2}\label{tab:mode1_vs_mode2}
\end{table}

Die Berechnung in Formel~\ref{eq:mode1_vs_mode2} zeigt, dass die Messresultate nahe beieinander liegen.

\begin{equation}\label{eq:mode1_vs_mode2}
    \begin{split}
        \Delta Mode~2 &= 1'403'224~ps - 1'378'222~ps = 25'001~ps\\
        Mode~1        &= 25'145~ps
    \end{split}
\end{equation}
\myequations{Mode 1 vs. Mode 2}

Es kann also davon ausgegangen werden, dass Mode~1 und Mode~2 im Firmware-Treiber korrekt implementiert wurden.

Bemerkung: Im Firmware-Treiber (siehe Anhang~\ref{sec:tdc_driver}) kann für beide Modi dieselbe Funktion
\lstinline|TDC_read_result()| verwendet werden. Für Mode~1 vereinfacht sich die Berechnung, weil \lstinline|TIME2|~=~0
und \lstinline|CLOCK_COUNT1|~=~0.

\subsubsection{Timer Output}\label{sec:timer_output}

In Kapitel~\ref{sec:gpio_toggle_with_hal} und \ref{sec:gpio_toggle_without_hal} wurde gezeigt, dass es einige
\acrshort{cpu}-Cycles dauert, um  mittels Software, also mit \acrshort{cpu}-Instruktionen, \acrshort{gpio}s zu toggeln.

Eine schnellere Methode ist es, das Toggeln der \acrshort{gpio}s von der Hardware-Peripherie der \acrshort{mcu}
erledigen zu lassen. Dazu eignen sich Hardware-Timer.

In Abbildung \ref{fig:clock_config_default} ist die default Clock-Configuration des Nucleo-Boards gezeigt.

\begin{figure}[H]
    \centering
    
    \caption{Default Clock-Configuration}\label{fig:clock_config_default}
\end{figure}

Per default wird der \acrfull{hsi} Clock mit 8~MHz verwendet. Damit sollte es mit Hardware-Timer möglich sein, zwei
\acrshort{gpio}s zu schalten mit einer Verzögerung gemäss Formel~\ref{eq:gpio_schalten_zeit}.

\begin{equation}\label{eq:gpio_schalten_zeit}
    t = \frac{1}{8~MHz} = 125~ns
\end{equation}
\myequations{\acrshort{gpio}-Schalten Verzögerungszeit}

Dazu werden Kanal \lstinline|CH1| und \lstinline|CH4| des Hardware-Timers \lstinline|TIM1| im Output Compare Match Modus
verwendet. Die zugeordneten \acrshort{gpio}-Pins sind \lstinline|start_ele| bzw. \lstinline|stop_ele|.

Erreicht der 16~bit Timer den Wert \lstinline|32'000| wird \lstinline|start_ele| auf High geschalten. Beim Erreichen des
Werts \lstinline|32'001| wird \lstinline|stop_ele| auf High geschalten.

Der \acrshort{tdc} wird in Mode 1 konfiguriert. Der STOP-Pin des \acrshort{tdc} wird via \lstinline|SW1| mit
\lstinline|stop_ele| verbunden. Der Kabelanschluss \lstinline|J3| wird kurzgeschlossen. Siehe
Abbildung~\ref{fig:tdc_ele_signal}.

In Code~\ref{code:timer_output} ist die Firmware-Implementation dazu gezeigt.

\lstinputlisting[language={C}, label={code:timer_output}, caption={\acrshort{gpio} Toggle mit Timer-Output}]{sourcecode/timer_output.c}

Der gemessene arithmetische Mittelwert und die Standardabweichung sind in Formel~\ref{eq:timer_output} aufgeführt.  Die
Liste mit den Datenpunkten befindet sich im elektronischen Anhang.

\begin{equation}\label{eq:timer_output}
    \begin{split}
        \overline{ToF} &=128'108~ps\\
        \sigma         &= 81~ps
    \end{split}
\end{equation}
\myequations{\acrshort{gpio} Toggle mit Timer-Output}

Erwartungsgemäss dauert das Schalten der \acrshort{gpio}s ca. 125~ns. Die Standardabweichung ist aufgrund der kleineren
Anzahl an Clock-Cycles tiefer als in den bisherigen Kapiteln.

\subsubsection{Unterschiedliche Clock-Konfigurationen}

In diesem Teilkapitel werden Messungen mit demselben Setup wie in Kapitel~\ref{sec:timer_output} durchgeführt.

Es werden die arithmetischen Mittelwerte und die Standardabweichungen verschiedener Clock-Quellen des Nucleo-Boards
verglichen. Es werden drei Messungen gemacht:

\begin{enumerate}
    \item \acrshort{hsi}: 8~MHz (wie in Kapitel~\ref{sec:timer_output})
    \item \acrshort{hsi} mit \acrshort{pll}: 16~MHz
    \item \acrshort{hsi}48: 48~MHz
\end{enumerate}

Die Clock-Konfigurationen für Messung 2 und 3 sind in Abbildung~\ref{fig:clock_config_hsi_pll_16mhz} bzw.
\ref{fig:clock_config_hsi48_48mhz} dargestellt.

\begin{figure}[H]
    \centering
    
    \caption{Clock-Configuration \acrshort{hsi} mit \acrshort{pll} 16~MHz}\label{fig:clock_config_hsi_pll_16mhz}
\end{figure}

\begin{figure}[H]
    \centering
    
    \caption{Clock-Configuration \acrshort{hsi}48 48~MHz}\label{fig:clock_config_hsi48_48mhz}
\end{figure}

Die arithmetischen Mittelwerte und Standardabweichungen sind in Tabelle~\ref{tab:different_clock_sources} dargestellt.
Die Liste mit den Datenpunkten befindet sich im elektronischen Anhang.

\begin{table}[H]
    \mytable
        {|l|l|l|}
        {\textbf{Messung} & \textbf{Mittelwert} & \textbf{Standardabweichung}}
        {\measurement & \mean & \stddev}
        {tables/different_clock_sources.csv}
    \caption{Unterschiedliche Clock-Quellen}\label{tab:different_clock_sources}
\end{table}

Die Resultate stimmen ungefähr mit den erwarteten Werten aus Formel~\ref{eq:gpio_schalten_zeiten} überein.

\begin{equation}\label{eq:gpio_schalten_zeiten}
    \begin{split}
        t_1 &= \frac{1}{8~MHz} = 125~ns\\
        t_2 &= \frac{1}{16~MHz} = 62.5~ns\\
        t_3 &= \frac{1}{48~MHz} = 20.8~ns
    \end{split}
\end{equation}
\myequations{\acrshort{gpio}-Schalten Verzögerungszeiten}

Im Datenblatt konnte eine Angabe zum \acrshort{pll}-Jitter gefunden werden, siehe Abbildung~\ref{fig:pll_jitter}.

\begin{figure}[H]
    \centering
    
    \caption[\acrshort{pll}-Jitter]{\acrshort{pll}-Jitter \cite{st2017stm32f042k6_datasheet}}\label{fig:pll_jitter}
\end{figure}

Diese Angabe ist ungefähr in derselben Grössenordnung wie die Messresultate.

\subsubsection{Unterschiedliche Kabellängen mit DSO}\label{sec:different_cable_lengths_with_dso}

In diesem Unterkapitel werden nochmals dieselben Kabellängen wie in Kapitel~\ref{sec:different_cable_lengths}
ausgemessen.

Es wird die folgende Firmware-Konfiguration verwendet, um den Jitter zu reduzieren:

\begin{itemize}
    \item \acrshort{tdc}: Modus 1
    \item Clock: 48~MHz
    \item Schalten der \acrshort{gpio}s: Timer Output
\end{itemize}

Zusätzlich werden die verschiedenen Kabellängen gleichzeitig auch via \acrshort{dso} (Rohde \& Schwarz RTB2004 2.5 GSa/s.)
ausgemessen, um die Resultate des \acrshort{tdc} damit zu vergleichen.

In Abbildung~\ref{fig:different_cable_lengths_with_dso_tdc} sind die erfassten Messresultate des \acrshort{tdc}
dargestellt. Während dem Erfassen der Messwerte war das \acrshort{dso} an den Pins angeschlossen. Die Liste mit den
Datenpunkten befindet sich im elektronischen Anhang.

\begin{figure}[H]
    \centering
    \includesvg[width=0.9\textwidth]{graphics/different_cable_lengths_with_dso_tdc.svg}
    \caption{Unterschiedliche Kabellängen - Messwerte \acrshort{tdc}}\label{fig:different_cable_lengths_with_dso_tdc}
\end{figure}

In Tabelle~\ref{tab:different_cable_lengths_with_dso_tdc} sind die Mittelwerte und die Standardabweichungen der
erfassten Messresultate des \acrshort{tdc} aufgelistet.

\begin{table}[H]
    \mytable
        {|l|l|l|l|}
        {\textbf{Länge} & \textbf{Mittelwert} & \textbf{Standardabweichung} & \textbf{$\Delta$ zu 0~m}}
        {\length & \mean & \stddev & \diff}
        {tables/different_cable_lengths_with_dso_tdc.csv}
    \caption{Unterschiedliche Kabellängen - Resultate \acrshort{tdc}}\label{tab:different_cable_lengths_with_dso_tdc}
\end{table}

In Tabelle~\ref{tab:different_cable_lengths_with_dso_dso} sind die erfassten Messresultate des \acrshort{dso}
aufgelistet. Die letzte Spalte zeigt den Unterschied zwischen \acrshort{dso} und \acrshort{tdc}. Es ist zu erkennen,
dass der Unterschied sehr klein ist.

\begin{table}[H]
    \mytable
        {|l|l|l|l|}
        {\textbf{Länge} & \textbf{Wert} & \textbf{$\Delta$ zu 0~m} & \textbf{$\Delta$ zu TDC}}
        {\length & \measurement & \diff & \difftdc}
        {tables/different_cable_lengths_with_dso_dso.csv}
    \caption{Unterschiedliche Kabellängen - Resultate \acrshort{dso}}\label{tab:different_cable_lengths_with_dso_dso}
\end{table}

Tabelle~\ref{tab:different_cable_lengths_with_dso_theorie} zeigt die theoretisch zu erwartenden Laufzeiten bei den
unterschiedlichen Annahmen für die Signalausbreitungs-Geschwindigkeiten von $\sfrac{2}{3}~c$ und $c$.

\begin{table}[H]
    \mytable
        {|l|l|l|}
        {\textbf{Länge} & \textbf{Theorie} $\mathbf{\sfrac{2}{3}~c}$ & \textbf{Theorie c}}
        {\length & \theoriekc & \theoriec}
        {tables/different_cable_lengths_with_dso_theorie.csv}
    \caption{Unterschiedliche Kabellängen - Theoretische Erwartung}\label{tab:different_cable_lengths_with_dso_theorie}
\end{table}

Die Unterschiede der \acrshort{tdc}-Resultate zu den theoretischen Erwartungen sind in den
Tabellen~\ref{tab:different_cable_lengths_with_dso_theorie_vs_tdc_ns} und
\ref{tab:different_cable_lengths_with_dso_theorie_vs_tdc_m} dargestellt. Zuerst im Bezug auf den Laufzeit-Unterschied,
dann die zurückgerechnete Kabellänge.

\begin{table}[H]
    \mytable
        {|l|l|l|}
        {\textbf{Länge} & \textbf{$\Delta$ TDC zu Theorie} $\mathbf{\sfrac{2}{3}~c}$ & \textbf{$\Delta$ TDC Theorie zu c}}
        {\length & \tdczutheoriekc & \tdczutheoriec}
        {tables/different_cable_lengths_with_dso_theorie_vs_tdc_ns.csv}
    \caption{Unterschiedliche Kabellängen - Unterschied \acrshort{tdc} [ns] zu Theorie}\label{tab:different_cable_lengths_with_dso_theorie_vs_tdc_ns}
\end{table}

\begin{table}[H]
    \mytable
        {|l|l|l|}
        {\textbf{Länge} & \textbf{TDC gem. Theorie} $\mathbf{\sfrac{2}{3}~c}$ & \textbf{TDC gem. Theorie c}}
        {\length & \tdcgemtheoriekc & \tdcgemtheoriec}
        {tables/different_cable_lengths_with_dso_theorie_vs_tdc_m.csv}
    \caption{Unterschiedliche Kabellängen - \acrshort{tdc} [m] gem. Theorie}\label{tab:different_cable_lengths_with_dso_theorie_vs_tdc_m}
\end{table}

In Tabelle~\ref{tab:different_cable_lengths_with_dso_theorie_vs_tdc_m} ist zu erkennen, dass keine der beiden
theoretischen Werte für $c$ zu einem perfekten \acrshort{tdc}-Resultat für die zurückgerechnete Distanz [m] führt.

In Tabelle~\ref{tab:different_cable_lengths_with_dso_theorie_vs_tdc_ns} ist zu erkennen, dass die Differenz der
\acrshort{tdc}-Resultate zur theoretisch zu erwartenden Laufzeit bei $c$ etwas kleiner ist als bei $\sfrac{2}{3}~c$. Es
scheint, dass $c$ eine etwas bessere Näherung darstellt.
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

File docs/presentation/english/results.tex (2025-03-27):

\subsection{Electrical Results}

\begin{frame}{Different cable lengths}
    \begin{figure}
        \includesvg[width=0.8\textwidth]{../../documentation/graphics/different_cable_lengths_with_dso_tdc.svg}
    \end{figure}
    \iconelectrical
\end{frame}

\begin{frame}{Different cable lengths: Results}
    \begin{table}
        \mytable
        {|l|l|l|l|}
        {\textbf{Length} & \textbf{Mean} & \textbf{Standard deviation} & \textbf{$\Delta$ at 0~m}}
        {\length & \mean & \stddev & \diff}
        {../../documentation/tables/different_cable_lengths_with_dso_tdc.csv}
    \end{table}
    \iconelectrical
\end{frame}

\begin{frame}{Different cable lengths: Calculated backwards}
    \begin{table}
        \mytable
        {|l|l|}
        {\textbf{Length} & \textbf{TDC recalculated with 0.9~c}}
        {\length & \tdcgemtheoriemc}
        {../../documentation/tables/different_cable_lengths_with_dso_theorie09_vs_tdc_m.csv}
    \end{table}
    \iconelectrical
\end{frame}

\subsection{Optical Results}

\begin{frame}{Signal Path Transmitter}
    \begin{figure}
        
    \end{figure}
    \iconoptical
\end{frame}

\begin{frame}{ToF measurements via mirror}
    \begin{figure}
        
    \end{figure}
    \iconoptical
\end{frame}

\begin{frame}{ToF measurements via mirror: DSO}
    \begin{figure}
        
    \end{figure}
    \iconoptical
\end{frame}

\begin{frame}{ToF measurements via mirror: Results}
    \begin{figure}
        \includesvg[width=0.8\textwidth]{../../documentation/graphics/spiegel_unterschiedliche_distanzen.svg}
    \end{figure}
    \iconoptical
\end{frame}

\begin{frame}{ToF measurements via mirror: analysis}
    \begin{table}
        \mytable
        {|l|l|l|}
        {\textbf{Distance to mirror} & \textbf{Mean value} & \textbf{Standard deviation}}
        {\distance & \mean & \stddev}
        {../../documentation/tables/spiegel_unterschiedliche_distanzen.csv}
    \end{table}

    \onslide<2->{
        \begin{equation*}
            \begin{split}
                \Delta ToF_{meas} & \approx 0.6~ns                                                  \\
                \Delta ToF_{calc} & = \frac{\Delta L}{c} = \frac{10~cm}{3 \cdot 10^8~m/s} = 0.33~ns
            \end{split}
        \end{equation*}
    }
    \iconoptical
\end{frame}

\begin{frame}{ToF measurements via mirror: drift}
    \begin{figure}
        \includesvg[width=0.8\textwidth]{../../documentation/graphics/spiegel_unterschiedliche_distanzen_linear.svg}
    \end{figure}
    \iconoptical
\end{frame}

\begin{frame}{ToF measurements via mirror: $>$30 cm}
    \begin{figure}
        
    \end{figure}
    \iconoptical
\end{frame}

\begin{frame}{ToF measurements via wall}
    \begin{itemize}
        \item Unfortunately, optics not yet designed for this
    \end{itemize}
    \iconoptical
\end{frame}

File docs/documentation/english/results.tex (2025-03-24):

The results are documented in this chapter.

The Python scripts used to calculate the statistical values and to plot the diagrams can be found in the
Appendix~\ref{sec:python_scripts}.

\subsection{Electrical Measurements}\label{sec:electrical_measurements}

This subchapter documents the measurement results that were recorded purely electrically (i.e. without the optical part.

The \acrfull{dso} used is a Rohde \& Schw arz RTB2004 1.25 GSa/s.

The time measurements are carried out by \lstinline|IC1| (see figure~\ref{fig:tdc_ele_signal}) and triggered and read by the
firmware, which is triggered and read on the Nucleo board \lstinline|U1| (see figure~\ref{fig:nucleo_board}).

\subsubsection{GPIO Toggle with HAL}\label{sec:gpio_toggle_with_hal}

First, the time it takes for the \acrshort{cpu} of the \acrshort{mcu} to switch two \acrshort{gpio} pins using the \acrfull{hal} library
\cite{st2020stm32f0_hal} is measured.

The firmware implementation for this is shown in Code~\ref{code:gpio_toggle_with_hal}.

\lstinputlisting[language={C}, label={code:gpio_toggle_with_hal}, caption={\acrshort{gpio} Toggle with \acrshort{hal}}]{../sourcecode/gpio_toggle_with_hal.c}

The \acrshort{tdc} measures the time between lines 15 and 16 in Code~\ref{code:gpio_toggle_with_hal}. To do this, the
STOP pin of the \acrshort{tdc} is connected to \lstinline|stop_ele| via \lstinline|SW1|. The cable connection \lstinline|J3|
is shorted. See figure~\ref{fig:tdc_ele_signal}.

Via \acrshort{uart}, 2000 measurement values were recorded. A section of this is shown in Code \ref{code:gpio_toggle_with_hal_log}.
The remaining data can be found in the electronic appendix.

\lstinputlisting[language={}, label={code:gpio_toggle_with_hal_log}, caption={\acrshort{gpio} Toggle with \acrshort{hal}}]{../sourcecode/gpio_toggle_with_hal_log.txt}

The arithmetic mean and standard deviation are listed in formula \ref{eq:gpio_toggle_with_hal}.

\begin{equation}\label{eq:gpio_toggle_with_hal}
      \begin{split}
            \overline{ToF} & = 6'375'888~ps \\
            \sigma         & = 1'059~ps
      \end{split}
\end{equation}
\myequations{\acrshort{gpio} Toggle with \acrshort{hal}}

Since the \acrshort{cpu} is running at 8~MHz, it can be concluded that a pin toggle with \acrshort{hal} takes about 50
\acrshort{cpu} cycles. This seems plausible.

The histogram and boxplot are shown in Figure~\ref{fig:gpio_toggle_with_hal_histogram} and
\ref{fig:gpio_toggle_with_hal_boxplot} shown.

\begin{figure}[H]
      \centering
      \includesvg[width=0.8\textwidth]{../graphics/gpio_toggle_with_hal_histogram.svg}
      \caption{\acrshort{gpio} Toggle with \acrshort{hal} - Histogram}\label{fig:gpio_toggle_with_hal_histogram}
\end{figure}

\begin{figure}[H]
      \centering
      \includesvg[width=0.8\textwidth]{../graphics/gpio_toggle_with_hal_boxplot.svg}
      \caption{\acrshort{gpio} Toggle with \acrshort{hal} - Boxplot}\label{fig:gpio_toggle_with_hal_boxplot}
\end{figure}

To validate the results of the \acrshort{tdc}, the same measurement was also carried out using \acrfull{dso}. The
measurements are shown in Figure~\ref{fig:gpio_toggle_with_hal_dso} and \ref{fig:gpio_toggle_with_hal_dso_zoom}.

\begin{figure}[H]
      \centering
      
      \caption{\acrshort{gpio} Toggle with \acrshort{hal} - \acrshort{dso}}\label{fig:gpio_toggle_with_hal_dso}
\end{figure}

\begin{figure}[H]
      \centering
      
      \caption{\acrshort{gpio} Toggle with \acrshort{hal} - \acrshort{dso} (Zoom)}\label{fig:gpio_toggle_with_hal_dso_zoom}
\end{figure}

\subsubsection{GPIO Toggle without HAL}\label{sec:gpio_toggle_without_hal}

Next, we measure how long it takes for the \acrshort{cpu} of the \acrshort{mcu} to switch two \acrshort{gpio} pins using direct register access
(via pointer; without \acrshort{hal} library).

The firmware implementation for this is shown in Code~\ref{code:gpio_toggle_without_hal}.

\lstinputlisting[language={C}, label={code:gpio_toggle_without_hal}, caption={\acrshort{gpio} Toggle without \acrshort{hal}}]{../sourcecode/gpio_toggle_without_hal.c}

The \acrshort{tdc} thus measures the time between lines 15 and 16 in Code~\ref{code:gpio_toggle_without_hal}. To do this,
as in chapter \ref{sec:gpio_toggle_with_hal}, the STOP pin of the \acrshort{tdc} is connected to \lstinline|SW1| via \lstinline|SW1|
\lstinline|stop_ele|. The cable connection \lstinline|J3| is shorted. See
Figure~\ref{fig:tdc_ele_signal}.

Via \acrshort{uart}, 2000 measurement values were recorded. A section of this is shown in Code
\ref{code:gpio_toggle_without_hal_log} shown. The remaining data can be found in the electronic appendix.

\lstinputlisting[language={}, label={code:gpio_toggle_without_hal_log}, caption={\acrshort{gpio} Toggle ohne \acrshort{hal}}]{../sourcecode/gpio_toggle_without_hal_log.txt}

The arithmetic mean and standard deviation are listed in formula \ref{eq:gpio_toggle_without_hal}.

\begin{equation}\label{eq:gpio_toggle_without_hal}
      \begin{split}
            \overline{ToF} & = 1'377'773~ps \\
            \sigma         & = 402~ps
      \end{split}
\end{equation}
\myequations{\acrshort{gpio} Toggle without \acrshort{hal}}

Since the \acrshort{cpu} is running at 8~MHz, it can be concluded that a pin toggle without \acrshort{hal} takes about 10
\acrshort{cpu} cycles. This seems plausible.

The histogram and boxplot are shown in figures~\ref{fig:gpio_toggle_without_hal_histogram} and
\ref{fig:gpio_toggle_without_hal_boxplot}, respectively.

\begin{figure}[H]
      \centering
      \includesvg[width=0.8\textwidth]{../graphics/gpio_toggle_without_hal_histogram.svg}
      \caption{\acrshort{gpio} Toggle without \acrshort{hal} - Histogram}\label{fig:gpio_toggle_without_hal_histogram}
\end{figure}

\begin{figure}[H]
      \centering
      \includesvg[width=0.8\textwidth]{../graphics/gpio_toggle_without_hal_boxplot.svg}
      \caption{\acrshort{gpio} Toggle without \acrshort{hal} - Boxplot}\label{fig:gpio_toggle_without_hal_boxplot}
\end{figure}

To validate the results of the \acrshort{tdc}, the same measurement was also carried out using \acrfull{dso}. The
measurements are shown in Figure~\ref{fig:gpio_toggle_without_hal_dso} and \ref{fig:gpio_toggle_without_hal_dso_zoom}.

\begin{figure}[H]
      \centering
      
      \caption{\acrshort{gpio} Toggle without \acrshort{hal} - \acrshort{dso}}\label{fig:gpio_toggle_without_hal_dso}
\end{figure}

\begin{figure}[H]
      \centering
      
      \caption{\acrshort{gpio} Toggle without \acrshort{hal} - \acrshort{dso} (Zoom)}\label{fig:gpio_toggle_without_hal_dso_zoom}
\end{figure}

\subsubsection{Different cable lengths}\label{sec:different_cable_lengths}

For this measurement, the same setup as in chapter \ref{sec:gpio_toggle_without_hal} is used.

Instead of short-circuiting \lstinline|J3| (see figure \ref{fig:tdc_ele_signal}), different cable lengths are now
connected.

A single insulated copper wire ($\diameter_{cu} = 0.8~mm$, $\diameter_{ges} = 1.6~mm$) is used as the cable.

It has been found that a circular arrangement of the cable is important. This is because when the
the two cable ends overlap, short times are measured. This has to do with the capacitive coupling between the conductors.

The results are shown in Figure~\ref{fig:different_cable_lengths}. The list with the data points
can be found in the electronic appendix.

\begin{figure}[H]
      \centering
      \includesvg[width=0.9\textwidth]{../graphics/different_cable_lengths.svg}
      \caption{Different cable lengths}\label{fig:different_cable_lengths}
\end{figure}

The arithmetic mean values and standard deviations are listed in Table \ref{tab:different_cable_lengths}.

\begin{table}[H]
      \mytable
      {|l|l|l|}
      {\textbf{Length} & \textbf{Mean value} & \textbf{Standard deviation}}
      {\length & \mean & \stddev}
      {../tables/different_cable_lengths.csv}
      \caption{Different cable lengths}\label{tab:different_cable_lengths}
\end{table}

The signal propagation speed in copper is approximately $\sfrac{2}{3}$ of the speed of light
\cite{firewallcx2025propagationdelay}. To validate the results in Table \ref{tab:different_cable_lengths},
we calculate back to the cable length, as shown in formula \ref{eq:cable_length}. The runtime at 0~m is
subtracted to compensate for the delay caused by switching the \acrshort{gpio}s.

\begin{equation}\label{eq:cable_length}
      \begin{split}
            c_{cu}  & \approx \frac{2}{3} \cdot c_0 = \frac{2}{3} \cdot 299'792'458~\frac{m}{s} \approx 200'000'000~\frac{m}{s} \\
            ToF_{n} & = ToF_{n_{abs}} - ToF_{0}                                                                                 \\
            l_{n}   & = ToF_{n} \cdot c_{cu}
      \end{split}
\end{equation}
\myequations{Back-calculate to cable length}

The results are shown in Table \ref{tab:different_cable_lengths_calc}.

\begin{table}[H]
      \mytable
      {|l|l|l|}
      {\textbf{Actual length} & \textbf{ToF}$\mathbf{_n}$ & \textbf{Calculated length}}
      {\reallength & \tofn & \calclength}
      {../tables/different_cable_lengths_calc.csv}
      \caption{Calculated cable lengths}\label{tab:different_cable_lengths_calc}
\end{table}

It is noticeable that the results do not match exactly. However, a clear correlation can be seen.

The difference could have various causes. One possible explanation would be that the propagation speed
of the cable used is closer to the speed of light than assumed. Further measurement results and evaluations
in chapter~\ref{sec:different_cable_lengths_with_dso}.

\subsubsection{Mode 1 vs. Mode 2}

The TDC7200 supports two modes with different measurement ranges \cite{ti2016tdc7200_datasheet}:

\begin{itemize}
      \item Mode 1: 12~ns to 500~ns
      \item Mode 2: 250~ns to 8~ms
\end{itemize}

In mode 1, only the internal ring oscillator of the \acrshort{tdc} is used. See figure~\ref{fig:tdc_mode1}.

\begin{figure}[H]
      \centering
      
      \caption[\acrshort{tdc} Mode 1]{\acrshort{tdc} Mode 1 \cite{ti2016tdc7200_datasheet}}\label{fig:tdc_mode1}
\end{figure}

In mode 2, to be able to measure longer times, the external clock of the \acrshort{tdc} is also used. See
Figure~\ref{fig:tdc_mode2}.

\begin{figure}[H]
      \centering
      
      \caption[\acrshort{tdc} Mode 2]{\acrshort{tdc} Mode 2 \cite{ti2016tdc7200_datasheet}}\label{fig:tdc_mode2}
\end{figure}

The previous measurements (chapter~\ref{sec:gpio_toggle_with_hal}, \ref{sec:gpio_toggle_without_hal} and
\ref{sec:different_cable_lengths}) were performed in mode~2 because switching the \acrshort{gpio}s with the
\acrshort{cpu} took more than 500~ns.
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

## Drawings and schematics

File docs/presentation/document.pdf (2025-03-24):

# DIY Optische ToF Distanzmessung

# OST – Ostschweizer Fachhochschule

## CAS Sensorik und Sensor Signal Conditioning

## Matthias Sch¨ar, Timon Burkard

24.01.2025

# 1 Ziele (2 min)

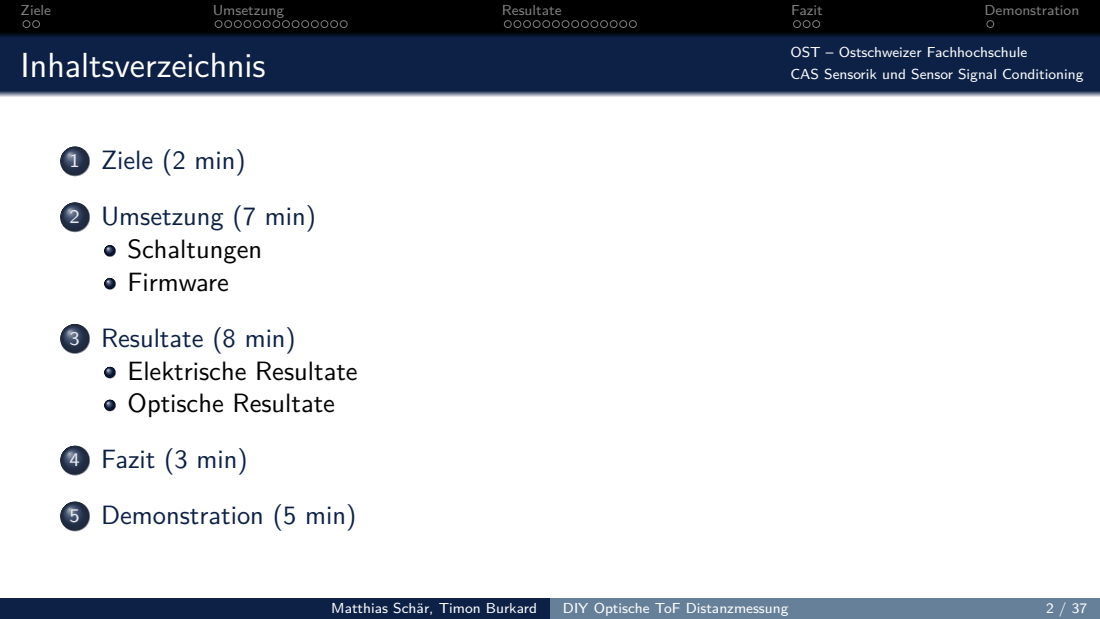
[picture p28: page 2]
Ziele; Umsetzung; Resultate; Fazit; Demonstration; Inhaltsverzeichnis; OST – Ostschweizer Fachhochschule; Umsetzung (7 min); Schaltungen Firmware; Resultate (8 min); Elektrische Resultate Optische Resultate; Fazit (3 min); Demonstration (5 min); Matthias Sch¨ar, Timon Burkard; DIY Optische ToF Distanzmessung

CAS Sensorik und Sensor Signal Conditioning

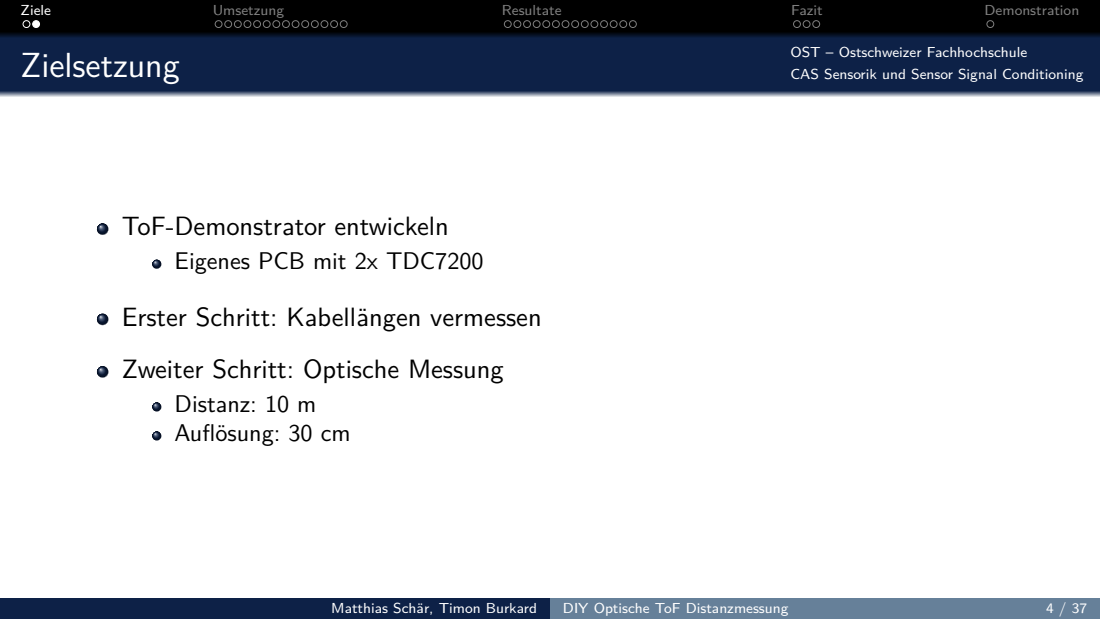
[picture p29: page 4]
Zielsetzung; OST – Ostschweizer Fachhochschule; Matthias Sch¨ar, Timon Burkard; DIY Optische ToF Distanzmessung

CAS Sensorik und Sensor Signal Conditioning

ToF-Demonstrator entwickeln
Eigenes PCB mit 2x TDC7200

Erster Schritt: Kabell¨angen vermessen

Zweiter Schritt: Optische Messung
Distanz: 10 m
Aufl¨osung: 30 cm

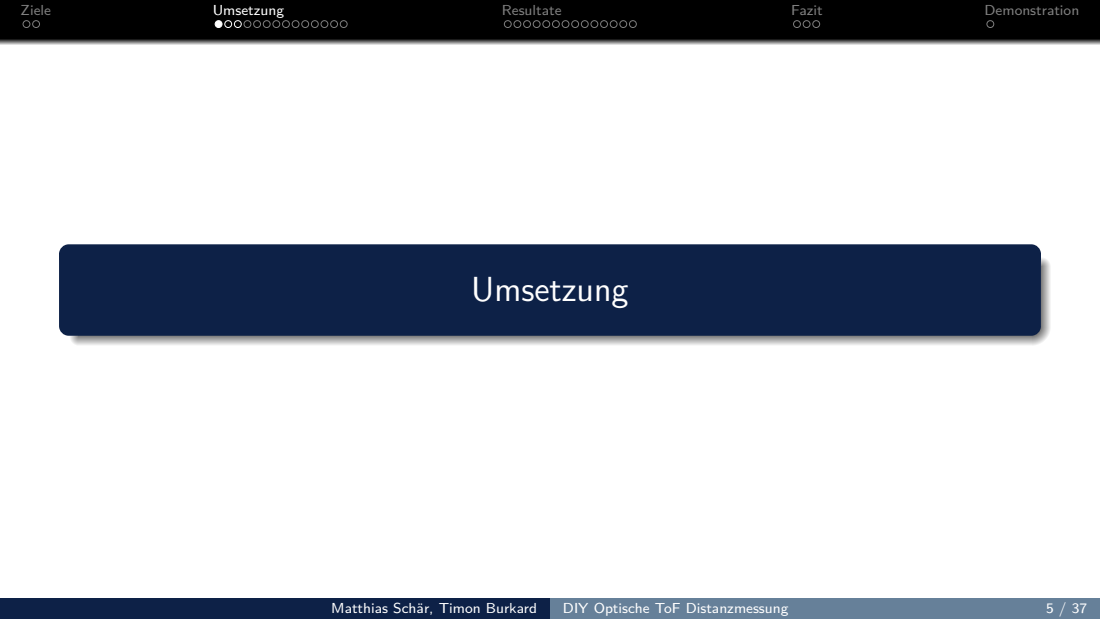
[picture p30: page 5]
Umsetzung; Matthias Sch¨ar, Timon Burkard; DIY Optische ToF Distanzmessung

## USB

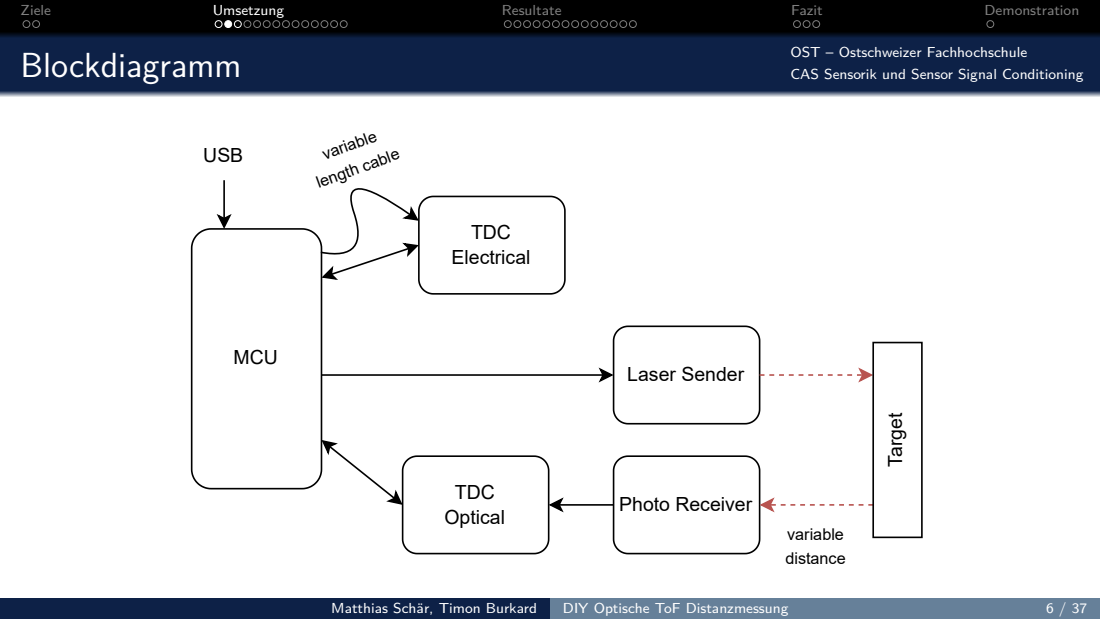
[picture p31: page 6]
Blockdiagramm; OST – Ostschweizer Fachhochschule; MCU; TDC Electrical; TDC Optical; Laser Sender; Photo Receiver; Target; variable length cable; variable distance; Matthias Sch¨ar, Timon Burkard; DIY Optische ToF Distanzmessung

CAS Sensorik und Sensor Signal Conditioning

## USB

CAS Sensorik und Sensor Signal Conditioning

CAS Sensorik und Sensor Signal Conditioning

Diode Amplifier Digital
Conversion

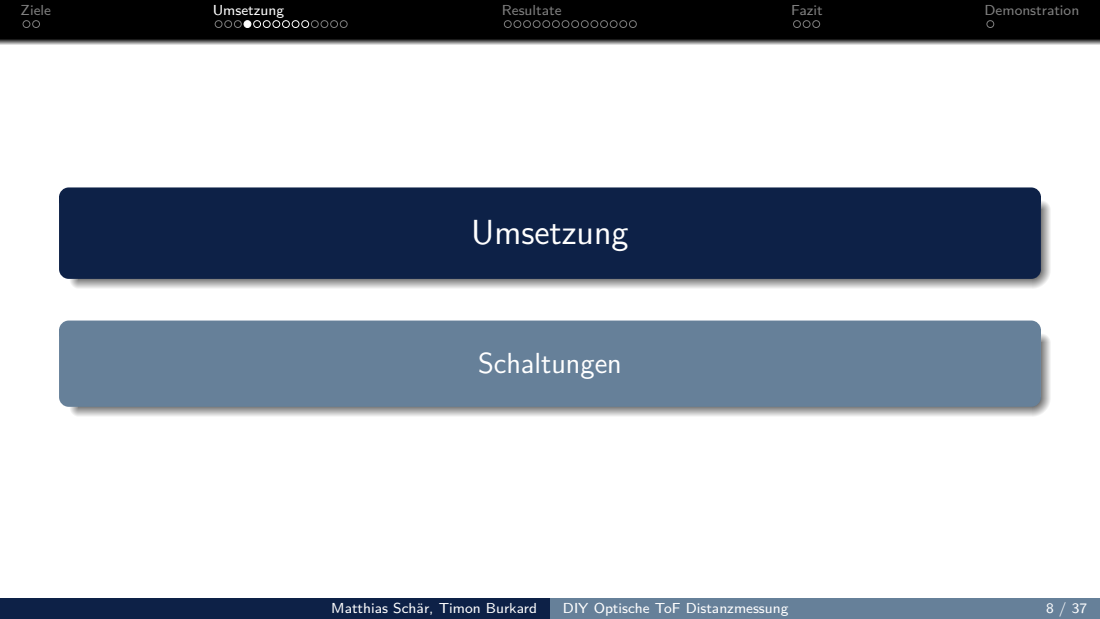
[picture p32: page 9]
Umsetzung; Schaltungen; Matthias Sch¨ar, Timon Burkard; DIY Optische ToF Distanzmessung

CAS Sensorik und Sensor Signal Conditioning

CAS Sensorik und Sensor Signal Conditioning

CAS Sensorik und Sensor Signal Conditioning

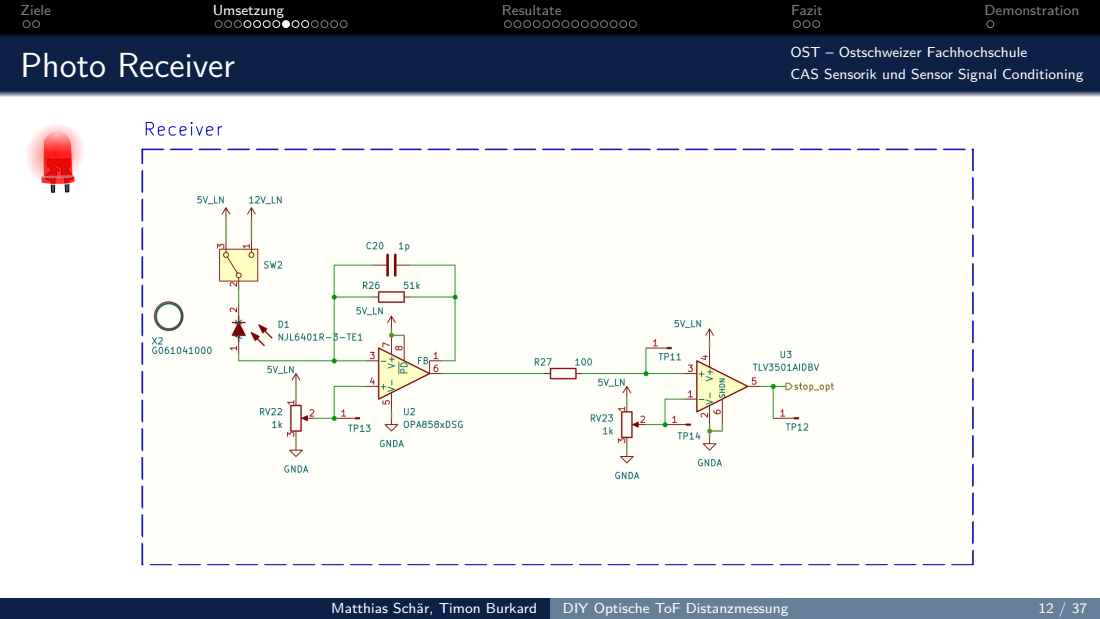
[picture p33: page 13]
Photo Receiver; OST – Ostschweizer Fachhochschule; Matthias Sch¨ar, Timon Burkard; DIY Optische ToF Distanzmessung

CAS Sensorik und Sensor Signal Conditioning

CAS Sensorik und Sensor Signal Conditioning

CAS Sensorik und Sensor Signal Conditioning

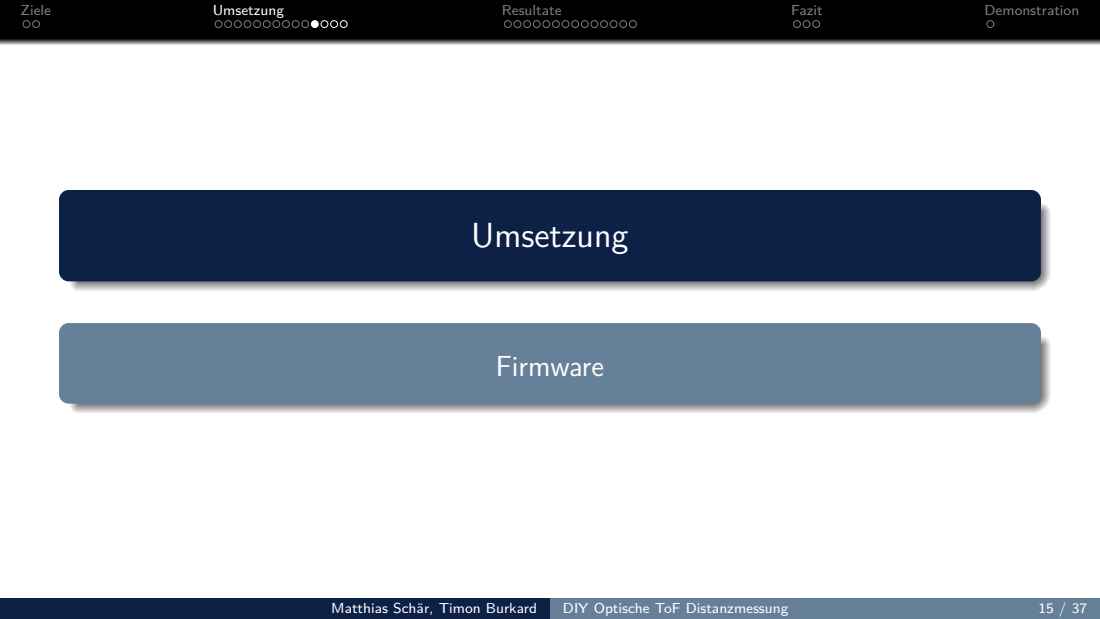
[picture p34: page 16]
Umsetzung; Firmware; Matthias Sch¨ar, Timon Burkard; DIY Optische ToF Distanzmessung

CAS Sensorik und Sensor Signal Conditioning

Application Driver Peripherals

CAS Sensorik und Sensor Signal Conditioning

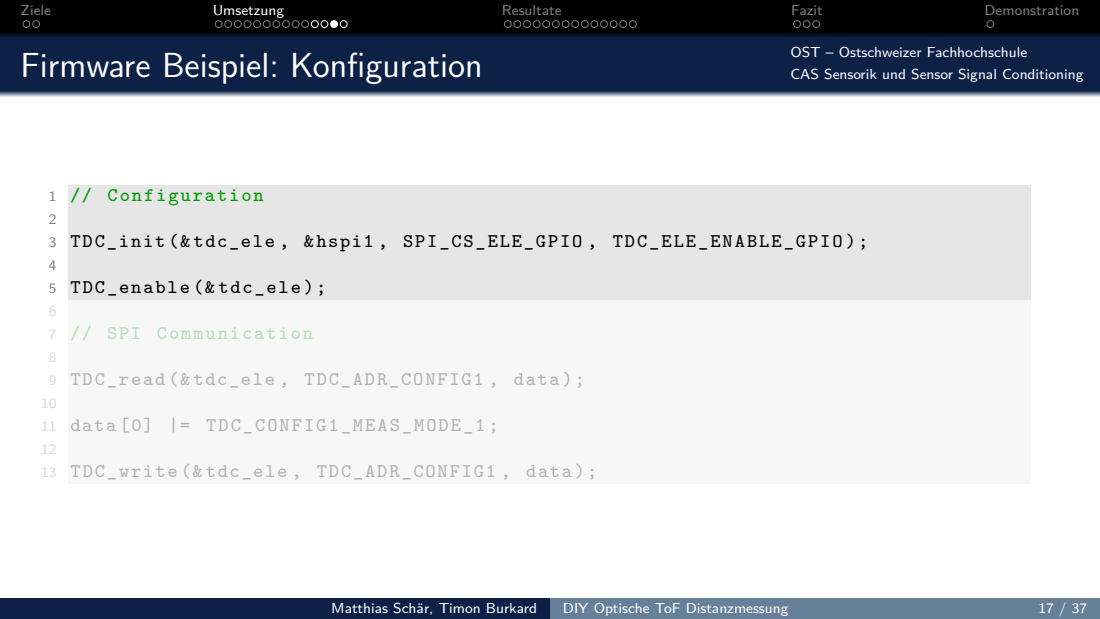
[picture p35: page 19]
Firmware Beispiel: Konfiguration; OST – Ostschweizer Fachhochschule; // Configuration; TDC_init (& tdc_ele , & hspi1 , SPI_CS_ELE_GPIO , TDC_ELE_ENABLE_GPIO );; TDC_enable (& tdc_ele );; // SPI Communication; TDC_read (& tdc_ele , TDC_ADR_CONFIG1 , data );; data [0] |= TDC_CONFIG1_MEAS_MODE_1 ;; TDC_write (& tdc_ele , TDC_ADR_CONFIG1 , data );; Matthias Sch¨ar, Timon Burkard; DIY Optische ToF Distanzmessung

CAS Sensorik und Sensor Signal Conditioning

CAS Sensorik und Sensor Signal Conditioning

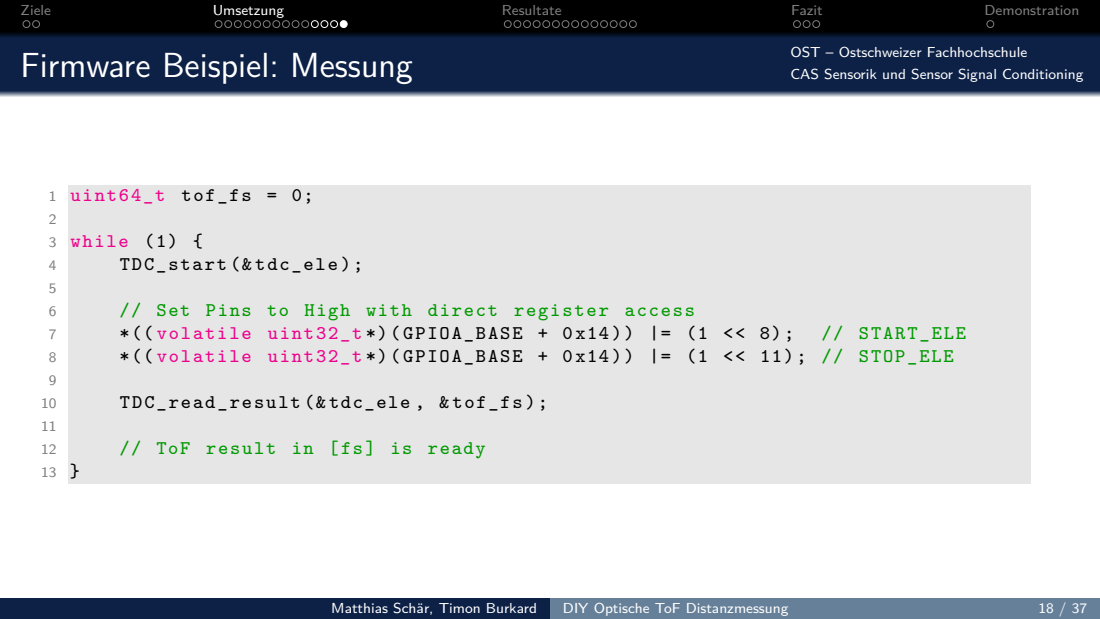
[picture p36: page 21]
Firmware Beispiel: Messung; OST – Ostschweizer Fachhochschule; uint64_t tof_fs = 0;; while (1) {; TDC_start (& tdc_ele );; // Set Pins to High with direct register access; *(( volatile uint32_t *) ( GPIOA_BASE + 0 x14 ) ) |= (1 << 8) ;; // START_ELE; *(( volatile uint32_t *) ( GPIOA_BASE + 0 x14 ) ) |= (1 << 11) ; // STOP_ELE; TDC_read_result (& tdc_ele , & tof_fs ) ;; // ToF result in [fs] is ready; Matthias Sch¨ar, Timon Burkard; DIY Optische ToF Distanzmessung

CAS Sensorik und Sensor Signal Conditioning

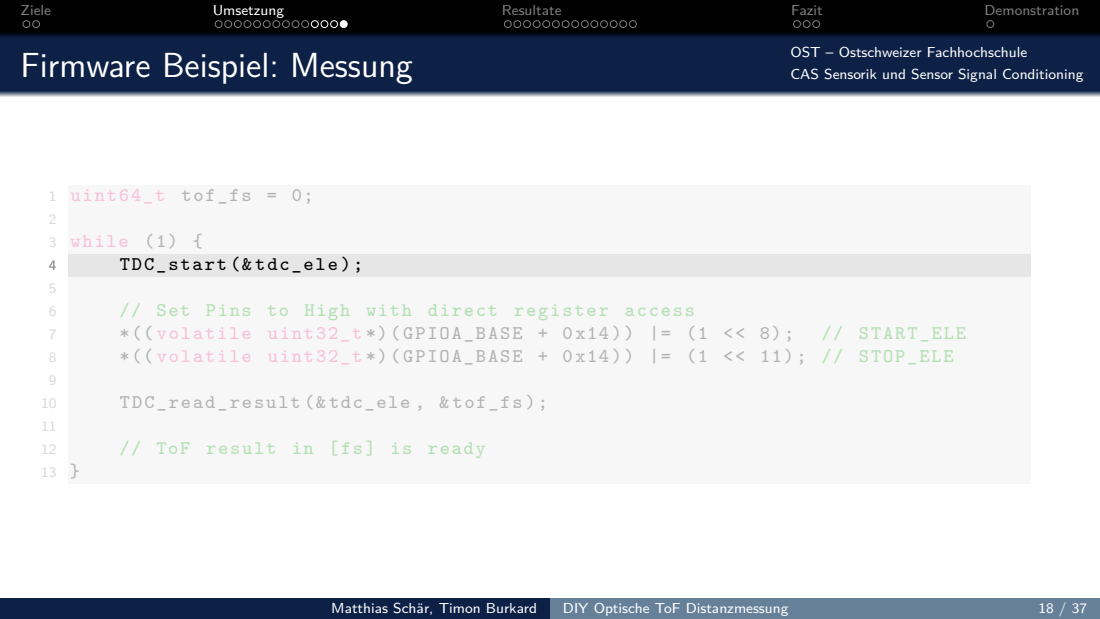
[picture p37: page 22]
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

CAS Sensorik und Sensor Signal Conditioning

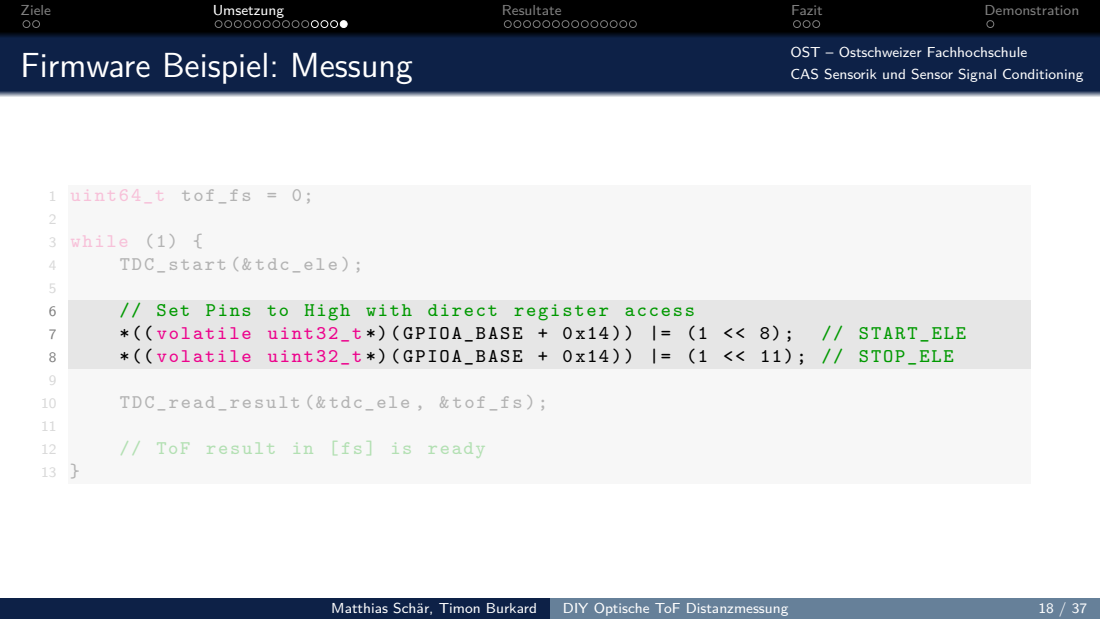
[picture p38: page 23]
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

CAS Sensorik und Sensor Signal Conditioning
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

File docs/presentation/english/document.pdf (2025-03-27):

# DIY Optical ToF Distance Measurement

# OST – Ostschweizer Fachhochschule

## CAS Sensors and Sensor Signal Conditioning

## Matthias Sch¨ar, Timon Burkard

28.03.2025

# 1 Objective (3 min)

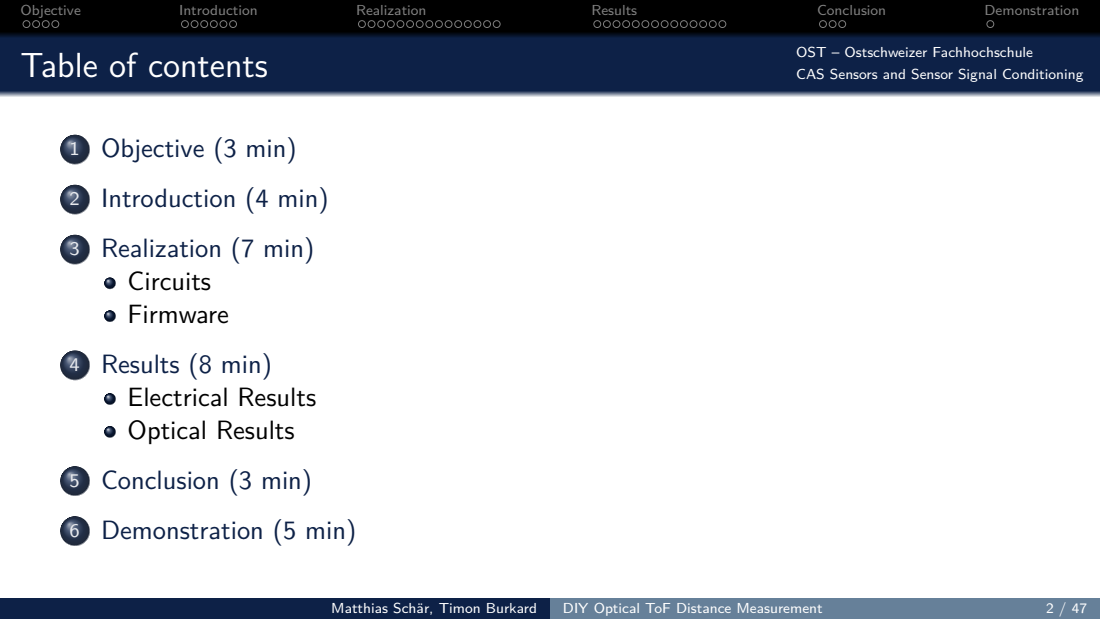
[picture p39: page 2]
Objective; Introduction; Realization; Results; Conclusion; Demonstration; Table of contents; OST – Ostschweizer Fachhochschule; Introduction (4 min); Realization (7 min); Circuits Firmware; Results (8 min); Electrical Results Optical Results; Conclusion (3 min); Demonstration (5 min); Matthias Sch¨ar, Timon Burkard; DIY Optical ToF Distance Measurement

CAS Sensors and Sensor Signal Conditioning

Objective; Matthias Sch¨ar, Timon Burkard; DIY Optical ToF Distance Measurement

CAS Sensors and Sensor Signal Conditioning

Part of a CAS – Certificate Advanced Studies
CAS are post graduate studies (after bachelor/master)
CAS typically take 15 ECTS / 1 semester
Part time, e.g., Fri + Sat

CAS Sensors and Sensor Signal Conditioning

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

CAS Sensors and Sensor Signal Conditioning[1]

As part of it: 5 week project work

Objective; OST – Ostschweizer Fachhochschule; Matthias Sch¨ar, Timon Burkard; DIY Optical ToF Distance Measurement

CAS Sensors and Sensor Signal Conditioning

Get familiar with TDCs (Time to Digital Converters)
Find out how much effort it takes to get TDC application running

CAS Sensors and Sensor Signal Conditioning

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

Develop optical ToF demonstrator for distance measurement
Custom PCB with 2x TDC7200

Objective; OST – Ostschweizer Fachhochschule; Matthias Sch¨ar, Timon Burkard; DIY Optical ToF Distance Measurement

CAS Sensors and Sensor Signal Conditioning

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

Develop optical ToF demonstrator for distance measurement
Custom PCB with 2x TDC7200

First step: Electrical measurements (cable lengths)

Second step: Optical measurements
Distance: 10 m
Resolution: 30 cm

CAS Sensors and Sensor Signal Conditioning

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

Develop optical ToF demonstrator for distance measurement
Custom PCB with 2x TDC7200

First step: Electrical measurements (cable lengths)

Second step: Optical measurements
Distance: 10 m
Resolution: 30 cm

⇒ Focused on getting practical experience; not very scientific

CAS Sensors and Sensor Signal Conditioning

I’m trying not to get too technical

Full project (HW + FW) is available on GitHub:
https://github.com/MatiMcFly/DIY ToF (https://github.com/MatiMcFly/DIY_ToF)

GitHub; OST – Ostschweizer Fachhochschule; Matthias Sch¨ar, Timon Burkard; DIY Optical ToF Distance Measurement

CAS Sensors and Sensor Signal Conditioning

I’m trying not to get too technical

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

Documentation English: https://github.com/MatiMcFly/DIY ToF/blob/main/
docs/documentation/english/documentation.pdf (https://github.com/MatiMcFly/DIY_ToF/blob/main/docs/documentation/english/documentation.pdf)
Automatically translated with DeepL

Original German version: https://github.com/MatiMcFly/DIY ToF/blob/main/
docs/documentation/documentation.pdf (https://github.com/MatiMcFly/DIY_ToF/blob/main/docs/documentation/documentation.pdf)

CAS Sensors and Sensor Signal Conditioning

ToF = Time of Flight

It is the time it takes for a signal to travel from the sender to the receiver

ToF: Distance measurement; OST – Ostschweizer Fachhochschule; Matthias Sch¨ar, Timon Burkard; DIY Optical ToF Distance Measurement

CAS Sensors and Sensor Signal Conditioning

Role models: bat, dolphin

# Technical: Ultra sonic, radar, laser

CAS Sensors and Sensor Signal Conditioning

Role models: bat, dolphin
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

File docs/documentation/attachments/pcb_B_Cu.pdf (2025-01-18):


Id: 1/1 Title: File: diy_tof_hw.kicad_pcb Sheet:




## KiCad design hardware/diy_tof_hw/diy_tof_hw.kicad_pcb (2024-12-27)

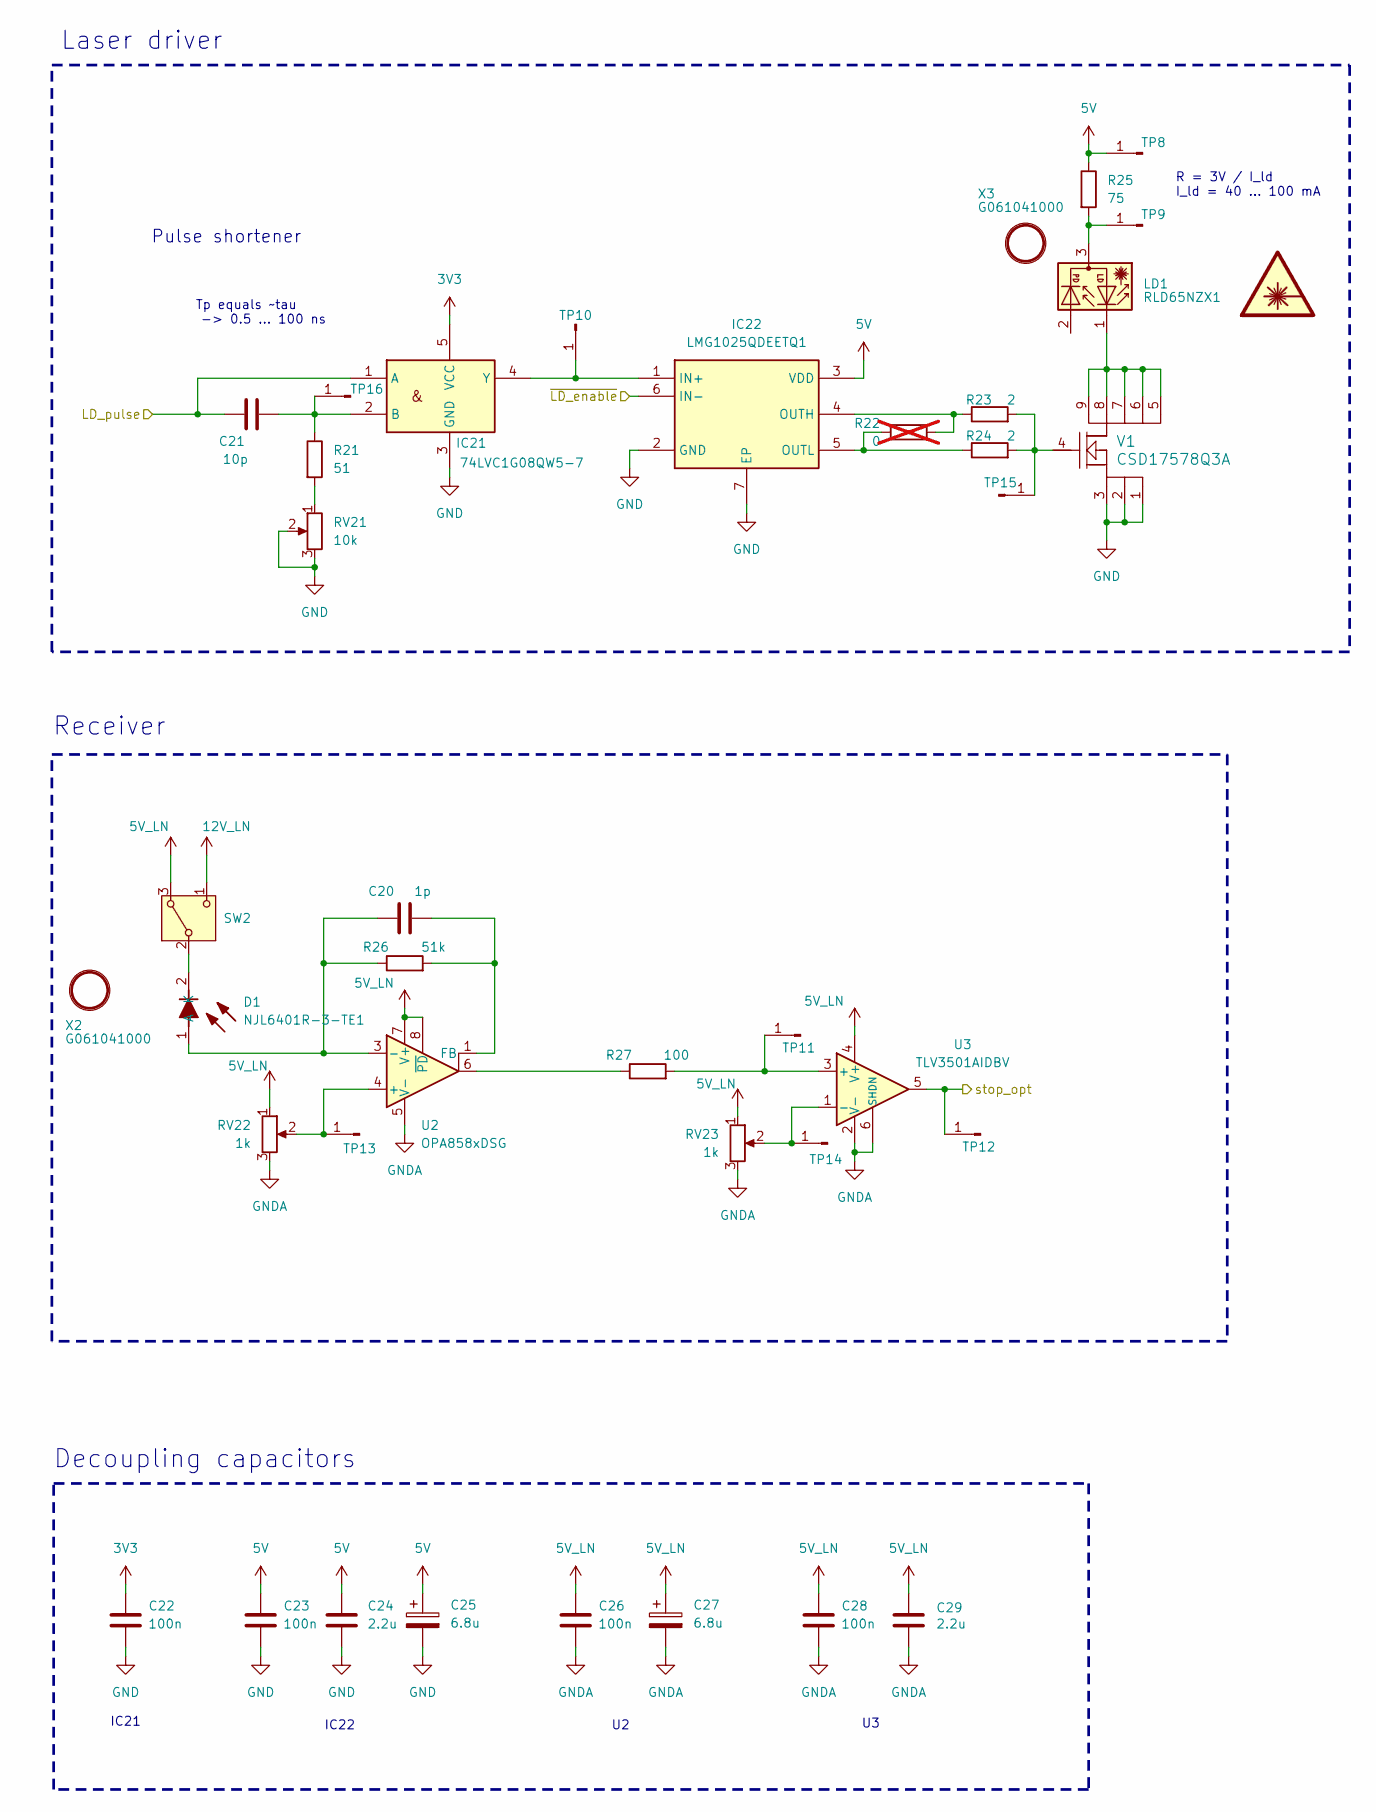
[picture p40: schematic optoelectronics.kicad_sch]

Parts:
C20: 1p; C_0402_1005Metric_Pad0.74x0.62mm_HandSolder
C21: 10p; C_0402_1005Metric_Pad0.74x0.62mm_HandSolder
C22, C23, C26, C28: 100n; C_0402_1005Metric_Pad0.74x0.62mm_HandSolder
C24, C29: 2.2u; C_0603_1608Metric_Pad1.08x0.95mm_HandSolder
C25, C27: 6.8u; CP_EIA-7343-43_Kemet-X_Pad2.25x2.55mm_HandSolder
D1: NJL6401R-3-TE1; NJL6401R3TE1; Mouser Part Number 513-NJL6401R-3-TE1
IC21: 74LVC1G08QW5-7; 74LVC1G08QW57; Mouser Part Number 621-74LVC1G08QW5-7
IC22: LMG1025QDEETQ1; SON65P200X200X80-7N; Mouser Part Number 595-LMG1025QDEETQ1
LD1: RLD65NZX1; RLD85PZJ400A
R21: 51; R_0402_1005Metric_Pad0.72x0.64mm_HandSolder
R22: 0; R_0402_1005Metric_Pad0.72x0.64mm_HandSolder; not fitted
R23, R24: 2; R_0402_1005Metric_Pad0.72x0.64mm_HandSolder
R25: 75; R_0603_1608Metric_Pad0.98x0.95mm_HandSolder
R26: 51k; R_0402_1005Metric_Pad0.72x0.64mm_HandSolder
R27: 100; R_0402_1005Metric_Pad0.72x0.64mm_HandSolder
RV21: 10k; Potentiometer_Bourns_3224W_Vertical
RV22, RV23: 1k; Potentiometer_Bourns_3224W_Vertical
SW2: SW_Nidec_CAS-120A1; Nidec_Copal_CAS-120A
TP8, TP9, TP10, TP11, TP12, TP13, TP14, TP15, TP16: Conn_01x01_Pin; PinHeader_1x01_P2.54mm_Vertical
U2: OPA858xDSG; WSON-8-1EP_2x2mm_P0.5mm_EP0.9x1.6mm
U3: TLV3501AIDBV; SOT-23-6
V1: CSD17578Q3A; DNH0008A
X2, X3: G061041000; Qioptiq_Mount

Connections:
3V3: C22.1, IC21.5 (VCC); also elsewhere on the board
5V: C23.1, C24.1, C25.1, IC22.3 (VDD), R25.1, TP8.1; also elsewhere on the board
5V_LN: C26.1, C27.1, C28.1, C29.1, RV22.1, RV23.1, SW2.3 (A), U2.7 (V+), U2.8 (~PD), U3.4 (V+); also elsewhere on the board
12V_LN: SW2.1 (C); also elsewhere on the board
/Optoelectronics/LD_pulse: C21.1, IC21.1 (A); also elsewhere on the board
/Optoelectronics/stop_opt: TP12.1, U3.5; also elsewhere on the board
/Optoelectronics/~LD_enable: IC22.6 (IN-); also elsewhere on the board
GND: C22.2, C23.2, C24.2, C25.2, IC21.3 (GND), IC22.2 (GND), IC22.7 (EP), RV21.2, RV21.3, V1.1, V1.2, V1.3; also elsewhere on the board
GNDA: C26.2, C27.2, C28.2, C29.2, RV22.3, RV23.3, U2.5 (V-), U2.9 (V-), U3.2 (V-), U3.6 (SHDN); also elsewhere on the board
unnamed: C20.1, D1.1 (A), R26.1, U2.3 (-)
unnamed: D1.2 (K), SW2.2 (B)
unnamed: C21.2, IC21.2 (B), R21.1, TP16.1
unnamed: IC21.4 (Y), IC22.1 (IN+), TP10.1
unnamed: IC22.4 (OUTH), R22.2, R23.1
unnamed: IC22.5 (OUTL), R22.1, R24.1
unnamed: LD1.1, V1.5, V1.6, V1.7, V1.8, V1.9
unnamed: R21.2, RV21.1
unnamed: R27.1, U2.6
unnamed: LD1.3, R25.2, TP9.1
unnamed: R27.2, TP11.1, U3.3 (+)
unnamed: RV22.2, TP13.1, U2.4 (+)
unnamed: RV23.2, TP14.1, U3.1 (-)
unnamed: R23.2, R24.2, TP15.1, V1.4
unnamed: C20.2, R26.2, U2.1 (FB)

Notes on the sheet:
Decoupling capacitors
IC22
Laser driver
R = 3V / I_ld I_ld = 40 ... 100 mA
Tp equals ~tau -> 0.5 ... 100 ns
IC21
Receiver
Pulse shortener

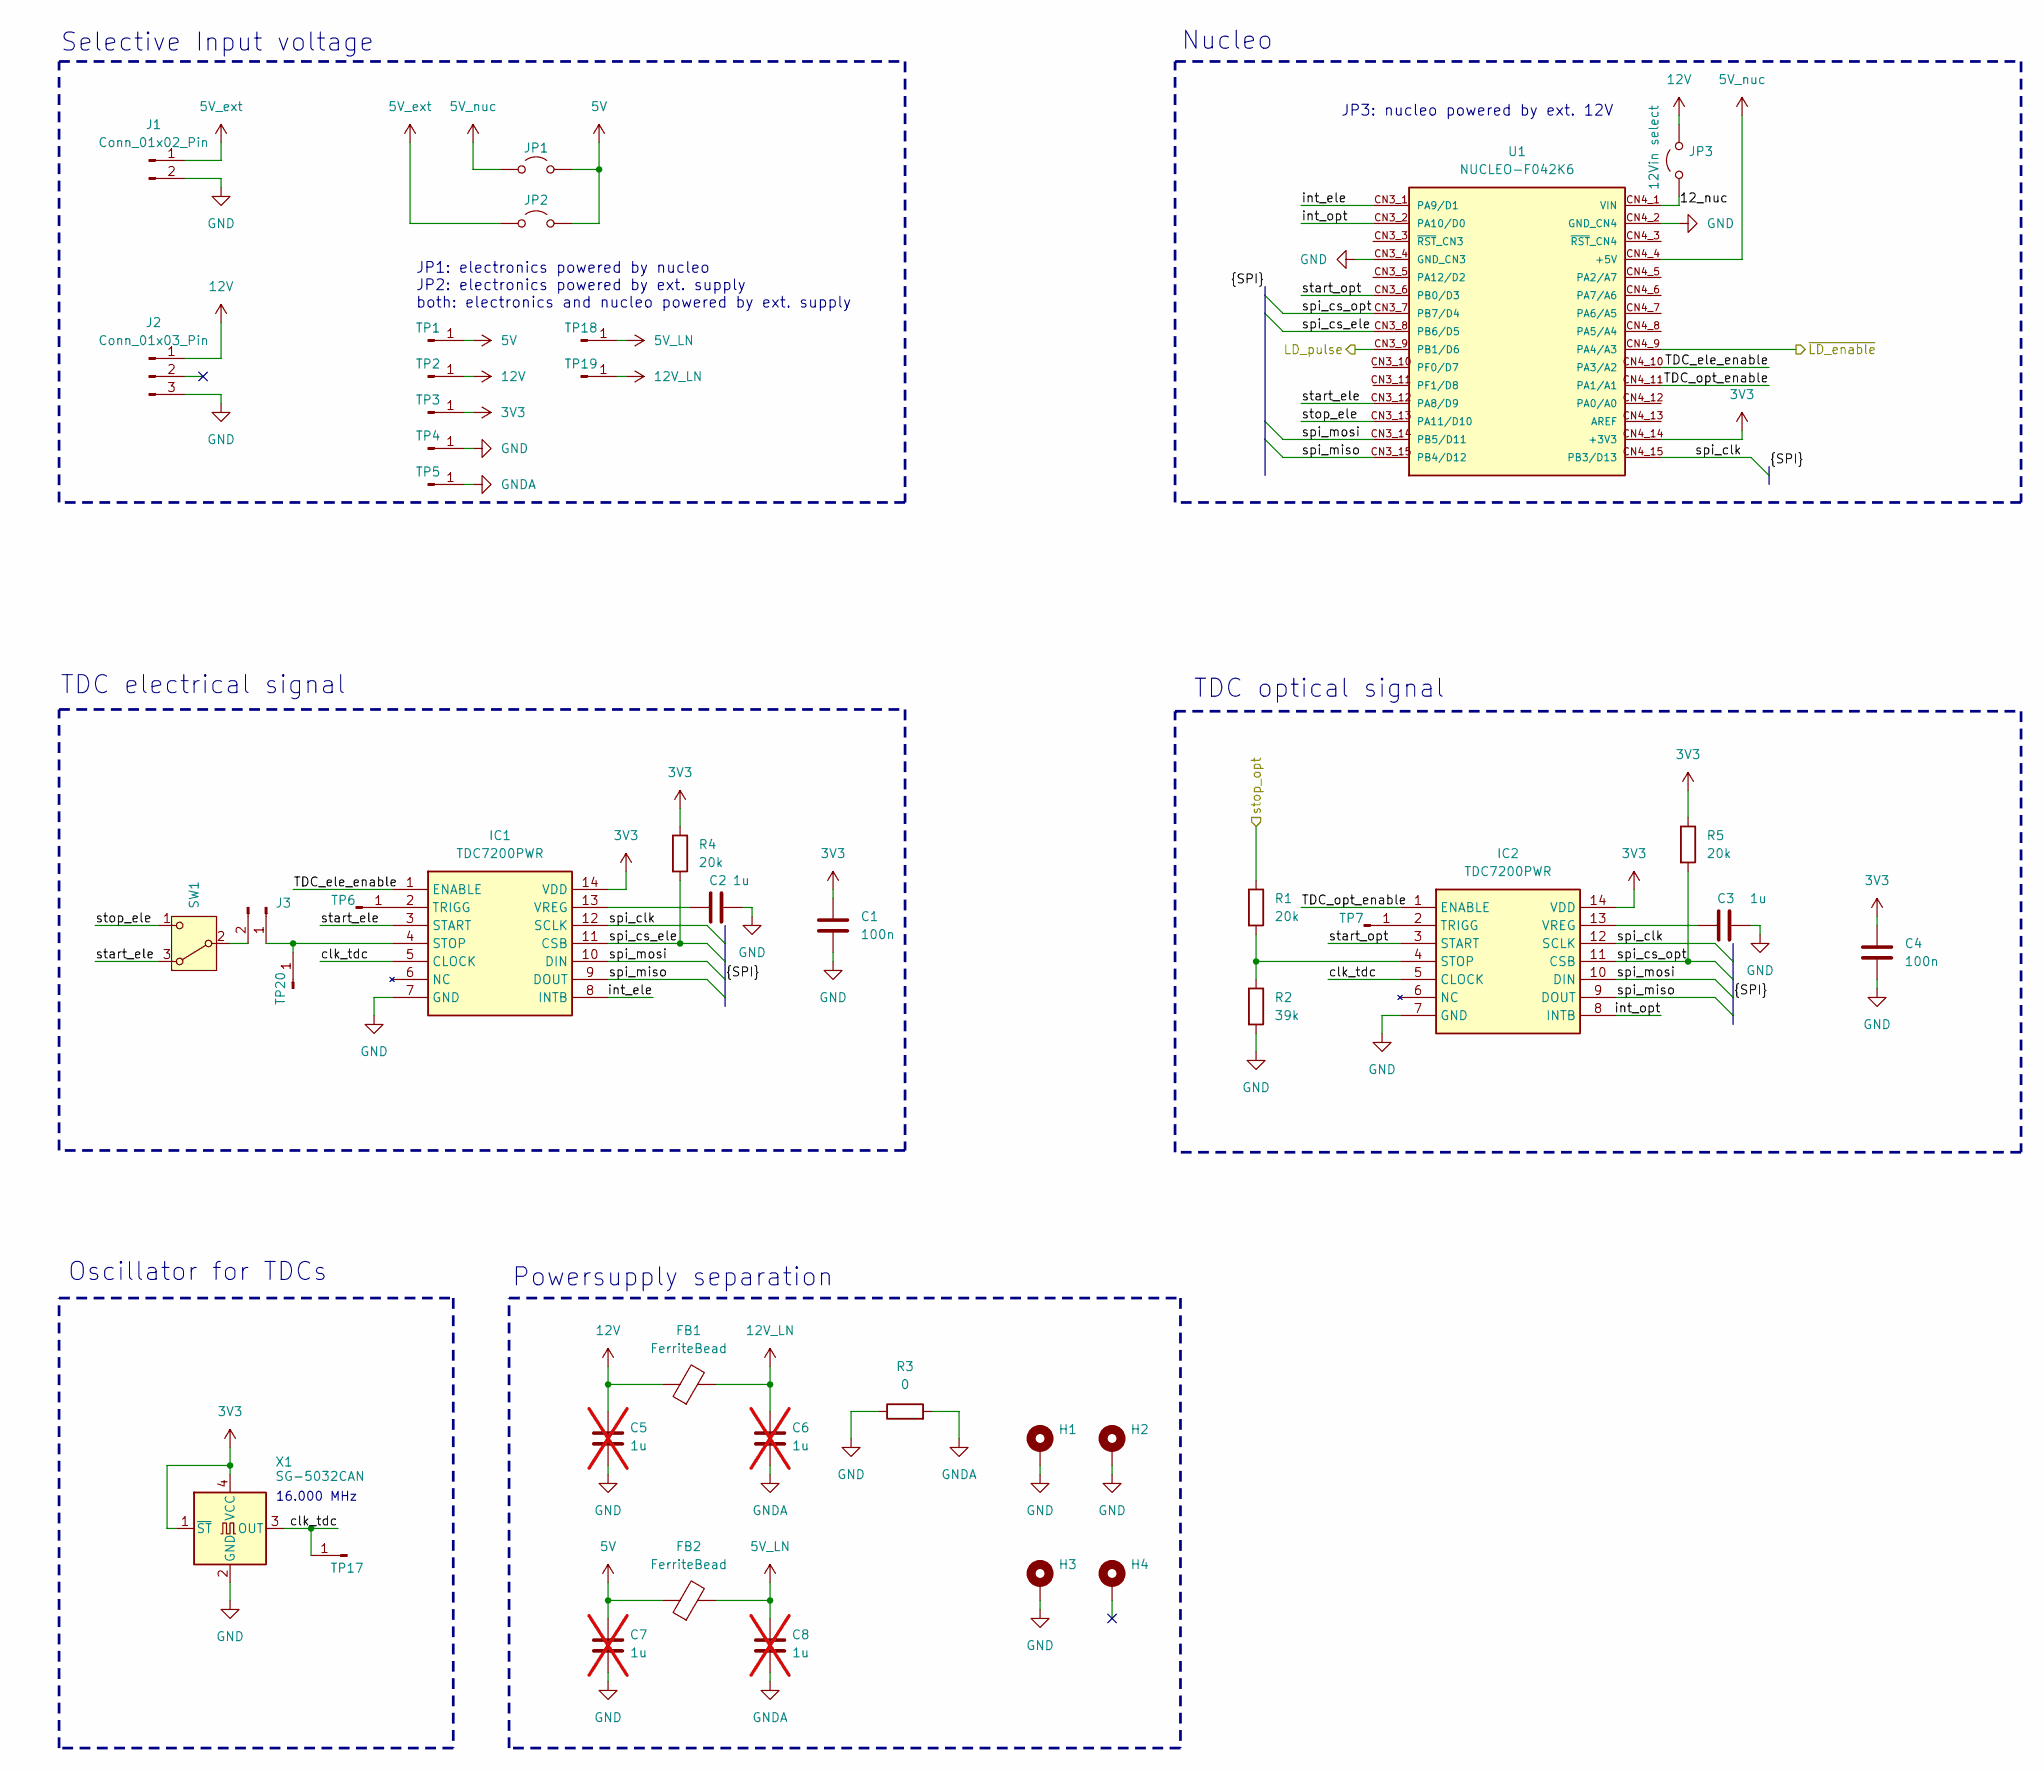
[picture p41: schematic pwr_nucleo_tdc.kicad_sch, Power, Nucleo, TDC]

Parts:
C1, C4: 100n; C_0402_1005Metric_Pad0.74x0.62mm_HandSolder
C2, C3: 1u; C_0402_1005Metric_Pad0.74x0.62mm_HandSolder
C5, C6, C7, C8: 1u; C_0402_1005Metric_Pad0.74x0.62mm_HandSolder; not fitted
FB1, FB2: FerriteBead; L_0402_1005Metric_Pad0.77x0.64mm_HandSolder
H1, H2, H3, H4: MountingHole_Pad; MountingHole_3.2mm_M3_DIN965_Pad_TopBottom
IC1, IC2: TDC7200PWR; SOP65P640X120-14N; Mouser Part Number 595-TDC7200PWR
J1, J3: Conn_01x02_Pin; Molex_KK-254_AE-6410-02A_1x02_P2.54mm_Vertical
J2: Conn_01x03_Pin; Molex_SL_171971-0003_1x03_P2.54mm_Vertical
JP1, JP2: Jumper_2_Open; TestPoint_2Pads_Pitch2.54mm_Drill0.8mm
JP3: 12Vin select; TestPoint_2Pads_Pitch2.54mm_Drill0.8mm
R1, R4, R5: 20k; R_0402_1005Metric_Pad0.72x0.64mm_HandSolder
R2: 39k; R_0402_1005Metric_Pad0.72x0.64mm_HandSolder
R3: 0; R_0402_1005Metric_Pad0.72x0.64mm_HandSolder
SW1: SW_Nidec_CAS-120A1; Nidec_Copal_CAS-120A
TP1, TP2, TP3, TP4, TP5, TP6, TP7, TP17, TP18, TP19, TP20: Conn_01x01_Pin; PinHeader_1x01_P2.54mm_Vertical
U1: NUCLEO-F042K6; MODULE_NUCLEO-F042K6; PARTREV 8
X1: SG-5032CAN; Oscillator_SMD_SeikoEpson_SG8002LB-4Pin_5.0x3.2mm_HandSolde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

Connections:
3V3: C1.1, C4.1, IC1.14 (VDD), IC2.14 (VDD), R4.1, R5.1, TP3.1, U1.CN4_14 (+3V3), X1.1 (~ST), X1.4 (VCC); also elsewhere on the board
5V: C7.2, FB2.1, JP1.2 (B), JP2.2 (B), TP1.1; also elsewhere on the board
5V_LN: C8.2, FB2.2, TP18.1; also elsewhere on the board
5V_ext: J1.1, JP2.1 (A)
5V_nuc: JP1.1 (A), U1.CN4_4 (+5V)
12V: C5.2, FB1.1, J2.1, JP3.2 (B), TP2.1
12V_LN: C6.2, FB1.2, TP19.1; also elsewhere on the board
/Optoelectronics/LD_pulse: U1.CN3_9 (PB1/D6); also elsewhere on the board
/Optoelectronics/stop_opt: R1.1; also elsewhere on the board
/Optoelectronics/~LD_enable: U1.CN4_9 (PA4/A3); also elsewhere on the board
/Power_Nucleo_TDC/12_nuc: JP3.1 (A), U1.CN4_1 (VIN)
/Power_Nucleo_TDC/TDC_ele_enable: IC1.1 (ENABLE), U1.CN4_10 (PA3/A2)
/Power_Nucleo_TDC/TDC_opt_enable: IC2.1 (ENABLE), U1.CN4_11 (PA1/A1)
/Power_Nucleo_TDC/clk_tdc: IC1.5 (CLOCK), IC2.5 (CLOCK), TP17.1, X1.3 (OUT)
/Power_Nucleo_TDC/int_ele: IC1.8 (INTB), U1.CN3_1 (PA9/D1)
/Power_Nucleo_TDC/int_opt: IC2.8 (INTB), U1.CN3_2 (PA10/D0)
/Power_Nucleo_TDC/spi_clk: IC1.12 (SCLK), IC2.12 (SCLK), U1.CN4_15 (PB3/D13)
/Power_Nucleo_TDC/spi_cs_ele: IC1.11 (CSB), R4.2, U1.CN3_8 (PB6/D5)
/Power_Nucleo_TDC/spi_cs_opt: IC2.11 (CSB), R5.2, U1.CN3_7 (PB7/D4)
/Power_Nucleo_TDC/spi_miso: IC1.9 (DOUT), IC2.9 (DOUT), U1.CN3_15 (PB4/D12)
/Power_Nucleo_TDC/spi_mosi: IC1.10 (DIN), IC2.10 (DIN), U1.CN3_14 (PB5/D11)
/Power_Nucleo_TDC/start_ele: IC1.3 (START), SW1.3 (A), U1.CN3_12 (PA8/D9)
/Power_Nucleo_TDC/start_opt: IC2.3 (START), U1.CN3_6 (PB0/D3)
/Power_Nucleo_TDC/stop_ele: SW1.1 (C), U1.CN3_13 (PA11/D10)
GND: C1.2, C2.2, C3.2, C4.2, C5.1, C7.1, H1.1, H2.1, H3.1, IC1.7 (GND), IC2.7 (GND), J1.2, J2.3, R2.2, R3.1, TP4.1, U1.CN3_4 (GND_CN3), U1.CN4_2 (GND_CN4), X1.2 (GND); also elsewhere on the board
GNDA: C6.1, C8.1, R3.2, TP5.1; also elsewhere on the board
unnamed: IC1.4 (STOP), J3.1, TP20.1
unnamed: IC1.2 (TRIGG), TP6.1
unnamed: C2.1, IC1.13 (VREG)
unnamed: IC2.4 (STOP), R1.2, R2.1
unnamed: IC2.2 (TRIGG), TP7.1
unnamed: C3.1, IC2.13 (VREG)
unnamed: J3.2, SW1.2 (B)

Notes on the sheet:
Powersupply separation
Oscillator for TDCs
Nucleo
JP1: electronics powered by nucleo JP2: electronics powered by ext. supply both: electronics and nucleo powered by ext. supply
TDC optical signal
Selective Input voltage
16.000 MHz
JP3: nucleo powered by ext. 12V
TDC electrical signal

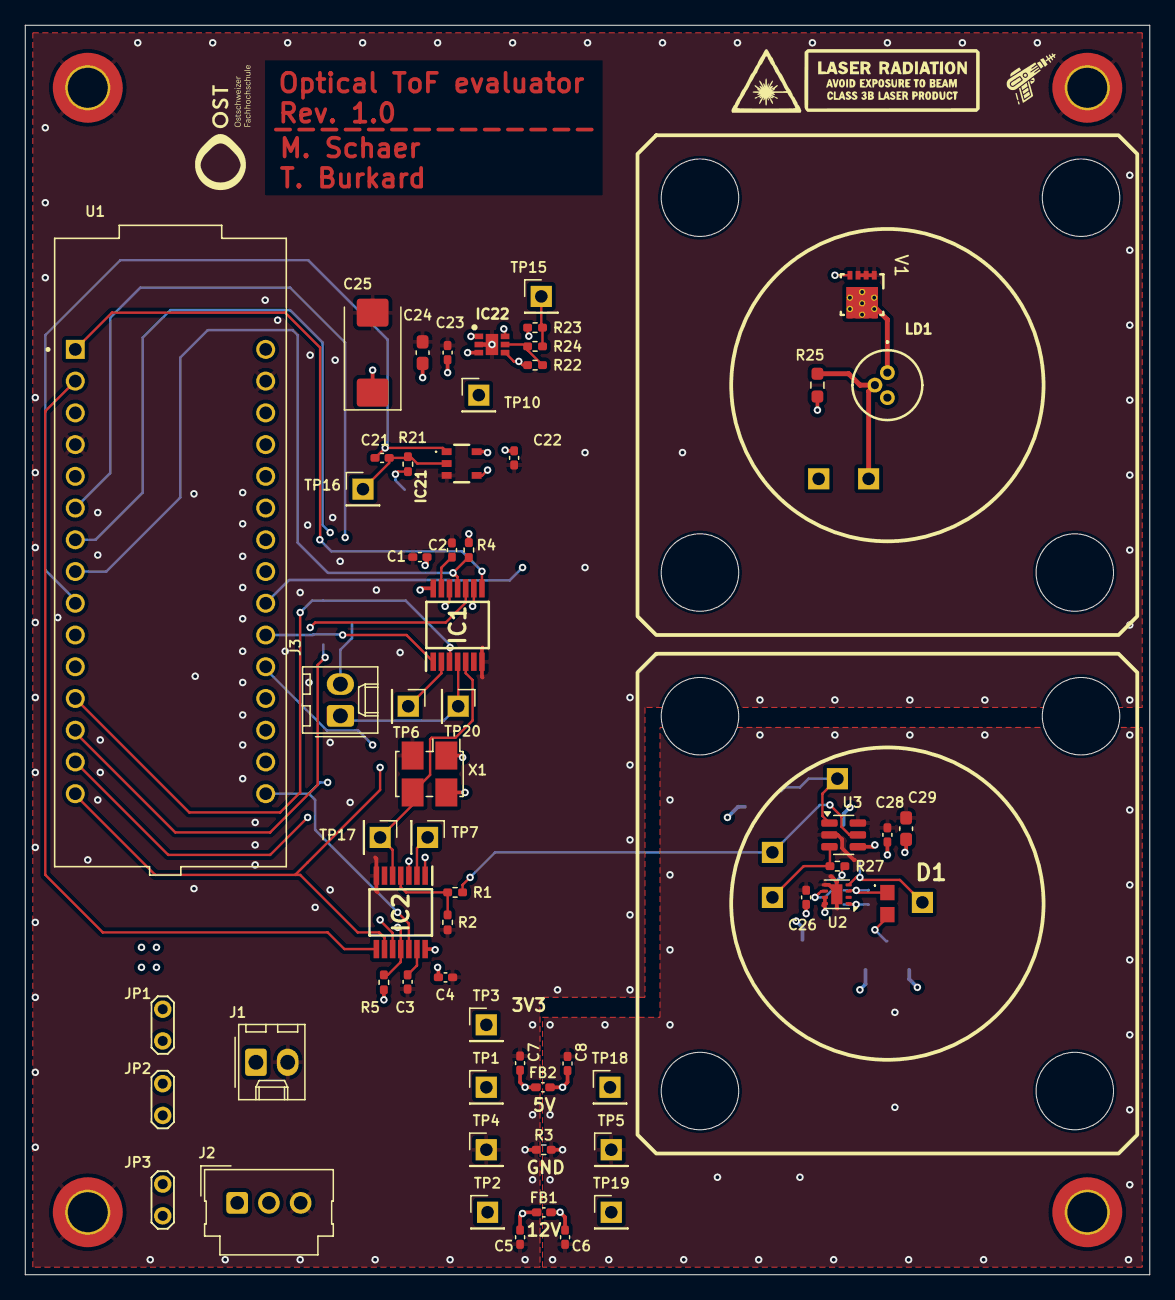
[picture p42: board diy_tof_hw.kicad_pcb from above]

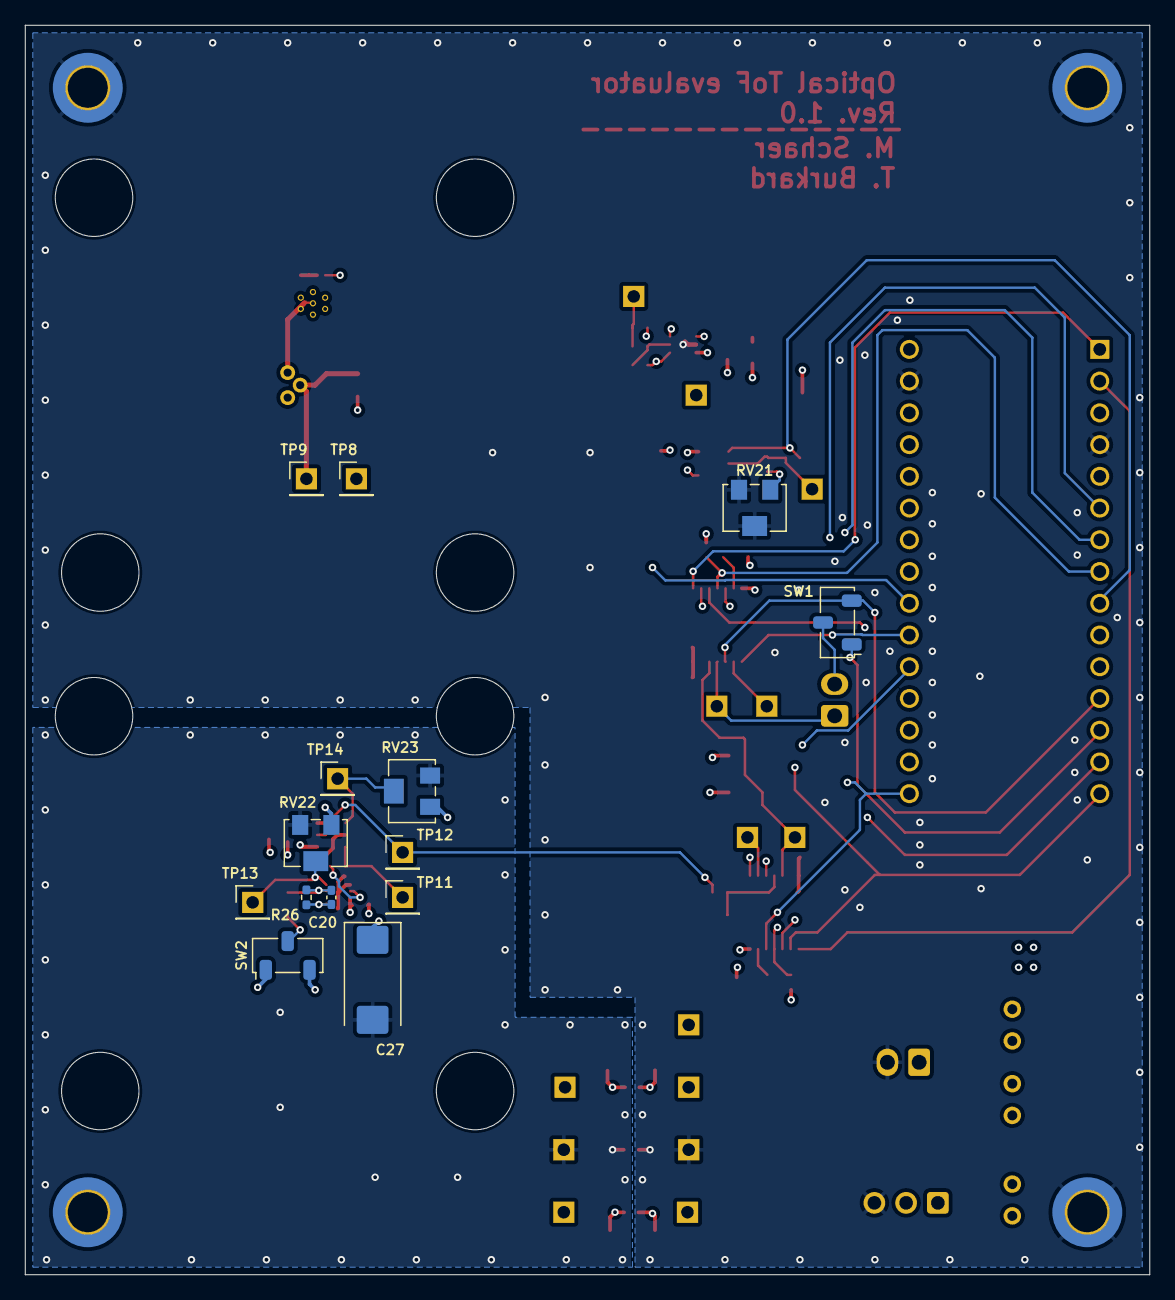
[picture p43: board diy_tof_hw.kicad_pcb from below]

Board: 4 copper layers, 90.0 x 100.0 mm, 80 parts (14 on the bottom side), 48 nets.

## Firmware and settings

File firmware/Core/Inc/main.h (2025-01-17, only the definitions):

#define MCO_Pin GPIO_PIN_0
#define MCO_GPIO_Port GPIOF
#define TDC_OPT_ENABLE_Pin GPIO_PIN_1
#define TDC_OPT_ENABLE_GPIO_Port GPIOA
#define VCP_TX_Pin GPIO_PIN_2
#define VCP_TX_GPIO_Port GPIOA
#define TDC_ELE_ENABLE_Pin GPIO_PIN_3
#define TDC_ELE_ENABLE_GPIO_Port GPIOA
#define LD_ENABLE_Pin GPIO_PIN_4
#define LD_ENABLE_GPIO_Port GPIOA
#define START_OPT_Pin GPIO_PIN_0
#define START_OPT_GPIO_Port GPIOB
#define LD_PULSE_Pin GPIO_PIN_1
#define LD_PULSE_GPIO_Port GPIOB
#define START_ELE_Pin GPIO_PIN_8
#define START_ELE_GPIO_Port GPIOA
#define INT_ELE_Pin GPIO_PIN_9
#define INT_ELE_GPIO_Port GPIOA
#define INT_OPT_Pin GPIO_PIN_10
#define INT_OPT_GPIO_Port GPIOA
#define STOP_ELE_Pin GPIO_PIN_11
#define STOP_ELE_GPIO_Port GPIOA
#define SWDIO_Pin GPIO_PIN_13
#define SWDIO_GPIO_Port GPIOA
#define SWCLK_Pin GPIO_PIN_14
#define SWCLK_GPIO_Port GPIOA
#define VCP_RX_Pin GPIO_PIN_15
#define VCP_RX_GPIO_Port GPIOA
#define SPI_CLK_Pin GPIO_PIN_3
#define SPI_CLK_GPIO_Port GPIOB
#define SPI_MISO_Pin GPIO_PIN_4
#define SPI_MISO_GPIO_Port GPIOB
#define SPI_MOSI_Pin GPIO_PIN_5
#define SPI_MOSI_GPIO_Port GPIOB
#define SPI_CS_ELE_Pin GPIO_PIN_6
#define SPI_CS_ELE_GPIO_Port GPIOB
#define SPI_CS_OPT_Pin GPIO_PIN_7
#define SPI_CS_OPT_GPIO_Port GPIOB

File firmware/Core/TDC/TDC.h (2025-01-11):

/*
 * TDC.h
 *
 * Driver for TI TDC7200 -- Header file
 *
 * (C) T. Burkard | M. Schaer
 *
 */

#ifndef TDC_H_
#define TDC_H_

#include <stdint.h>
#include "stm32f0xx_hal.h"

#define TDC_CLOCK_PERIOD_FS 62500000 // 16 MHz in [fs]

/**
 * Convert 24bit buffer received from SPI to integer
 */
#define TDC_24BIT_BUF_TO_INT(buf) ((buf[0] << 16) + (buf[1] << 8) + buf[2])

/**
 * @brief Register addresses of the TDC
 *
 */
typedef enum {
    TDC_ADR_CONFIG1                = 0x00, // Configuration Register 1
    TDC_ADR_CONFIG2                = 0x01, // Configuration Register 2
    TDC_ADR_INT_STATUS             = 0x02, // Interrupt Status Register
    TDC_ADR_INT_MASK               = 0x03, // Interrupt Mask Register
    TDC_ADR_COARSE_CNTR_OVF_H      = 0x04, // Coarse Counter Overflow Value High
    TDC_ADR_COARSE_CNTR_OVF_L      = 0x05, // Coarse Counter Overflow Value Low
    TDC_ADR_CLOCK_CNTR_OVF_H       = 0x06, // CLOCK Counter Overflow Value High
    TDC_ADR_CLOCK_CNTR_OVF_L       = 0x07, // CLOCK Counter Overflow Value Low
    TDC_ADR_CLOCK_CNTR_STOP_MASK_H = 0x08, // CLOCK Counter STOP Mask High
    TDC_ADR_CLOCK_CNTR_STOP_MASK_L = 0x09, // CLOCK Counter STOP Mask Low
    TDC_ADR_TIME1                  = 0x10, // Measured Time 1
    TDC_ADR_CLOCK_COUNT1           = 0x11, // CLOCK Counter Value
    TDC_ADR_TIME2                  = 0x12, // Measured Time 2
    TDC_ADR_CLOCK_COUNT2           = 0x13, // CLOCK Counter Value
    TDC_ADR_TIME3                  = 0x14, // Measured Time 3
    TDC_ADR_CLOCK_COUNT3           = 0x15, // CLOCK Counter Value
    TDC_ADR_TIME4                  = 0x16, // Measured Time 4
    TDC_ADR_CLOCK_COUNT4           = 0x17, // CLOCK Counter Value
    TDC_ADR_TIME5                  = 0x18, // Measured Time 5
    TDC_ADR_CLOCK_COUNT5           = 0x19, // CLOCK Counter Value
    TDC_ADR_TIME6                  = 0x1A, // Measured Time 6
    TDC_ADR_CALIBRATION1           = 0x1B, // Calibration 1, 1 CLOCK Period
    TDC_ADR_CALIBRATION2           = 0x1C, // Calibration 2, 2/10/20/40 CLOCK Periods
    TDC_ADR_AMOUNT // Amount of registers
} TDC_adr_t;

/**
 * @brief Register sizes of the TDC
 *
 * Index = Register address (TDC_adr_t)
 * Value = Register size (in bytes)
 *
 */
extern const uint8_t TDC_REG_SIZE[TDC_ADR_AMOUNT];

/**
 * @brief Bit description of the TDC CONFIG1 register
 *
 */
typedef enum {
    TDC_CONFIG1_FORCE_CAL_OFF   = (0b0 << 7), // Calibration is not performed after interrupted measurement (for example, due to counter overflow or missing STOP signal)
    TDC_CONFIG1_FORCE_CAL_ON    = (0b1 << 7), // Calibration is always performed at the end (for example, after a counter overflow)
    TDC_CONFIG1_PARITY_EN_OFF   = (0b0 << 6), // Parity bit for Measurement Result Registers disabled (Parity Bit always 0)
    TDC_CONFIG1_PARITY_EN_ON    = (0b1 << 6), // Parity bit for Measurement Result Registers enabled (Even Parity)
    TDC_CONFIG1_TRIGG_EDGE_RISE = (0b0 << 5), // TRIGG is output as a Rising edge signal
    TDC_CONFIG1_TRIGG_EDGE_FALL = (0b1 << 5), // TRIGG is output as a Falling edge signal
    TDC_CONFIG1_STOP_EDGE_RISE  = (0b0 << 4), // Measurement is stopped on Rising edge of STOP signal
    TDC_CONFIG1_STOP_EDGE_FALL  = (0b1 << 4), // Measurement is stopped on Falling edge of STOP signal
    TDC_CONFIG1_START_EDGE_RISE = (0b0 << 3), // Measurement is started on Rising edge of START signal
    TDC_CONFIG1_START_EDGE_FALL = (0b1 << 3), // Measurement is started on Falling edge of START signal
    TDC_CONFIG1_MEAS_MODE_1     = (0b00 << 1), // Measurement Mode 1 (for expected time-of-flight < 500 ns).
    TDC_CONFIG1_MEAS_MODE_2     = (0b01 << 1), // Measurement Mode 2 (recommended)
    TDC_CONFIG1_START_MEAS      = (0b1 << 0),  // Start New Measurement. Writing a 1 will clear all bits in the Interrupt Status Register and Start the measurement (by generating an TRIGG signal) and will reset the content of all Measurement Results registers
} TDC_config1_t;

/**
 * @brief Bit description of the TDC CONFIG2 register
 *
 */
typedef enum {
    TDC_CONFIG2_CALIBRATION2_PERIODS_2  = (0b00 << 6),  // Measuring 2 CLOCK periods
    TDC_CONFIG2_CALIBRATION2_PERIODS_10 = (0b01 << 6),  // Measuring 10 CLOCK periods
    TDC_CONFIG2_CALIBRATION2_PERIODS_20 = (0b10 << 6),  // Measuring 20 CLOCK periods
    TDC_CONFIG2_CALIBRATION2_PERIODS_40 = (0b11 << 6),  // Measuring 40 CLOCK periods
    TDC_CONFIG2_AVG_CYCLES_1            = (0b000 << 3), // 1 Measurement Cycle only (no Multi-Cycle Averaging Mode)
    TDC_CONFIG2_AVG_CYCLES_2            = (0b001 << 3), // 2 Measurement Cycles
    TDC_CONFIG2_AVG_CYCLES_4            = (0b010 << 3), // 4 Measurement Cycles
    TDC_CONFIG2_AVG_CYCLES_8            = (0b011 << 3), // 8 Measurement Cycles
    TDC_CONFIG2_AVG_CYCLES_16           = (0b100 << 3), // 16 Measurement Cycles
    TDC_CONFIG2_AVG_CYCLES_32           = (0b101 << 3), // 32 Measurement Cycles
    TDC_CONFIG2_AVG_CYCLES_64           = (0b110 << 3), // 64 Measurement Cycles
    TDC_CONFIG2_AVG_CYCLES_128          = (0b111 << 3), // 128 Measurement Cycles
    TDC_CONFIG2_NUM_STOP_1              = (0b000 << 0), // Single Stop
    TDC_CONFIG2_NUM_STOP_2              = (0b001 << 0), // Two Stops
    TDC_CONFIG2_NUM_STOP_3              = (0b010 << 0), // Three Stops
    TDC_CONFIG2_NUM_STOP_4              = (0b011 << 0), // Four Stops
    TDC_CONFIG2_NUM_STOP_5              = (0b100 << 0), // Five Stops
} TDC_config2_t;

/**
 * @brief Bit description of the TDC INT_STATUS register
 *
 */
typedef enum {
    TDC_STATUS_MEAS_COMPLETE_FLAG  = (1 << 4), // Measurement has completed
    TDC_STATUS_MEAS_STARTED_FLAG   = (1 << 3), // Measurement has started (START signal received)
    TDC_STATUS_CLOCK_CNTR_OVF_INT  = (1 << 2), // Clock overflow detected, running measurement will be stopped immediately
    TDC_STATUS_COARSE_CNTR_OVF_INT = (1 << 1), // Coarse overflow detected, running measurement will be stopped immediately
    TDC_STATUS_NEW_MEAS_INT        = (1 << 0), // Interrupt detected - New Measurement has been completed
} TDC_status_t;

/**
 * @brief Bit description of the TDC INT_MASK register
 *
 */
typedef enum {
    TDC_MASK_CLOCK_CNTR_OVF_MASK_OFF  = (0 << 2), // CLOCK Counter Overflow Interrupt disabled
    TDC_MASK_CLOCK_CNTR_OVF_MASK_ON   = (1 << 2), // CLOCK Counter Overflow Interrupt enabled
    TDC_MASK_COARSE_CNTR_OVF_MASK_OFF = (0 << 1), // Coarse Counter Overflow Interrupt disabled
    TDC_MASK_COARSE_CNTR_OVF_MASK_ON  = (1 << 1), // Coarse Counter Overflow Interrupt enabled
    TDC_MASK_NEW_MEAS_MASK_OFF        = (0 << 0), // New Measurement Interrupt disabled
    TDC_MASK_NEW_MEAS_MASK_ON         = (1 << 0), // New Measurement Interrupt enabled
} TDC_mask_t;

/**
 * @brief Error codes of the TDC module
 *
 */
typedef enum {
    TDC_OK = 0,
    TDC_ERROR,
    TDC_WRONG_ADDRESS,
    TDC_WRONG_SIZE,
    TDC_COM_ERROR,
} TDC_error_t;
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

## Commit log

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2024-12-18 [docs] initial latex setup incl. some examples
    [example.csv]
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2024-12-19 [hardware] initial commit containing KiCad project (schematics, layout and example library)
    [diy_tof_hw.kicad_pcb, diy_tof_hw.kicad_sch]
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2024-12-21 [hardware] wip - added two new schematics for better hierarchy, started to place power input plugs and power selection jumpers
    [diy_tof_hw.kicad_pcb, diy_tof_hw.kicad_sch, optoelectronics.kicad_sch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]
2024-12-22 [hardware] drawn initial version of the power / nucleo sheet
    [diy_tof_hw.kicad_sch, pwr_nucleo.kicad_sch]
2024-12-22 [hardware] added schematics and library components for the laser driver as well as TIA circuit
    [diy_tof_hw.kicad_pcb, diy_tof_hw.kicad_sch, optoelectronics.kicad_sch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]
2024-12-22 [hardware] added some missing footprints. Generated a footprint for the qioptiq mount
    [diy_tof_hw.kicad_pcb, optoelectronics.kicad_sch, pwr_nucleo.kicad_sch]
2024-12-24 [hardware] cherry picked changes from review
    [hardware] add description text for JP3
    (cherry picked from commit 44d5712227eb7a57076d25d490ffb1ca2a138412)
    [hardware] use relative path for schematics template
    (cherry picked from commit 5e7c5f0f6d85de52cfba936180bf5f2080214473)
    [hardware] use explicit path to STEP files for U1, IC1, IC2, IC21, IC22
    (cherry picked from commit 2ea5c7e3506b8eddbb4935cb7e42b338c20b0635)
    [diy_tof_hw.kicad_pcb, pwr_nucleo.kicad_sch]
2024-12-24 [hardware, firmware] various review findings - added new signals TDC_opt/ele_enable - fixed placement and appearance of the optics mount - added switch for stop signal of the electrical TDC - replace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
    [diy_tof_hw.kicad_pcb, diy_tof_hw.kicad_sch, optoelectronics.kicad_sch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]
2024-12-24 [hardware] renamed sheet "pwr_nucleo" to "pwr_nucleo_tdc"
    [diy_tof_hw.kicad_sch, pwr_nucleo_tdc.kicad_sch]
2024-12-24 [hardware] added various testpoints, some minor other fixes on the layout (designators)
    [diy_tof_hw.kicad_pcb, optoelectronics.kicad_sch, pwr_nucleo_tdc.kicad_sch]
2024-12-24 [hardware] added VCSEL, photodiode and some pcb graphics to the project
    [diy_tof_hw.kicad_pcb, optoelectronics.kicad_sch]
2024-12-24 [hardware] updating 3D models again
    [diy_tof_hw.kicad_pcb]
2024-12-24 [hardware] added mounting holes, reannotated some caps, started placement of the TIA part
    [diy_tof_hw.kicad_pcb, optoelectronics.kicad_sch, pwr_nucleo_tdc.kicad_sch]
2024-12-25 [hardware] added missing TP20
    [pwr_nucleo_tdc.kicad_sch]
2024-12-25 [hardware/minor] move blocks on 2nd schematic page a bit
    This is to be able to take PDF excerps for documenation without overlap with the page header.
    [optoelectronics.kicad_sch]
2024-12-25 [hardware/minor] added title for optoelectronics schematic page
    [optoelectronics.kicad_sch]
2024-12-25 [docs] remove examples from template
    [example.csv]
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2024-12-25 [docs] added BOM
    [bom.csv]
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2024-12-26 [docs] added more references of components
    [bom.csv]
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2024-12-27 [hardware] placed all components, some minor renaming (got rid of the "+" in front of all source-labels)
    [diy_tof_hw.kicad_pcb, pwr_nucleo_tdc.kicad_sch]
2024-12-27 [hardware] initial version of the PCB layout
    [diy_tof_hw.kicad_pcb, optoelectronics.kicad_sch]
2024-12-27 [hardware] changed footprint of R25 to 0603, updated some ICs footprint models in order to comply with e.g. via hole size constraints
    [diy_tof_hw.kicad_pcb, optoelectronics.kicad_sch]
2024-12-27 [hardware] review findings - moved powerplanes to layer In1 - added ground planes on all other layers - rerouting of signals around the nucleo board, leaving enough space for ground fills
    [diy_tof_hw.kicad_pcb, pwr_nucleo_tdc.kicad_sch]
2024-12-27 [hardware] further review findings - adjusted some more traces - one via per power pad - added caps for a pi filter (dnp) - added pullups for the CS signals of both TDCs
    [diy_tof_hw.kicad_pcb, optoelectronics.kicad_sch, pwr_nucleo_tdc.kicad_sch]
2024-12-27 [hardware] enlarged planes so that the PCB won't be produced with asymmetric copper planes - also added gerber output job
    [diy_tof_hw.kicad_pcb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]
2024-12-27 [hardware] minor plane adjustments, removed a connection which is done via plane
    [diy_tof_hw.kicad_pcb]
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2024-12-27 [docs] updated BOM based on recent changes in KiCAD
    [bom.csv]
2024-12-27 [hardware/minor] add value for optic mountings
    [diy_tof_hw.kicad_pcb, optoelectronics.kicad_sch]
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2025-01-10 [hardware] release v1.0
    [diy_tof_hw.kicad_sch, optoelectronics.kicad_sch, pwr_nucleo_tdc.kicad_sch]
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2025-01-12 [docs] added chapter "Elektrische Messungen / Unterschiedliche Kabellängen"
    [different_cable_lengths.csv, different_cable_lengths_calc.csv]
2025-01-12 [docs] added chapter "Elektrische Messungen / Mode 1 vs. Mode 2"
    [mode1_vs_mode2.csv]
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2025-01-15 [docs] no need to use sub-ps resolution
    THe TDC has 55~ps resolution. No need to use sub-ps resolution in docs.
    [different_cable_lengths.csv, different_cable_lengths_calc.csv, mode1_vs_mode2.csv]
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2025-01-15 [docs] added chapter "Elektrische Messungen / Unterschiedliche Clock-Konfigurationen"
    [different_clock_sources.csv]
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2025-01-17 [docs] review findings - some more correctures in various formulas - recalculated output power of the LD in both scenarios - better formulations + some typos fixed - better TIA schematics -> thanks T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
2025-01-17 [firmware] setup TIM1 channel 1 and 4 (start/stop ele) in order to do future measurements with less jitter
    [DIY_ToF.ioc, main.h]
2025-01-17 [firmware] changed timer mode to one pulse mode - timer runs for 1.4ms, therefore the measurement loop delay was shortened to 2 ms
    [DIY_ToF.ioc]
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2025-01-18 [docs] recalculated optical power and light current more accurately, fixed a reference in the concept chapter - some formulations changed in the "Layout" sub sub chapter
2025-01-18 [docs] added chapter "Messungen / Optische Messungen / ToF-Messungen via Spiegel"
    [spiegel_unterschiedliche_distanzen.csv]
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2025-01-19 [docs] added chapter "Messungen / Elektrische Messungen / Unterschiedliche Kabellängen mit DSO"
    [different_cable_lengths_with_dso_dso.csv, different_cable_lengths_with_dso_tdc.csv, different_cable_lengths_with_dso_theorie.csv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]
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2025-01-20 [docs] moved documentation into subdirectory to make space for upcoming presentation
    [bom.csv, different_cable_lengths.csv, different_cable_lengths_calc.csv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]
2025-01-20 [docs/presentation] initial commit based on template
    [example.csv]
2025-01-20 [docs/presentation] removed all unneeded stuff from template
    [example.csv]
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

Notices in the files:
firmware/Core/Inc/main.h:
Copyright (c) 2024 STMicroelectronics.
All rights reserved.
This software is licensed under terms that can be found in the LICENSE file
